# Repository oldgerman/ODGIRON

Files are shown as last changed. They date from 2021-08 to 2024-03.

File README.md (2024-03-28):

# ODGIRON

## 关于

> 这是一个很久以前的项目，也是我刚学习stm32做的第一个项目，仅给老友们发车了10个套件，现将其所有软硬件资料开源
>
> Github仓库链接：https://github.com/oldgerman/ODGIRON

开源USB-C PD T12电烙铁，基于HAL库开发，STM32CubeIDE + STM32CubeMX

固件从 [ironOS](https://github.com/Ralim/IronOS) 修改而来，运行FreeRTOS，更换了主控，重新设计了主界面和多级菜单，更大的oled显示屏，分辨率128x32

双面板设计，电阻电容最小0603封装，焊接难度比0402小

前期准备几乎兼容所有QFN48、RAM ≥ 20KB、FLASH ≥ 128KB 的STM32芯片，但后期发现 F103 固件写不下了遂停止维护，主力适配 F401，当然如果你有能力，可自行移植到其他型号上

## 技术大纲

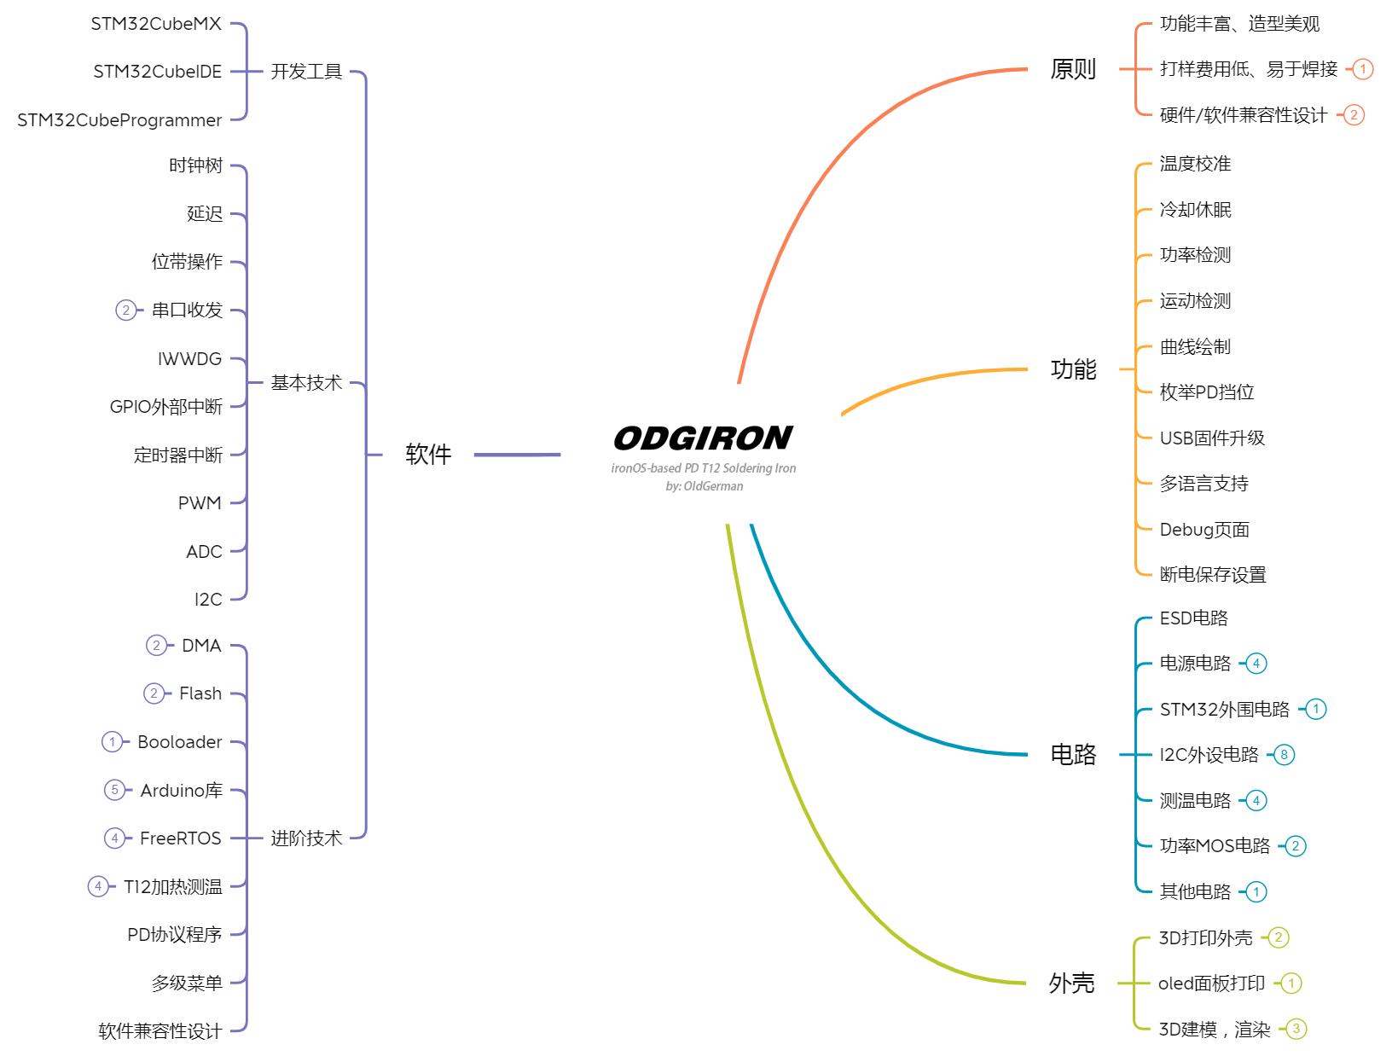
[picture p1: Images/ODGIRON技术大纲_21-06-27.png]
ODGIRON技术大纲_21-06-27


## 成品

ODGIRON（1）

## 硬件

### 配置

- 主控：STM32F103CBU6、STM32F401CCU6
- 屏幕：0.87inch OLED，SSD1316 分辨率128x32
- PD协议芯片：FUSB302B
- 加速度计：LIS3DH
- 功率计：INA226
- 电源管理：MP2456 + LDO 3.3V
- 温度测量：SGM8551 + MCP9700AT
- 功率MOS：AON7403（-30V/-29A）*2
- 外壳：尼龙3D打印

### PCB

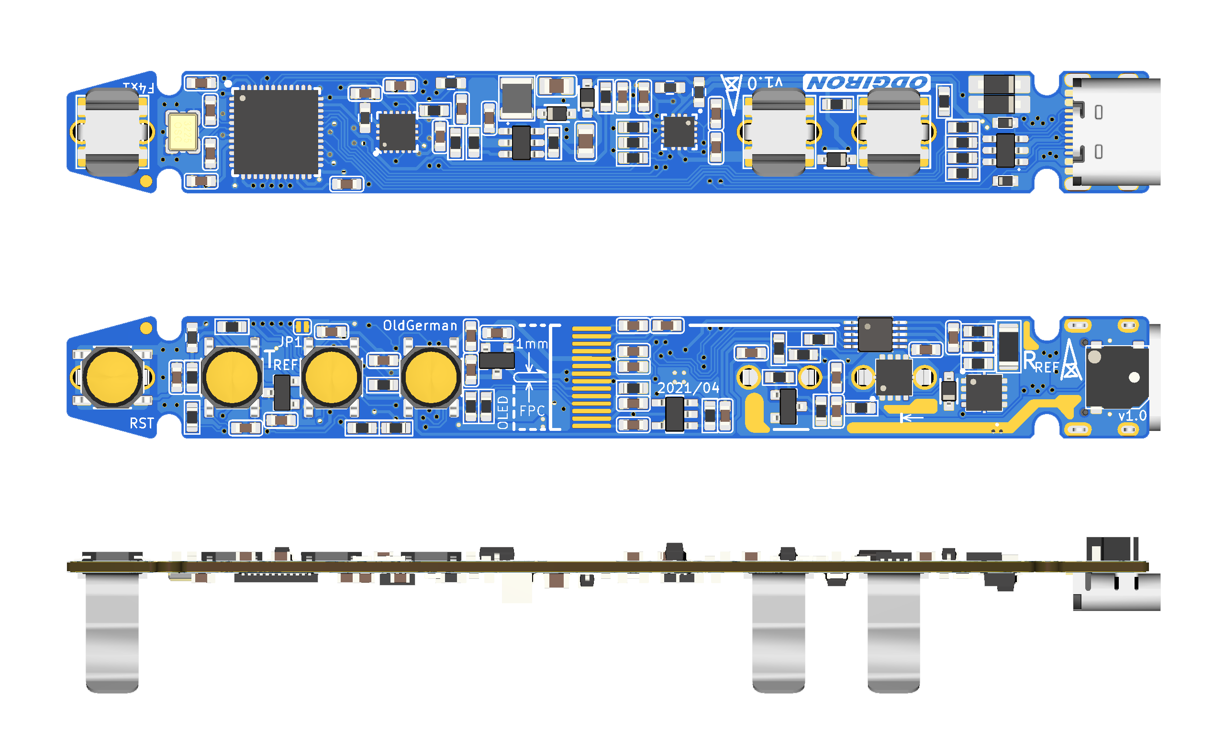
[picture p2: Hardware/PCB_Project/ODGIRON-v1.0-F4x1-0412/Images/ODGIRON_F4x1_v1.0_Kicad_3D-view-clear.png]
ODGIRON_F4x1_v1.0_Kicad_3D-view-clear


### 原理图

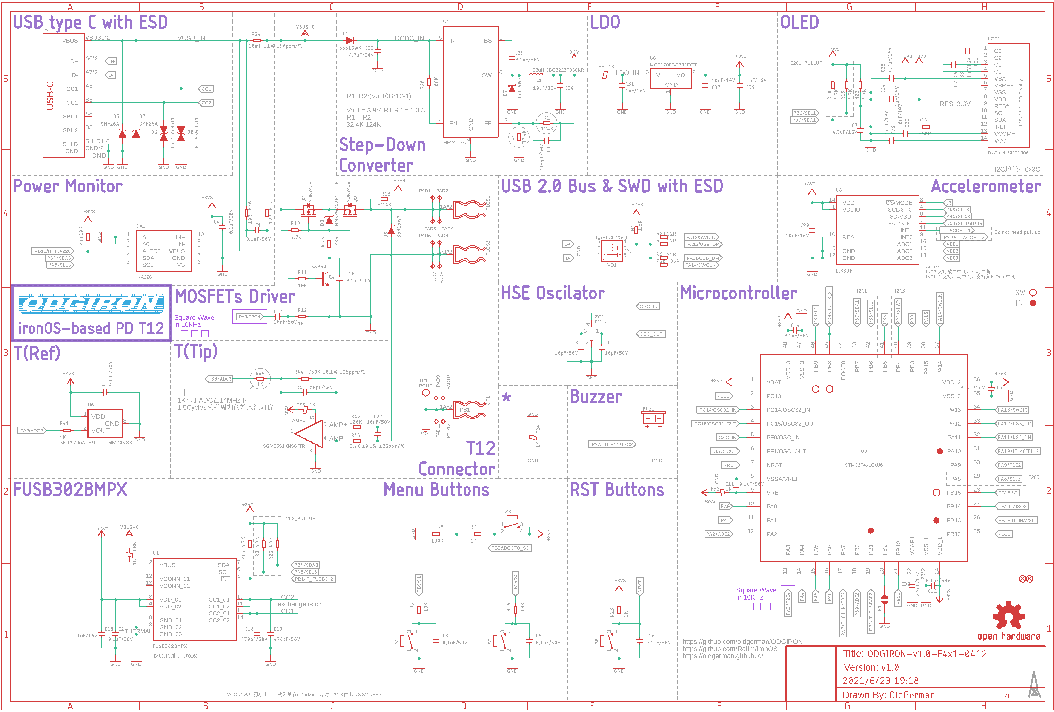
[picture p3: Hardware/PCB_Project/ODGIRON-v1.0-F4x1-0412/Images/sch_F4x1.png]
sch_F4x1


### 外壳

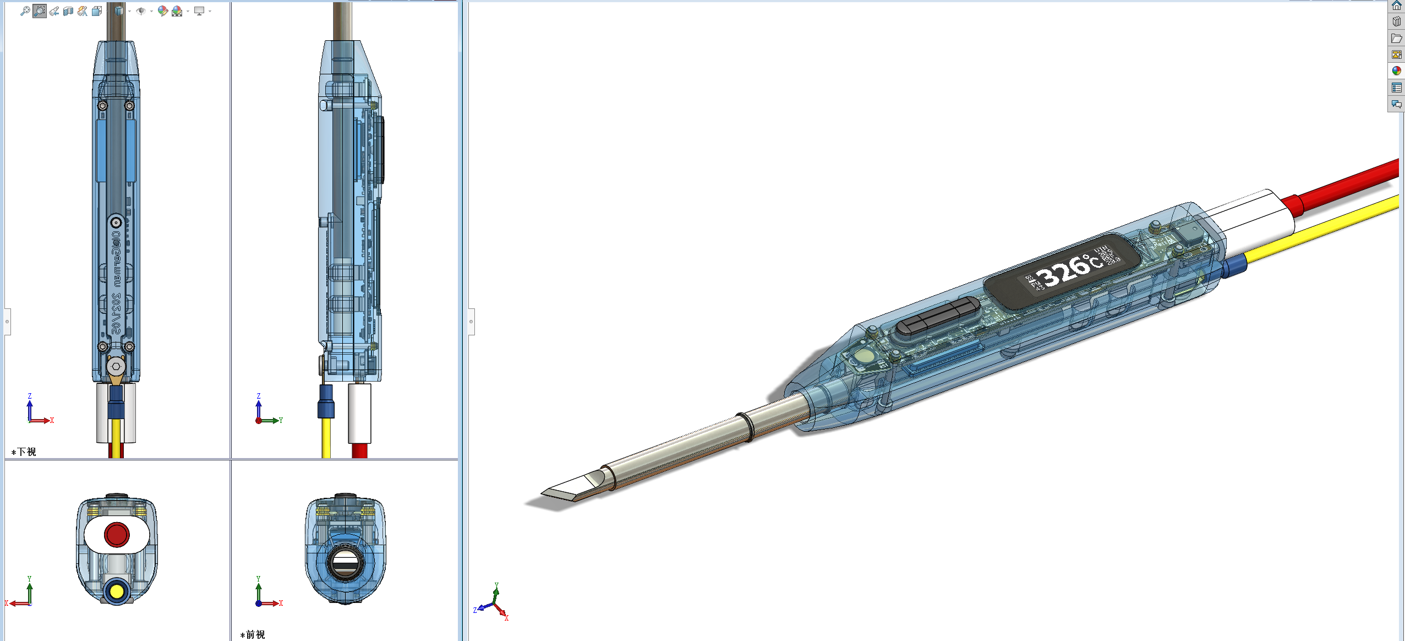
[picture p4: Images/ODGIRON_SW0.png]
ODGIRON_SW0


## 软件

[固件版本更新日志](https://github.com/oldgerman/ODGIRON/blob/master/Notes/firmware_logs.md)

[固件升级方法](https://github.com/oldgerman/ODGIRON/blob/master/Notes/firmware_upgrade.md)

### 功能

- :heavy_check_mark:功率计

- :heavy_check_mark:自动休眠、运动唤醒

- :heavy_check_mark:温度功率曲线绘制

- :heavy_check_mark:USB固件升级

- :heavy_check_mark:多级菜单（可配置的参数太多，只列举几个）

  - 温度校准
  - 冷却休眠
  - 枚举PD挡位
  - ...

- :heavy_check_mark:断电保存设置

- 待开发

  - 多语言支持（目前仅支持中文）

  - ...

### BUG

ADC注入通道测量尖端的温度：STM32F401CCU6偶尔会向上抖动10度，同样的代码在STM32F103CBU6跑却很稳定，可能是ADC时钟频率、采样周期、转换周期不同导致，目前整不好了，但影响不大:)

## 致谢

> 感谢[@Miniware](http://www.miniware.com.cn/)开源的[TS100资料](http://www.minidso.com/forum.php?mod=viewthread&tid=892)
>
> 感谢[@Ralim](https://github.com/Ralim)开发的[ironOS](https://github.com/Ralim/IronOS)
>
> 感谢[@olikraus](https://github.com/olikraus)开发的[u8g2](https://github.com/olikraus/u8g2)
>
> 感谢[@Zanduino](https://github.com/Zanduino)开发的[INA](https://github.com/Zanduino/INA)

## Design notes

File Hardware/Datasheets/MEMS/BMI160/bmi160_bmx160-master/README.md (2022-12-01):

# BMI160 / BMX160

## 简介

本软件包是为 BOSCH BMI160 6轴传感器以及 BMX160 9轴传感器提供的通用传感器驱动包。

本驱动软件包会检测所连接传感器的ID从而自动配置为BMI160或者BMX160的驱动，无须用户手动选择。

本文档介绍该软件包的基本功能和使用方法，本文主要内容如下：

- 传感器介绍
- 支持情况
- 使用说明

## 传感器介绍

BMI160 是 BOSCH（博世）公司专为可穿戴设备和 IOT 市场开发的一款超低功耗6轴传感器，尺寸小巧，内置加速计和陀螺仪。

BMX160 是 BOSCH（博世）公司专为可穿戴设备和 IOT 市场开发的一款超低功耗9轴传感器，内置加速计、陀螺仪和磁力计。

## 支持情况

| 包含设备 | 加速计 | 陀螺仪 | 磁力计 |
| --- | --- | --- | --- |
| **通讯接口** | | | |
| IIC | √ | √ | √ |
| SPI | | | |
| **工作模式** | | | |
| 轮询 | √ | √ | √ |
| 中断 | √ | √ | √ |
| FIFO | √ | √ | √ |
| **电源模式** | | | |
| 掉电 | √ | √ | √ |
| 低功耗 | √ | | √ |
| 普通 | √ | √ | √ |
| 高功耗 | | | |
| **数据输出速率** | √ | √ | √ |
| **测量范围** | √ | √ | |
| **自检** | | | |
| **多实例** | √ | √ | √ |

## 使用说明

### 依赖

- RT-Thread 4.0.0+
- Sensor 组件
- IIC 驱动：BMI160 / BMX160 设备使用 IIC 进行数据通讯，需要系统 IIC 驱动框架支持；

### 获取软件包

使用 BMI160/BMX160 软件包需要在 RT-Thread 的包管理中选中它，具体路径如下：

```
BMI160: BMI160 Digital 6-axis / BMX160 Digital 9-axis sensor
    [*]   Enable BMI160 / BMX160 accelerometer
    [*]   Enable BMI160 / BMX160 gyroscope
    [*]   Enable BMX160 magnetometer
        Version (latest)  --->
```

**Enable BMI160 accelerometer**： 配置开启加速度测量功能

**Enable BMI160 gyroscope**：配置开启陀螺仪功能

**Enable BMI160 magnetometer**：配置开启磁力计功能（只有BMX160支持磁力计）

**Version**：软件包版本选择

### 使用软件包

BMA400 软件包初始化函数如下所示：

```
int rt_hw_bmx160_init(const char *name, struct rt_sensor_config *cfg);
```

`rt_hw_bmx160_init`函数需要由用户调用，函数主要完成的功能有，

- 设备配置和初始化（根据传入的配置信息，配置接口设备和中断引脚）；
- 注册相应的传感器设备，完成 BMI160 / BMX160 设备的注册；

BMI160和BMX160共用一个驱动，当程序检测到传感器芯片ID为BMI160时会注册加速计和陀螺仪的驱动程序，如果ID为BMX160还会加载磁力计的驱动程序。如果你只需要某些特定的传感器，请到`menuconfig`菜单中进行配置。

#### 初始化示例

```
#include "sensor_bosch_bmx160.h"

int bmx160_port(void)
{
    struct rt_sensor_config cfg;
    cfg.intf.dev_name = "i2c1";
    cfg.intf.user_data = (void *)0x69;
    cfg.irq_pin.pin = GET_PIN(B, 0);
    cfg.irq_pin.mode = PIN_MODE_INPUT_PULLDOWN;
    rt_hw_bmx160_init("bmx160", &cfg);
    return 0;
}
INIT_APP_EXPORT(bmx160_port);
```

## 注意事项

暂无

## 联系人信息

维护人:

- [gztss](https://github.com/gztss)

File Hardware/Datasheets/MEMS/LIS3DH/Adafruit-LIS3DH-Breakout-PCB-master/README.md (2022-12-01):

## Adafruit LIS3DH Triple-Axis Accelerometer (+-2g/4g/8g/16g) PCB
<a href="http://www.adafruit.com/products/2809"><br/>
Click here to purchase one from the Adafruit shop</a>

The LIS3DH is a very popular low power triple-axis accelerometer. It's low-cost, but has just about every 'extra' you'd want in an accelerometer:

3.3V regulator + level shifting, so you can safely use with any Arduino or microcontroller without the need for an external level shifter!
We kept seeing this accelerometer in teardowns of commercial products and figured that if it's the most-commonly used accelerometer, its worth having a breakout board!

This sensor communicates over I2C or SPI (our library code supports both) so you can share it with a bunch of other sensors on the same I2C bus. There's an address selection pin so you can have two accelerometers share an I2C bus.

To get you going fast, we spun up a custom made PCB in the STEMMA QT form factor, making them easy to interface with. The STEMMA QT connectors on either side are compatible with the SparkFun Qwiic I2C connectors. This allows you to make solderless connections between your development board and the LIS331s or to chain them with a wide range of other sensors and accessories using a compatible cable. We’ve of course broken out all the pins to standard headers and added a voltage regulator and level shifting so allow you to use it with either 3.3V or 5V systems such as the Raspberry Pi + Feather series or Arduino Uno respectively.

PCB files for the Adafruit LIS3DH Breakout. The format is EagleCAD schematic and board layout
- https://www.adafruit.com/product/2809

### License

Adafruit invests time and resources providing this open source design, please support Adafruit and open-source hardware by purchasing products from [Adafruit](https://www.adafruit.com)!

All text above must be included in any redistribution

Designed by Limor Fried/Ladyada for Adafruit Industries.
Creative Commons Attribution/Share-Alike, all text above must be included in any redistribution. 
See license.txt for additional information.

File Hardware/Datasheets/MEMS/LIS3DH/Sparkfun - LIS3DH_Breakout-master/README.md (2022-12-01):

SparkFun Triple Axis Accelerometer Breakout - LIS3DH
=============================================

SparkFun Triple Axis Accelerometer Breakout - LIS3DH  

[*SparkFun Triple Axis Accelerometer Breakout - LIS3DH(SEN-13963)*](https://www.sparkfun.com/products/13963)

This breakout board makes it easy to use the tiny LIS3DH accelerometer in your project. 
The LIS3DH is a smart low-power, three-axis, capacitive micro-machined accelerometer with 12 bits of resolution.

This product replaced the MMA-8452Q.

Repository Contents
-------------------
* **/Hardware** - All Eagle design files (.brd, .sch)
* **/Libraries** - Libraries for use with the <PRODUCT NAME>
* **/Production** - Production panel files (.brd)

Documentation
--------------
* **[Library](https://github.com/sparkfun/SparkFun_LIS3DH_Arduino_Library)** - Arduino library.
* **[Hookup Guide](https://learn.sparkfun.com/tutorials/lis3dh-hookup-guide)** - Basic hookup guide.
* **[SparkFun Fritzing repo](https://github.com/sparkfun/Fritzing_Parts)** - Fritzing diagrams for SparkFun products.
* **[SparkFun 3D Model repo](https://github.com/sparkfun/3D_Models)** - 3D models of SparkFun products. 
* **[SparkFun Graphical Datasheets](https://github.com/sparkfun/Graphical_Datasheets)** -Graphical Datasheets for various SparkFun products.

Version History
---------------
* [V_0.1](https://github.com/sparkfun/LIS3DH_Breakout/tree/V_0.1) - Prototype
* [V_H1.0_L1.0.0](https://github.com/sparkfun/LIS3DH_Breakout/tree/V_H1.0_L1.0.0) - Hardware version 1.0, library version 1.0.0. 

License Information
-------------------

This product is _**open source**_! 

Please review the LICENSE.md file for license information. 

If you have any questions or concerns on licensing, please contact techsupport@sparkfun.com.

Distributed as-is; no warranty is given.

- Your friends at SparkFun.

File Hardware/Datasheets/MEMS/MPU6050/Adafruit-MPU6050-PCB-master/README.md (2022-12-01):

## Adafruit MPU6050 6-DoF Accelerometer and Gyro PCB

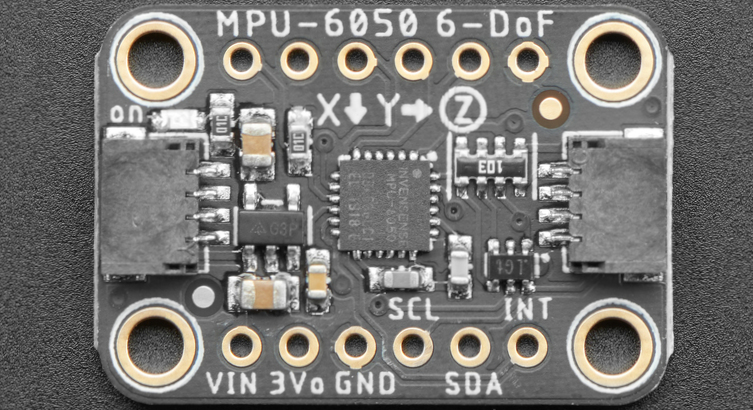
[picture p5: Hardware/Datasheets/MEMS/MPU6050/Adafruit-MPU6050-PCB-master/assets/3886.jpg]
<a href="http://www.adafruit.com/products/3886"><br/>
Click here to purchase one from the Adafruit shop</a>

PCB files for the Adafruit MPU6050 6-DoF Accelerometer and Gyro. 

Format is EagleCAD schematic and board layout
* https://www.adafruit.com/product/3886

### Description

The MPU-6050 is a popular six DoF accelerometer and gyroscope (gyro) that has all the info you need on how things are shakin' and spinnin' . With six axes of sensing and 16-bit measurements, you'll have everything you need to give your robot friend an inner ear.

This combination of gyroscopes and accelerometers is commonly referred to as an **I**nertial **M**easurement **U**nit or IMU. Not so long ago IMUs were the [size of a breadbox](http://mentalfloss.com/article/55835/how-big-breadbox) and cost upwards of **$50,000!** While you're not going to be using it to guide your mars rocket, the MPU-6050 is several orders of magnitude smaller and a bargain at a price three orders of magnitude less!  Now you can add telemetry to your [water rocket](https://en.wikipedia.org/wiki/Water_rocket) (with some waterproofing).

As with all Adafruit breakouts, we've done the work to make this handy temperature helper super easy to use. We've put it on a breakout board with the required support circuitry and connectors to make it easy to work with, and is now a trend we've added [SparkFun Qwiic](https://www.sparkfun.com/qwiic) compatible [STEMMA QT](https://learn.adafruit.com/introducing-adafruit-stemma-qt) JST SH connectors that allow you to get going without needing to solder. Just use a [STEMMA QT adapter cable](https://www.adafruit.com/product/4209), plug it into your favorite micro or Blinka supported SBC and you're ready to rock!

### License

Adafruit invests time and resources providing this open source design, please support Adafruit and open-source hardware by purchasing products from [Adafruit](https://www.adafruit.com)!

Designed by Bryan Siepert for Adafruit Industries.

Creative Commons Attribution/Share-Alike, all text above must be included in any redistribution. 
See license.txt for additional details.

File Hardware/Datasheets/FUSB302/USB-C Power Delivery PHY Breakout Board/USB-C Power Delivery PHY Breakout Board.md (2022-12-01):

# USB-C Power Delivery PHY Breakout Board

[FUSB302BGEVB：C型接口检测解决方案（FUSB302BGEVB）带tssop28 32位 128KB flash 32KB SRAM 50MHz主频位RISC MCU：PIC32MX250F128B-I/SS](https://www.terraelectronica.ru/rd/ONS/FUSB302BGEVB)

QC和PD是主流，特别是PD，后面应该会一统天下，我觉得这种私有协议别浪费时间研究

这个fusb302是不支持pd3.0对吧？手册好像没提

哦，找到了，是只有2.0

对，只支持2.0
你可以看FUSB307，今天问了价格和302基本一样，支持3.0

USB-C Power Delivery PHY Breakout Board 1

是否想使用新的USB Type-C连接器？您需要一个芯片来管理CC引脚。该板可让您使用I2C和中断线来执行所有必要的USB-C功能。该板的核心是Fairchild FUSB302，C型端口控制器和BMC PHY。您可以使用该芯片执行以下所有操作：
*确定插头方向（正常或反向）
*确定或公布C型功率水平（0.5 V，1.5、1.5或3.0 A时为5 V）
*使用BMC通信进行协商USB供电显式签约高达20 V和5 A（100 W功率）
*协商备用模式，以将Type-C连接器中的引脚复用用于其他目的

所有设计文件均可在GitHub上获得，并且是开源的。原理图，布局，gerber和示例代码在MIT风格的许可下可用。

你可以考虑FUSB307，支持PD3.0，问过价格比FUSB302贵1块钱，当然FUSB302对你来说也够用，PD3.0向下兼容

FUSB302 的目标用户为希望以较少的编程量实施 DRP/SRC/SNK USB Type-C 接头的系统设计人员。FUSB302 实现了 USB Type-C 检测，包括连接和定向。FUSB302 集成了 USB BMC 功率输送协议的物理层，可实现高达 100 W 的电源和角色互换。BMC PD 装置实现了对于符合 C 型规范的其他接口的完全支持。参考法规可用于 FUSB302 在若干嵌入控制器平台之间轻松实施 C 型 和 USB BMC 功率输送协议。单击下面的“软件”链接。

| 特性 | |
| :--- | ---- |
| | |
| 通过自主 DRP 切换实现双角色功能 | |
| 能够根据具体的连接，连接主机或设备。 | |
| 软件可配置为专用主机、专用设备或双角色 | |
| 专用设备可采用具有固定 CC 和 VCONN 通道的 Type-C 插座或 Type-C 插头运行。 | |
| 完全支持 Type-C 1.1。集成 CC 引脚的以下功能 | |
| 作为主机进行连接/断连检测 | |
| 作为主机进行电流性能指示 | |
| 作为设备进行电流性能检测 | |
| 音频适配器附件模式 | |
| 调试附件模式 | |
| 有源电缆检测 | |
| 将 CCx 集成到 VCONN 开关中，具有过流限制，支持 USB3.1 全功能数据线。 | |
| USB 电力传输 (PD) 2.0、版本 1.1 支持 | |
| 自动 GoodCRC 报文响应 | |
| 如果需要，自动软复位重新发送的报文 | |
| 如果未收到 GoodCRC，自动尝试重发报文 | |
| 电池电量耗尽支持（没有加电时的 SNK 模式支持） | |
| 自动硬复位发送的顺序集 | |
| 采用 9 焊球 WLCSP (1.215 mm x 1.260 mm) 和 14 引脚 MLP（2.5 mm x 2.5 mm，0.5 mm 节距）封装 | |
| 低功率运行：ICC = 25 μA（典型值） | |

| 应用                                                         |
| :----------------------------------------------------------- |
| This product is general usage and suitable for many different applications. |

### USB Type-C PD开发板

8个月前

- [电源模块](https://oshwhub.com/explore?filter=2613794836ff4fa2954e4cca5749584a)
- [方案验证板](https://oshwhub.com/explore?filter=90637fd096424071a21927e5cdc436de)
- [消费电子](https://oshwhub.com/explore?filter=e5831c441f25423d88a7311a9b276871)

简介：FUSB302B（C132291）控制器+INA226（C49851）电流检测，实现USB-PD协议，可以DIY线材检测器，充电器输出能力检测器等等。且集成了QC3.0手动诱骗电路，测试QC3.0功能

开源协议: GPL 3.0

https://oshwhub.com/wuziyue/USB-Type-C-PDkai-fa-ban

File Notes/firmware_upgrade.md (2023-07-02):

## 固件升级方法

### 【booloader】烧写

如果是全片擦除的芯片，那么请先用ST-LINK烧写“ODGIRON_bootloader_XXX.bin” ，这是booloader文件，只有烧进去了，才能用烙铁自带的USB Type-C口通过DFU升级APP文件，具体操作见下一步【APP】烧写

### 【APP】烧写

1. 安装Dfuse软件，ST的DFU驱动也要安装，win10系统请安装 “Dfuse文件安装路径/bin/Driver/Win7/X86”下的dpinst_x86.exe,[Dfuse下载链接](https://www.st.com/en/development-tools/stsw-stm32080.html)
2. 用USB将至少烧写了booloader程序的烙铁连接电脑，在启动的logo页面时，长按中键，可进入USB DFU升级模式的页面
3. 打开DfuseDemo软件，若检测到处于dfu模式的烙铁芯片，那么就查看“Product ID”栏内的数字，记下来
4. 用Dfuse软件安装时自带的小工具“Dfu file mananger”将“ODGIRON_APP_XXX.hex” 转成“*.dfu”文件升级，
   转之前先填刚才记下的“Product ID”，然后直接刷固件，升级之后请在菜单里 恢复出厂设置

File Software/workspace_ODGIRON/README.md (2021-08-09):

## 开发环境

本文件夹是使用STM32CubeIDE_1.7创建的workspace

使用Darkest Dark主题，未安装的STM32CubeIDE直接打开CDT编辑器的颜色会很奇怪，[推荐食用方式](https://blog.csdn.net/qq_42038029/article/details/99735688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)

## Link 文件夹路径丢失修复

由于本项目多个PROJECT_STM32XXX工程共用上级目录的源代码文件，而STM32CubeIDE似乎只能通过Link文件夹的方式让多个工程共享同一源代码文件，大家将本项目存放在自己电脑的位置又不一样，因此会存在Link 文件夹路径丢失无法正常编译的问题，解决方法如下：

打开代码PROJECT_STM32XXX工程文件夹下的.project文件，将字段`<location>`内的路径根据你实际存放的路径修改：

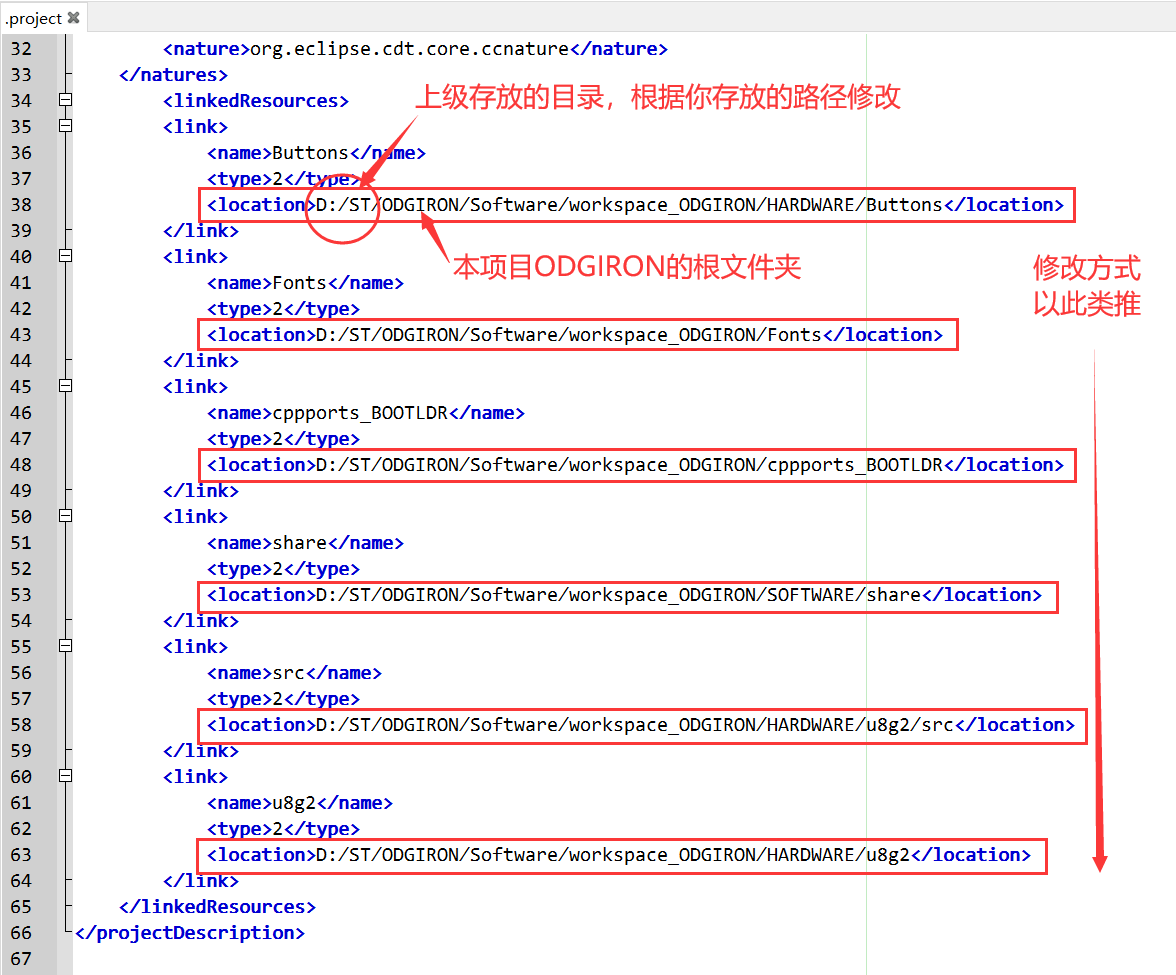
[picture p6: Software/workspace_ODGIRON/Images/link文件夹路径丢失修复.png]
link文件夹路径丢失修复


重新编译就OK了

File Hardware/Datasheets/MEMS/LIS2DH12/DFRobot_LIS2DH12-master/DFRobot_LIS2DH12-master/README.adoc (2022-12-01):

= DFRobot_LIS2DH12 Library for Arduino =

The library is used to read LIS2DH12 data via serial

/*!
 * @file testLIS2DH12.ino
 * @brief DFRobot's Read LIS2DH12 data
 * @n This example achieve receiving LIS2DH12  data via serial
 *
 * @copyright	[DFRobot](http://www.dfrobot.com), 2016
 * @copyright	GNU Lesser General Public License
 *
 * @author [Wuxiao](xiao.wu@dfrobot.com)
 * @version  V1.0
 * @date  2016-10-13
 * @https://github.com/DFRobot/DFRobot_LIS2DH12
 */

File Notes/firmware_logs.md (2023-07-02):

## 固件版本更新日志

> 由 过气德国佬 于 2022/04/27 18:01 最后一次编辑

### 日期：2022/04/27

#### APP部分固件更新

版本：ODGIRON_APP_2022-0427-1736.hex

新功能：

- 【温度控制】-->【温度失控保护】
  
  > 不论在<主页>、<曲线图页>、或是<菜单的校准页>涉及到加热时，当检测到烙铁温度长时间<低于>目标温度，会彻底关闭加热，这之后，只有在主页会显示“温度失控保护, 长按左右退出”的字样，可以长按左右键退出这个警告页面，继续正常加热。【温度失控保护】下有三个值可配置，分别是：启用失控保护（默认关闭）、温度失控阈值（默认10度）、触发保护时间（默认20秒）（之前的固件也有此功能但不可配置，只能重新上电才正常，而被怀疑是BUG）
  
- 【显示设置】-->【主页加热单位】

  > 对应主屏幕左下角的数字，之前是显示功率（单位是W但不打印），可以更改为 "瓦特"（W）或 "百分"（%），默认是瓦特。百分的范围是0~99%

### 日期：2022/04/24

#### APP部分固件更新
版本：ODGIRON_APP_2022-0424-1612.hex

新功能：

- 【温度校准】-->【设置目标温度】可开启或关闭，校准的目标温度支持调整

变化部分：

- 若【温度校准】-->【设置目标温度】关闭，则每个温度校准档位的目标温度是固定的默认值
- 若【温度校准】-->【设置目标温度】打开，则每个温度校准档位的目标温度是可调的，每次进入对应的温度校准档位都会显示目标温度调节页面（最低温度没有，因为是不加热的情况）。添加这个的原因的默认校准的最高目标温度是400度左右，对于一些娇贵的烙铁，这个温度容易挂掉，因此有必要将这个温度支持调低，然后其他档位也一并添加了目标温度可调的功能

### 日期：2022/04/04

> 此版本之后，APP固件更新不用捆绑升级DFU固件，解决DFU和APP的耦合

#### Bootloader部分固件更新
版本：ODGIRON_Booloader_2022-0404-1502.bin

变化部分：

- 插电之前，一直按住中键，再插电，才会进入DFU页面

#### APP部分固件更新

版本：ODGIRON_APP_2022-0404-1643.hex

修复的BUG：

- 【开机焊接】开启后，不起作用

- 菜单栏右侧的值不居中

新功能：

- 【显示设置】-->【开机显示图标】可开启或关闭

变化部分：

- 取消【辅助功能】-->【重启进入DFU】，但【重启】功能里选择OK后，依旧可以马上按中键进入DFU页面

### 日期：2022/04/03

#### Bootloader部分固件更新

版本：ODGIRON_Booloader_2022-0403-2222.bin

#### APP部分固件更新

版本：ODGIRON_APP_2022-0403-2222.hex

修复的BUG：

- 刷屏错位、乱码
- 温度稳定时突然升高
- 旧固件升级后，主界面温度一直为0，并持续最大功率加热

新功能：

- 【温控设置】

  > 其下级菜单有【比例系数】、【卡尔曼滤波器】、【目标温度正偏移】，这些值可以用默认值，也可自己调整

- 【温度校准】

  > 不受校准顺序影响，但最好从低温向高温校准，在每个温度档位的校准页面，可以用左右键调整校准的目标温度，按中键可退出温度档位校准，每个温度校准后，需要【保存校准数据】以计算校准的曲线，相关计算结果可在【查看校准数据】里查看，校准默认不开启，需要【启用校准数据】才会开启

变化部分：

- 菜单的按键操作发生了变化，长按左键返回上级菜单--变为--长按中键，
- 菜单新特性：支持菜单栏首尾循环，支持长按左键或右键快速递进

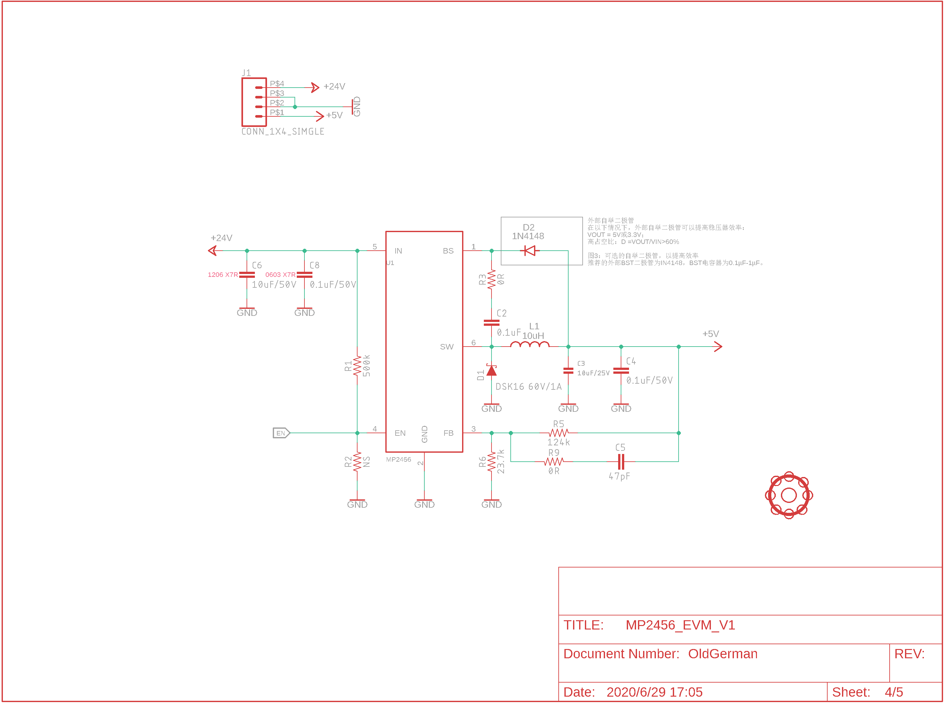
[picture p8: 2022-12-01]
Hardware/Datasheets/DCDC/image/Eagle_Sch.png

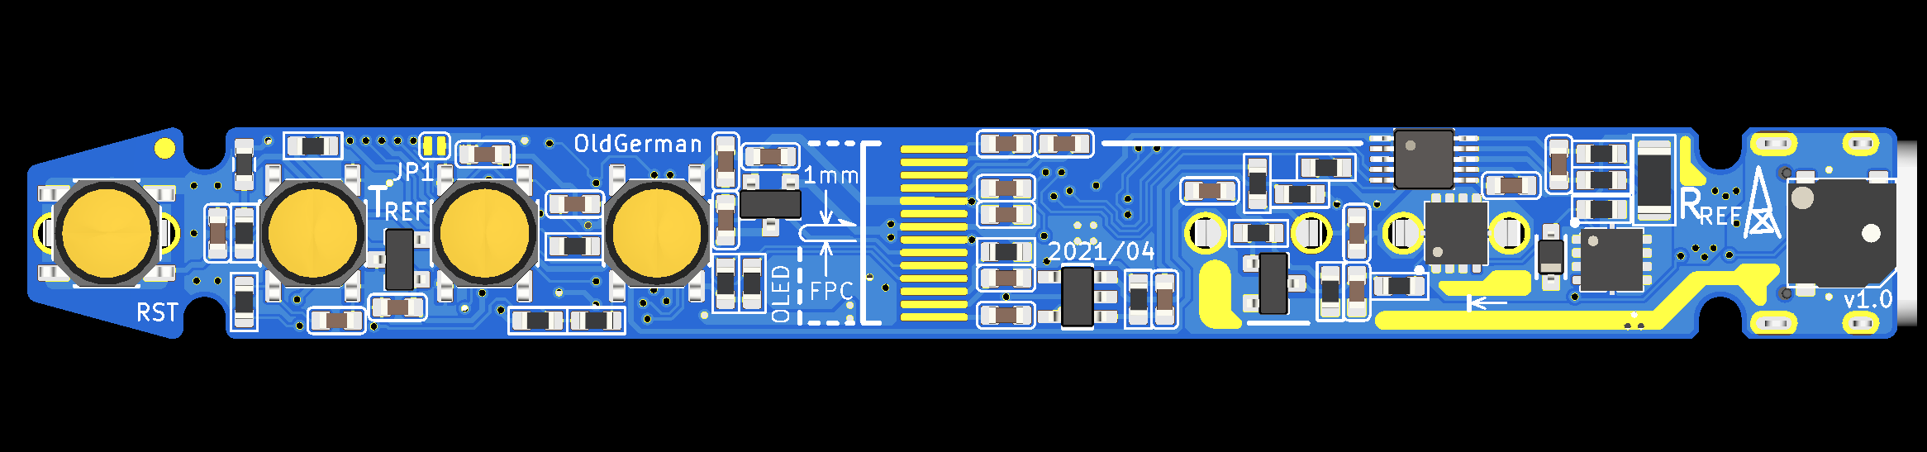
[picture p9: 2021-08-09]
Hardware/PCB_Project/ODGIRON-v1.0-F4x1-0412/Images/ODGIRON_F4x1_v1.0_Kicad_3D-view (5).png

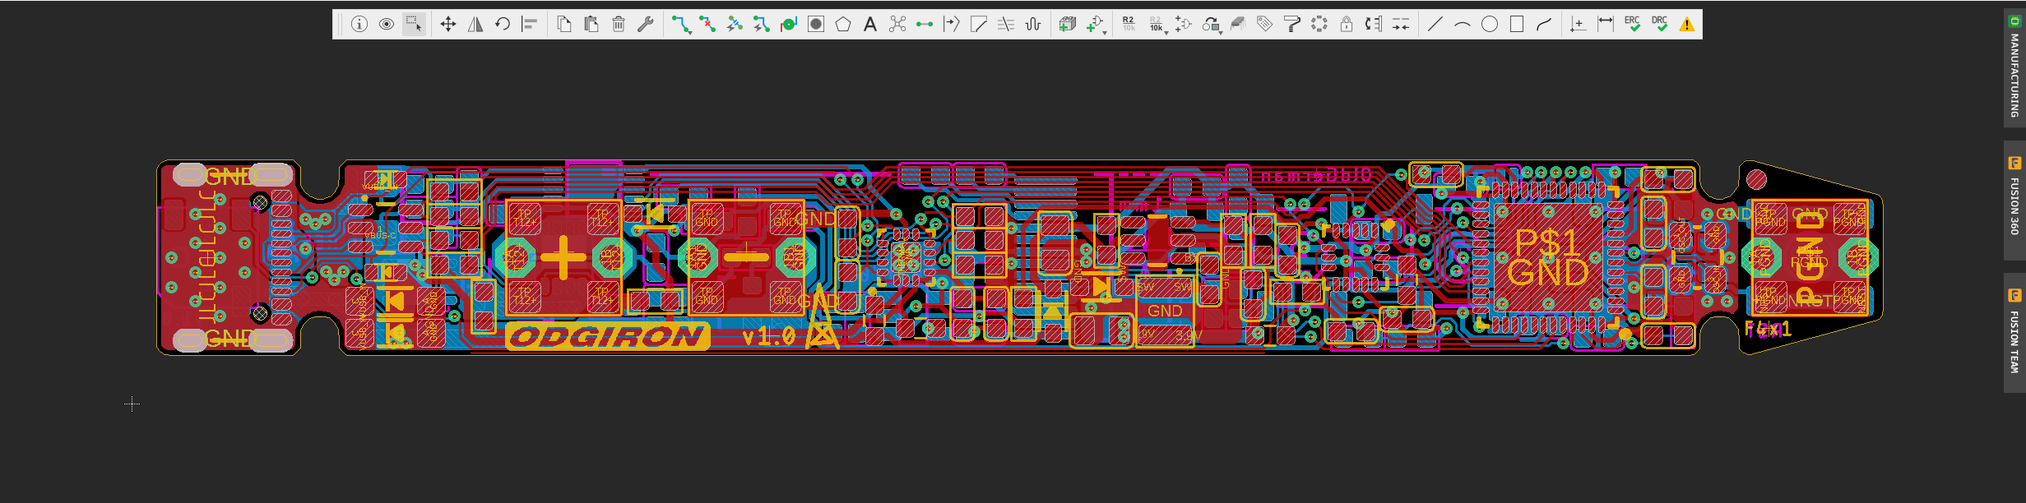
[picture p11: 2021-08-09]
Hardware/PCB_Project/ODGIRON-v1.0-F4x1-0412/Images/brd_F4x1.png

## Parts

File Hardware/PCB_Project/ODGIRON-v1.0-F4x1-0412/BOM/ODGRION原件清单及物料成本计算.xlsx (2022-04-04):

Type | Numbers | Detail | Package | Name | 最小起订量 | 起订量总价 | 单价 | 实际成本
精密低温漂电阻 | 1 | 10mR 1% 50ppm STE0805MW75R010F | R1206 | R24 | 10 | 3.27 | 0.327 | 0.327
 | 1 | 2.4K 0.1% 25ppm | R0603 | R43 | 20 | 2.6 | 0.13 | 0.13
 | 1 | 750K 0.1% 25ppm | R0603 | R44 | 20 | 2.6 | 0.13 | 0.13
1%电阻 | 2 | 10R | R0603 | R36, R37 | 100 | 1 | 0.01 | 0.02
 | 4 | 22R | R0603 | R5, R6, R27, R28 | 100 | 1 | 0.01 | 0.04
 | 5 | 1K | R0603 | R7, R12, R23, R41, R45 | 100 | 1 | 0.01 | 0.05
 | 1 | 1.5K | R0603 | R4 | 100 | 1 | 0.01 | 0.01
 | 8 | 4.7K | R0603 | R3, R10, R16, R18, R19, R22, R25, R35 | 100 | 1 | 0.01 | 0.08
 | 4 | 10K | R0603 | R9, R11, R14, R38 | 100 | 1 | 0.01 | 0.04
 | 1 | 26.1K | R0603 | R1 | 100 | 1 | 0.01 | 0.01
 | 4 | 100K | R0603 | R2, R8, R20, R42 | 100 | 1 | 0.01 | 0.04
 | 1 | 560K | R0603 | R17 | 100 | 1 | 0.01 | 0.01
磁珠/电感 | 5 | 1K | F0603 | FB1, FB2, FB3, FB4, FB5 | 50 | 1.5 | 0.03 | 0.15
 | 1 | 33uH CBC3225T330KR | SMD,3.2X2.5X2.5MM | L1 | 5 | 2.3 | 0.46 | 0.46
电容 | 2 | 10pF/50V | C0603 | C8, C9 | 50 | 1.7 | 0.034 | 0.068
 | 1 | 100pF/50V | C0603 | C34 | 50 | 1.7 | 0.034 | 0.034
 | 2 | 470pF/50V | C0603 | C18, C19 | 50 | 1.7 | 0.034 | 0.068
 | 2 | 10nF/50V | C0603 | C17, C27 | 50 | 1 | 0.02 | 0.04
 | 14 | 0.1uF/50V | C0603 | C1, C2, C3, C4, C5, C6, C10, C11, C12, C13, C14, C16, C28, C29 | 50 | 1.3 | 0.026 | 0.364
 | 6 | 1uF/16V | C0603 | C15, C21, C22, C24, C31, C39 | 50 | 1.7 | 0.034 | 0.204
 | 1 | 2.2uF/16V | C0603 | C32 | 50 | 3.1 | 0.062 | 0.062
 | 2 | 4.7uF/10V | C0603 | C7, C23 | 50 | 2 | 0.04 | 0.08
 | 4 | 10uF/10V | C0603 | C20, C25, C26, C37 | 50 | 3.8 | 0.076 | 0.304
 | 1 | 4.7uF/50V | C0805 | C33 | 10 | 2.7 | 0.27 | 0.27
 | 1 | 10uF/25V | C0805 | C30 | 20 | 2.5 | 0.125 | 0.125
分立半导体 | 2 | ESD5B5.0ST1，ON(安森美) | SOD-523 | D6, D8 | 20 | 3.2 | 0.16 | 0.32
 | 2 | SMF24A，MDD(江苏辰达行电子) | SOD-123 | D2, D5 | 20 | 4.3 | 0.215 | 0.43
 | 1 | USBLC6-2SC6，ST(意法半导体) | SOT23-6 | VD1 | 5 | 2.6 | 0.52 | 0.52
 | 4 | B5819WS，MDD(江苏辰达行电子) | SOD-323 | D1, D4, D7, D9 | 20 | 2.4 | 0.12 | 0.48
 | 1 | MMSZ5242BS-7-F，DIODES(美台) | SOD-323 | D3 | 20 | 3 | 0.15 | 0.15
 | 1 | S8050， CJ(江苏长电) | SOT23-3 | Q4 | 20 | 2.5 | 0.125 | 0.125
 | 2 | AON7403 | DFN8P-0.65-3X3X0.8MM | Q2, Q3 | 1 | 1.2 | 1.2 | 2.4
集成半导体 | 1 | MCP1700T-3302E/TT（ME6206A33XG） | SOT23-3 | U6 | 10 | 2.58 | 0.258 | 0.258
 | 1 | MCP9700AT-E/TT | SOT23-3@1 | U5 | 1 | 1.35 | 1.35 | 1.35
 | 1 | MP2456GJ | SOT23-6 | U4 | 1 | 4.2 | 4.2 | 4.2
 | 1 | SGM8551XN5G/TR | SOT23-5 | AMP1 | 1 | 2.95 | 2.95 | 2.95
 | 1 | FUSB302BMPX | QFN14-2.5X2.5MM | U1 | 1 | 3 | 3 | 3
 | 1 | INA226 | MSOP10 | DA1 | 1 | 4 | 4 | 4
 | 1 | LIS3DH | LGA-16-3X3 | U8 | 1 | 2.6 | 2.6 | 2.6
 | 1 | STM32F4x1CxU6 拆机真香 | QFN48_7X7MM_0.5MM | U3 | 1 | 5 | 5 | 5
杂项 | 1 | 0.87inch SSD1306 | 0.87INCH_128X32_OLED_SSD1306 | LCD1 | 1 | 5.1 | 5.1 | 5.1
 | 1 | 8MHz | 3.2X2.5_KX-7 | ZO1 | 1 | 0.9 | 0.9 | 0.9
 | 1 |  | USB-C-16P | J3 | 1 | 0.5 | 0.5 | 0.5
 | 4 | 4*4*0.8mm薄膜开关 | TACTILE_SWITCH_SMD | S1, S2, S3, S5 | 10 | 0.8 | 0.08 | 0.32
 | 1 | 5020 蜂鸣器 | BUZZER_5020 | BUZ1 | 1 | 1.5 | 1.5 | 1.5
 | 3 | 5x20mm FUSE_CLIPS 保险丝座 |  |  | 50 | 2.5 | 0.05 | 0.15
合计：电子元件 | 107 |  |  |  |  | 100.65 |  | 39.369
 | 元件数量 |  |  |  |  | 只做一件 |  | 批量平均 | (不含邮费)
PCB | 1 | JLC |  |  | 5 | 5 | 1 | 1
激光钢网 | 1 | 10x10cm 小钢片 宝钢电子 |  |  | 1 | 25 | 25 | N/A
外壳 | 1 | 三维猴 惠普PA12尼龙3D打印 |  |  | 1 | 40 | 40 | 40
oled亚克力面板 | 1 | 立创商城0.8mm亚克力面板打印 |  |  | 10 | 35 | 3.5 | 3.5
接地黄铜片 | 1 | 接地PCB件（与PCB拼版了） |  |  | 5 | 0 | 0 | 0
五金 | 1 | m3不锈钢光身弹簧波珠 |  |  | 1 | 1.14 | 1.14 | 1.14
 | 4 | m1.6x1.5x2.5土字滚花注塑螺母 |  |  | 50 | 3.15 | 0.063 | 0.252
 | 4 | m1.6x14 304不锈钢杯头螺栓 |  |  | 20 | 2.94 | 0.147 | 0.588
 | 1 | m1.6x3 304不锈钢十字圆头螺丝 |  |  | 50 | 1.76 | 0.0352 | 0.0352
 | 1 | m3x1.7x5.3 304不锈钢薄型四方螺母 |  |  | 20 | 1.96 | 0.098 | 0.098
 | 1 | m3x6 304圆头内六角螺丝 |  |  | 100 | 2.75 | 0.0275 | 0.0275
合计：PCB及外壳 |  |  |  |  |  | 118.7 |  | 46.6407 | (锡膏自备)
 |  |  |  |  |  | 只做一件 |  | 批量平均 | (不含邮费)

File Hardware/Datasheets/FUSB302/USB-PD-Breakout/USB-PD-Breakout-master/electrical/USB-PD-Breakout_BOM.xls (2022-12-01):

Item # | Quantity | Reference | Type | Footprint | Manufacturer | Manufacturer Part Number | Supplier 1 | Supplier 1 Part Number
5 | 1 | C1 | SMD | Capacitors_SMD:C_1206 | Samsung Electro-Mechanics | CL31A106KAHNNNE | Digikey | 1276-1075-1-ND
6 | 2 | C2, C4 | SMD | Capacitors_SMD:C_0603 | Samsung Electro-Mechanics | CL10B104KB8NNNC | Digikey | 1276-1000-1-ND
7 | 1 | C3 | SMD | Capacitors_SMD:C_0805 | Samsung Electro-Mechanics | CL21B105KOFNNNG | Digikey | 1276-6471-1-ND
1 | 2 | C5, C6 | SMD | Capacitors_SMD:C_0603 | Yageo | CC0603KRX7R9BB471 | Digikey | 311-1078-1-ND
2 | 1 | J1 | SMD | Reclaimer_Labs:USB-C_Female_105450-0101 | Molex | 1054500101 | Digikey | WM12856CT-ND
8 | 1 | J2 | SMD | Reclaimer_Labs:USB_Micro-B_10118193 | Amphenol ICC (FCI) | 10118193-0001LF | Digikey | 609-4616-1-ND
9 | 1 | J3 | Thru-hole | Socket_Strips:Socket_Strip_Straight_2x03 | Amphenol ICC (FCI) | 67997-206HLF | Digikey | 609-3234-ND
10 | 1 | J4 | Thru-hole | Socket_Strips:Socket_Strip_Straight_1x08 | Amphenol ICC (FCI) | 77311-818-08LF | Digikey | 609-5130-ND
4 | 3 | R1, R2, R3 | SMD | Capacitors_SMD:C_0603 | Yageo | RC0603FR-074K7L | Digikey | 311-4.70KHRCT-ND
3 | 1 | U1 | SMD | Reclaimer_Labs:MLP_14 | ON Semiconductor | FUSB302BMPX | Digikey | FUSB302BMPXCT-ND

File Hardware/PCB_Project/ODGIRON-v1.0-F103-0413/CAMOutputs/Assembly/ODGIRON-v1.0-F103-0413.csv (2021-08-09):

Qty | Value | Device | Package | Parts | Description | MF | MPN | OC_FARNELL | OC_NEWARK | POPULARITY | PROD_ID | SF_ID | TP_SIGNAL_NAME | VALUE
1 |  | BUZZERBUZZER_5020 | BUZZER_5020 | BUZ1
1 |  | FUSE_CLIPS_01 | FUSE_CLIPS_01 | CP1 | FUSE |  |  |  |  | 1
1 |  | HAKKO_T12_K-TYPE_WITH_FUSE_CLIPS_X2 | HAKKO_T12_K-TYPE_WITH_FUSE_CLIPS_X2 | T1
4 |  | TAC_SWITCHSMD | TACTILE_SWITCH_SMD | S1, S2, S3, S5 | Momentary Switch
1 |  | USB_C_LONG-SYMBOL2-LAYER | USB-C-16P | J3 | USB Type C 16Pin Connector |  |  |  |  |  | CONN-14122
13 | 0.1uF/50V | SEEED_CAP-0603 | C0603 | C1, C2, C3, C4, C5, C6, C10, C11, C12, C13, C14, C16, C29 | Ceramic Capacitors
1 | 0.87inch SSD1316 | 0.87INCH_OLED_128X32_SSD1306 | 0.87INCH_128X32_OLED_SSD1306 | LCD1 | 128x32 I2C 0.91 Monochrome OLED Display"
1 | 1.5K | SEEED_RES-0603 | R0603 | R4
3 | 100K | SEEED_RES-0603 | R0603 | R8, R20, R42
1 | 100pF | SEEED_CAP-0603 | C0603 | C32 | Ceramic Capacitors
1 | 100pF/50V | SEEED_CAP-0603 | C0603 | C34 | Ceramic Capacitors
4 | 10K | SEEED_RES-0603 | R0603 | R9, R11, R14, R38
2 | 10R | SEEED_RES-0603 | R0603 | R36, R37
1 | 10mR ±1% ±50ppm/°C | SEEED_RES-1206 | R1206 | R24
2 | 10nF/50V | SEEED_CAP-0603 | C0603 | C17, C27 | Ceramic Capacitors
2 | 10pF/50V | SEEED_CAP-0603 | C0603 | C8, C9 | Ceramic Capacitors
4 | 10uF/10V | SEEED_CAP-0603 | C0603 | C20, C25, C26, C37 | Ceramic Capacitors
1 | 10uF/25V | SEEED_CAP-0805 | C0805 | C30 | Ceramic Capacitors
1 | 124K | SEEED_RES-0603 | R0603 | R2
5 | 1K | FERRITE-BEAD-0603 | F0603 | FB1, FB2, FB3, FB4, FB5
5 | 1K | SEEED_RES-0603 | R0603 | R7, R12, R23, R41, R45
6 | 1uF/16V | SEEED_CAP-0603 | C0603 | C15, C21, C22, C24, C31, C39 | Ceramic Capacitors
1 | 2.37K ±0.1% ±25ppm/℃ | SEEED_RES-0603 | R0603 | R43
4 | 22R | SEEED_RES-0603 | R0603 | R5, R6, R27, R28
2 | 32.4K | SEEED_RES-0603 | R0603 | R1, R13
1 | 33uH CBC3225T330KR | INDUCTOR3225 | SMD,3.2X2.5X2.5MM | L1
8 | 4.7K | SEEED_RES-0603 | R0603 | R3, R10, R16, R18, R19, R22, R25, R35
2 | 4.7uF/10V | SEEED_CAP-0603 | C0603 | C7, C23 | Ceramic Capacitors
1 | 4.7uF/50V | SEEED_CAP-0805 | C0805 | C33 | Ceramic Capacitors
2 | 470pF/50V | SEEED_CAP-0603 | C0603 | C18, C19 | Ceramic Capacitors
1 | 560K | SEEED_RES-0603 | R0603 | R17
1 | 600mA/40V | TRANS_NPN-MMBT2222AL | SOT23-3 | Q4 | NPN transistor |  |  |  |  |  | TRANS-08049 |  |  | 600mA/40V
1 | 750K ±0.1% ±25ppm/℃ | SEEED_RES-0603 | R0603 | R44
1 | 8MHz | 3225_CRYSTALL | 3.2X2.5_KX-7 | ZO1
2 | AON7403 | MOSFET-P-AON7403 | DFN8P-0.65-3X3X0.8MM | Q2, Q3
3 | B5819WS | DIODE_SCHOTTKYSOD323 | SOD-323 | D1, D7, D9
2 | ESD5B5.0ST1 | DIODE-TVS_BI−DIRECTIONALSOD-523 | SOD-523 | D6, D8
2 | FIDUCIAL | FIDUCIAL | FIDUCIAL_1MM | FID1, FID2 | Fiducial Alignment Points
1 | FUSB302BMPX | FUSB302 | QFN14-2.5X2.5MM | U1 | Espressif ESP8266 WiFi/Microcontroller SoC |  |  |  |  |  | IC-12452
1 | INA226 | INA226 | MSOP10 | DA1 | Lithium-Polymer/Lithium-Ion Battery Charger [Part No.]
1 | LIS3DH | LIS3DH | LGA-16-3X3 | U8 | ST Microelectronics LIS3DH 3-Axis +/-2/4/8/16g SPI/I2C Accelerometer |  |  |  |  |  | IC-13419 | N/A
1 | MCP1700T-3302E/TT | MCP1700 | SOT23-3 | U6
1 | MCP9700AT-E/TT | MCP9700 | SOT23-3@1 | U5
1 | MMSZ5242BS-7-F | DIODE_ZENERSOD-323 | SOD-323 | D3
1 | MP2456GJ | MP2456 | SOT23-6 | U4
1 | OSHW-LOGONO_SILK | OSHW-LOGONO_SILK | DUMMY | LOGO1 | Open-Source Hardware (OSHW) Logo
12 | PADTP16SQ | PADTP16SQ | TP16SQ | PAD1, PAD2, PAD3, PAD4, PAD5, PAD6, PAD7, PAD8, PAD9, PAD10, PAD11, PAD12 | Test pad |  |  |  |  | 0
1 | PGND | TESTPOINTROUND2MM | TESTPOINT_ROUND_2MM | TP1 | Test Point
1 | SGM8551XN5G/TR | AMP_SIMGLEN | SOT23-5 | AMP1 | Rail-to-Rail Operational Amplifiers |  | OPA340NA/3KG4 | 1234805 | 13M5177 | 0
2 | SMF24A | DIODE-TVS_UNIDIRECTIONALSOD-123 | SOD-123 | D2, D5
1 | STM32F103CBU6 | STM32F1_QFN48 | QFN48_7X7MM_0.5MM | U3
1 | SWO | TEST-POINT3 | PAD.03X.03 | TP5 | SparkFun Test Points
1 | USBLC6-2SC6 | USBLC6-2SOT23-6 | SOT23-6 | VD1

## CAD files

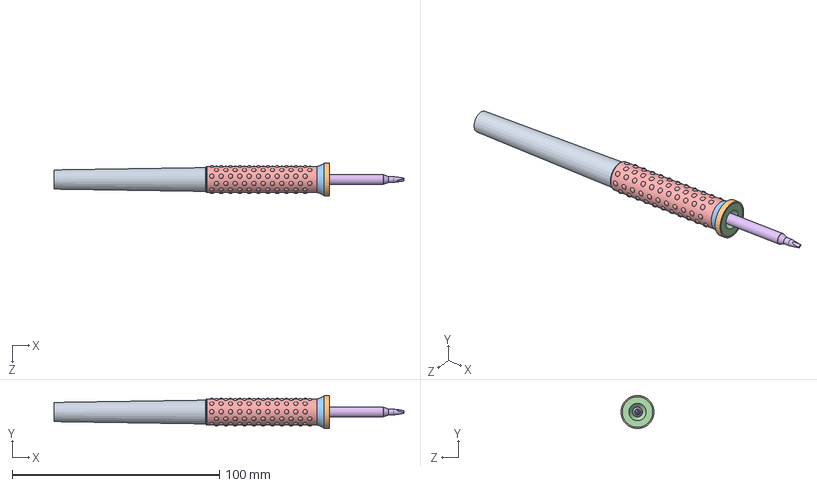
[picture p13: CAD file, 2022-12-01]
Hardware/SW_Project/20210510_SW/T12手柄/metcal_handle.SLDASM
168.8 x 16.0 x 16.0 mm
handle_bottom
handle_top
rubber_grip
plastic_insert
rubber_grip_bumps
sttc_037_tip

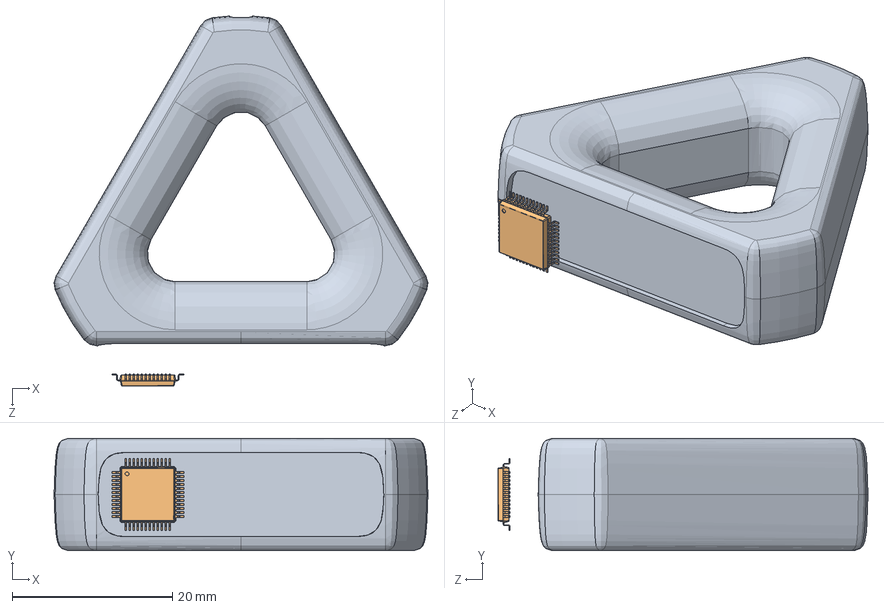
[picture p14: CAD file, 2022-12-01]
Hardware/PCB_Project/HAKKO_191-212/装配体1.SLDASM
46.7 x 14.0 x 46.2 mm
造型1
LQFP-48_7x7mm_P0.5mm

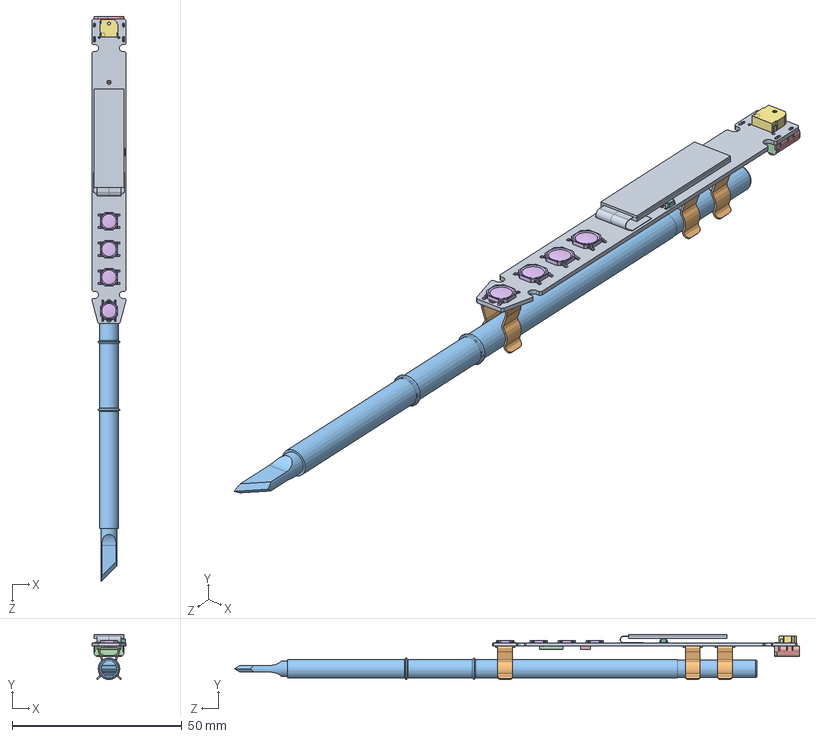
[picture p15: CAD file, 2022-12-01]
Hardware/SW_Project/20210208_SW/PCB装配体.SLDASM
10.2 x 13.3 x 166.6 mm
0322-PCB基板
ConPins
PcbPins
Mold
Frame
TactileButton(5mm)_SMD x 4
BUZZER_offset_5.2X5.2X2.0MM
SOT23-5
保险丝座 x 3
T12-K Hakko
TB67S289FTG P-VQFN48-0707-0.50-004
LGA-16_3x3mm_P0.5mm

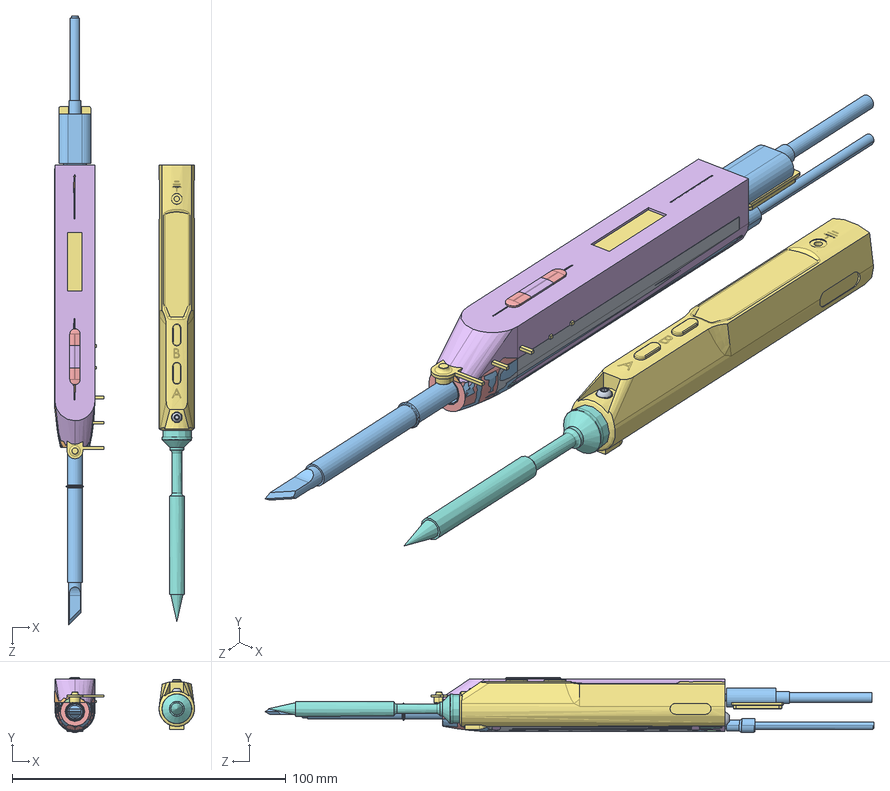
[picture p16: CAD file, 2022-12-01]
Hardware/SW_Project/20210510_SW/1223-all-装配体.SLDASM
51.2 x 20.2 x 222.5 mm
0322-PCB基板
ConPins
PcbPins
Mold
Frame
TactileButton(5mm)_SMD x 4
BUZZER_offset_5.2X5.2X2.0MM
SOT23-5
0.91_oled
保险丝座 x 3
T12-K Hakko
TB67S289FTG P-VQFN48-0707-0.50-004
LGA-16_3x3mm_P0.5mm
平台阶定位珠-行程0.55mm
m1.6x2.5x1.5热熔土字螺母 x 4
m1.6x14_杯头螺丝 x 4
1223-上壳-钢化膜
One Plus Type C
0326-下壳合并件
0326-下壳-扣除 -0403
M3x5.3x1.7薄四角螺母
接地PCB件_0407
m3x8不锈钢平头内六角螺丝
0510-上壳-开关-两边按钮 x 2
0510-上壳-开关-中间按钮
3.2mm开口冷压端子
1223-固定片_stm32f103厚封装

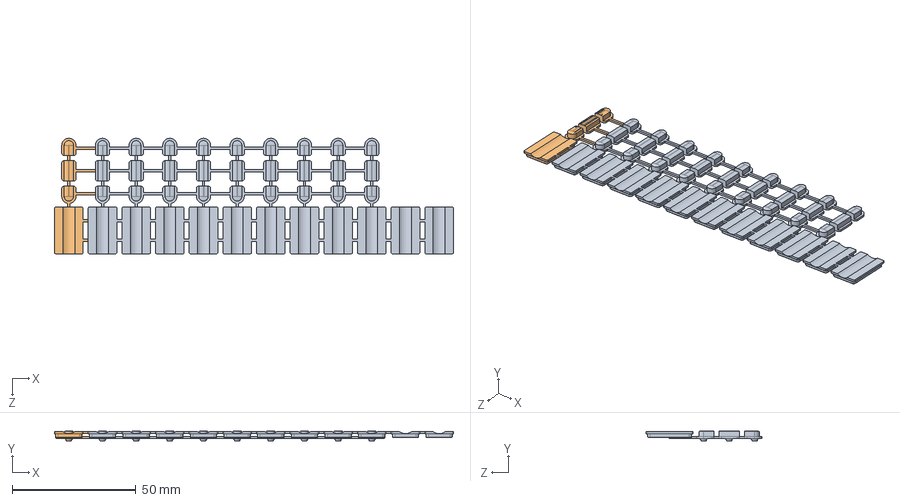
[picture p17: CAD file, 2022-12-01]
Hardware/SW_Project/20210510_SW/UFQFN48-拼接.SLDASM
161.2 x 4.15 x 46.7 mm

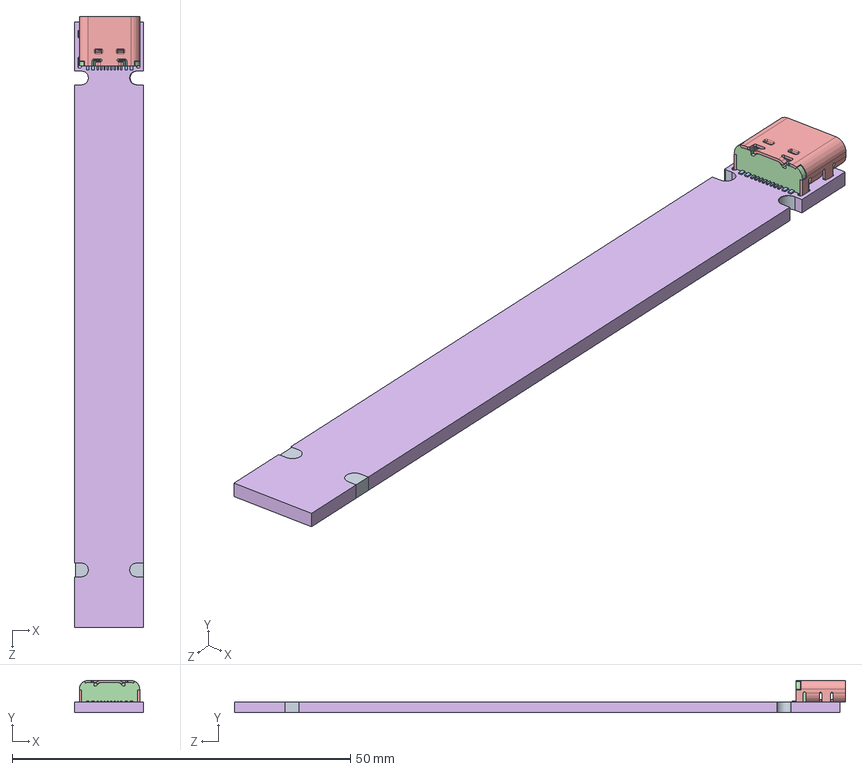
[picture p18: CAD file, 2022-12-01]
Hardware/SW_Project/20210510_SW/ODG_T12_PCB推敲.SLDASM
10.2 x 4.76 x 90.4 mm
ConPins
PcbPins
Mold
Frame
PCB_1206

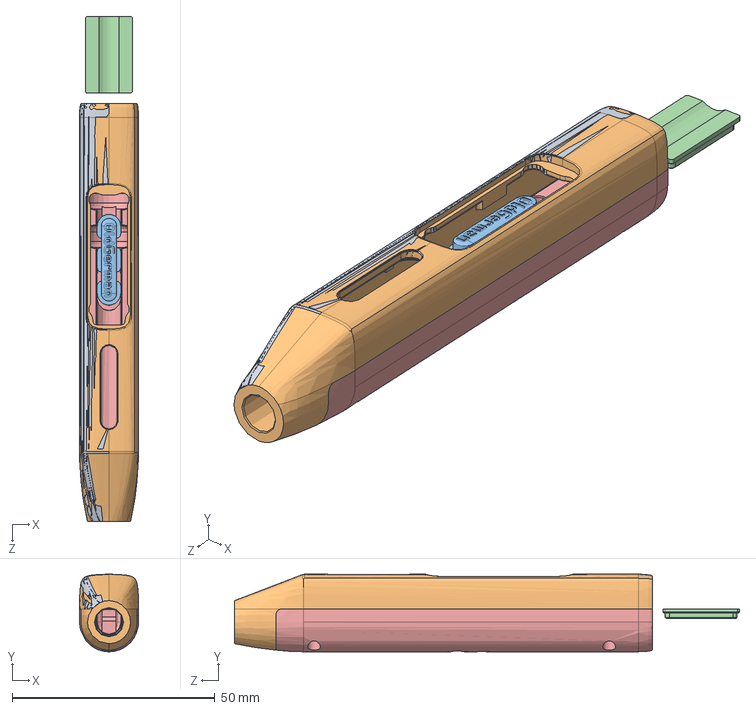
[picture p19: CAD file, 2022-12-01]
Hardware/SW_Project/20210510_SW/0326-合并.SLDASM
14.6 x 19.1 x 124.5 mm

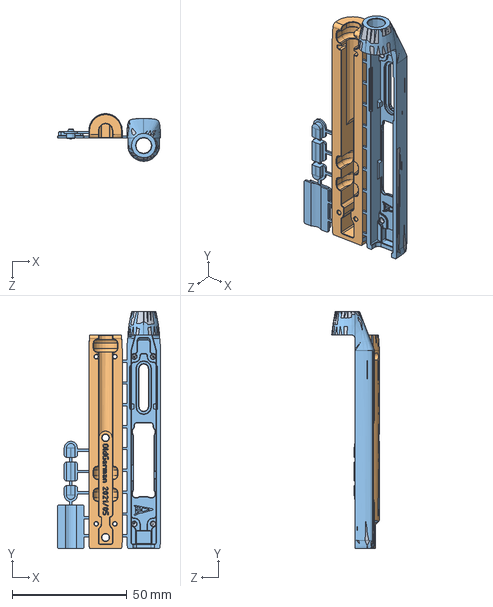
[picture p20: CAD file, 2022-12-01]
Hardware/SW_Project/20210510_SW/套件.SLDASM
44.8 x 103.1 x 20.8 mm

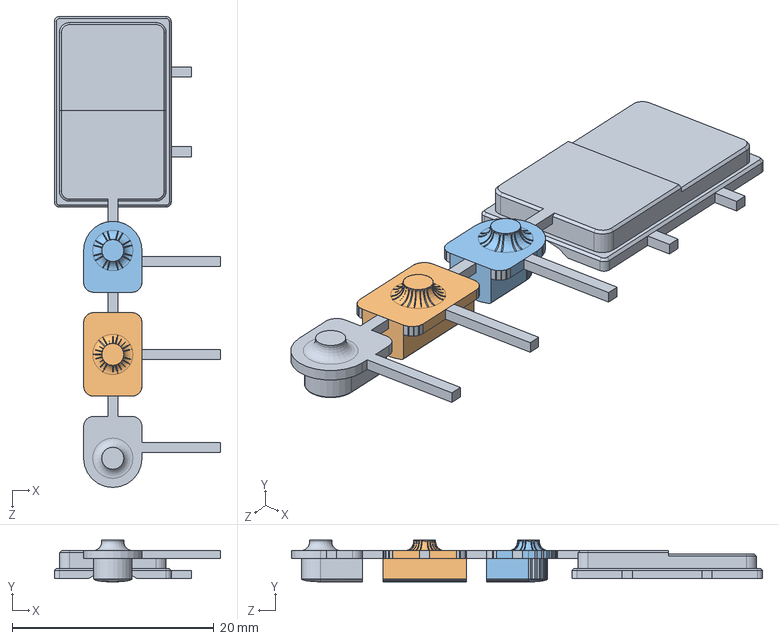
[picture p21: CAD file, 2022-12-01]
Hardware/SW_Project/20210510_SW/挡板+按钮.SLDASM
16.5 x 4.15 x 46.7 mm

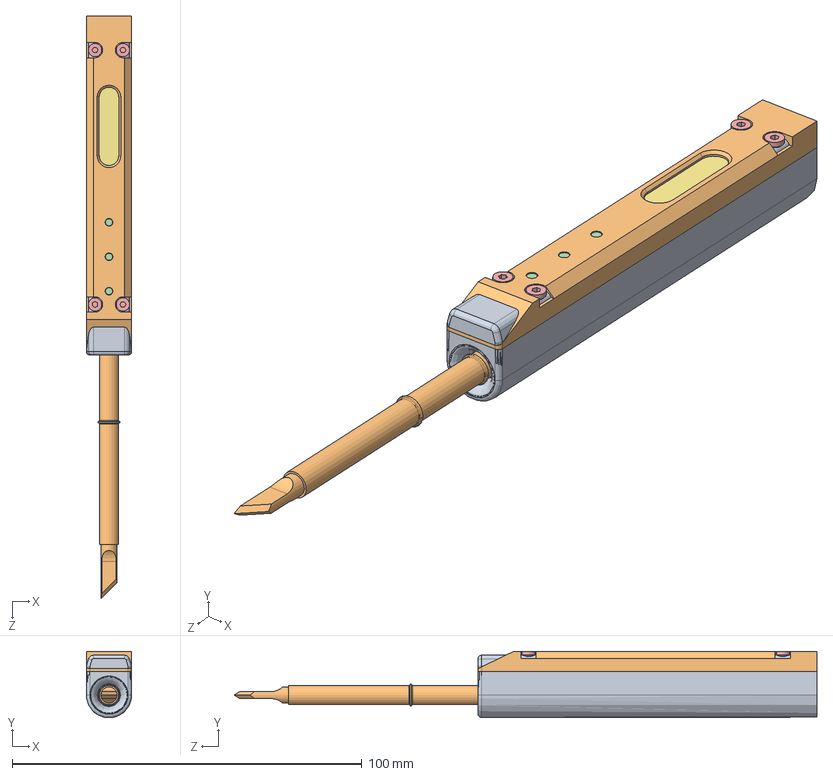
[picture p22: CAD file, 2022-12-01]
Hardware/SW_Project/20210510_SW/ODG_T12_外壳推敲.SLDASM
13.0 x 18.9 x 166.8 mm
T12-K Hakko
ConPins
PcbPins
Mold
Frame
PCB_1206
ODG_TS100外壳-下壳推敲
ODG_TS100外壳-上壳推敲
m2x3x2.5热熔土字螺母 x 2
TactileButton(5mm)_SMD x 3
m2x8沉头内六角 x 4
0.91_oled

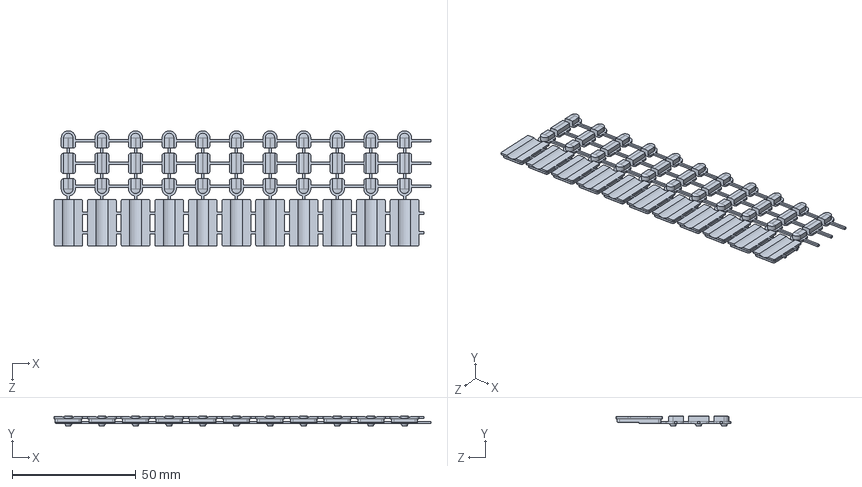
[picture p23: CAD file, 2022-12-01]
Hardware/SW_Project/20210510_SW/UFQFN48-被拼接s.SLDASM
152.5 x 4.15 x 46.7 mm
1223-固定片_UFQFPN48-被拼接 x 11

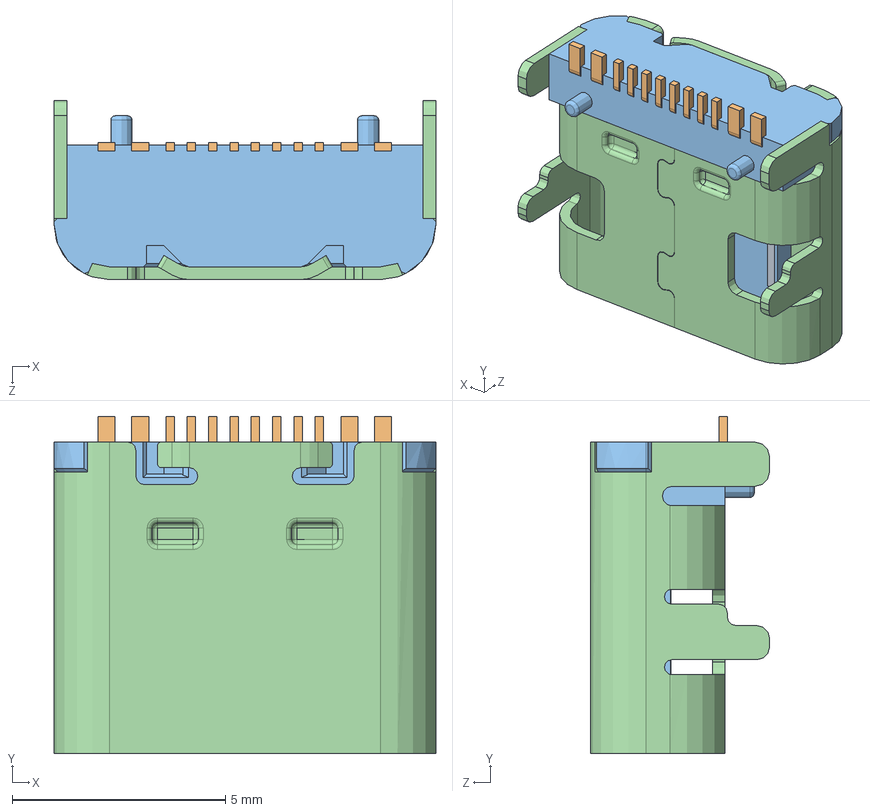
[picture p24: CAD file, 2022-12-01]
Hardware/SW_Project/20210510_SW/HRO_TYPE-C-31-M-12.SLDASM
8.95 x 7.90 x 4.20 mm
ConPins
PcbPins
Mold
Frame

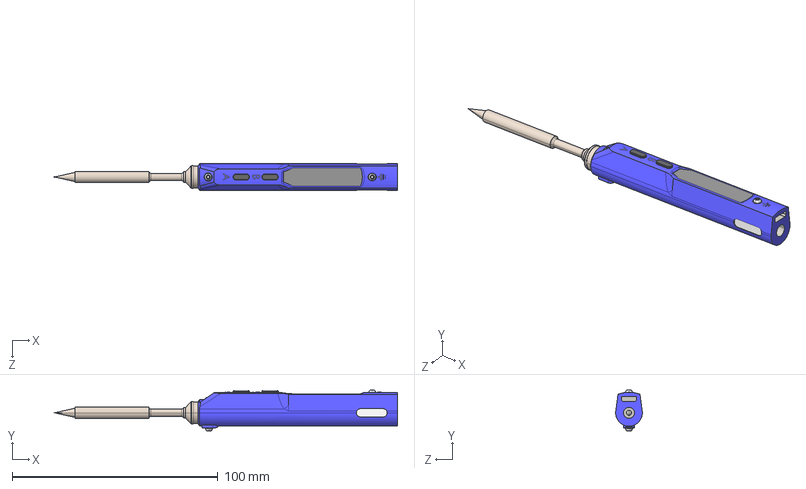
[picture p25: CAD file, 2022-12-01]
Hardware/SW_Project/20210510_SW/TS100 Soldering Iron ASSY.STEP
166.8 x 19.8 x 13.0 mm
TS100 Body
TS100 Tips_TS-B2
18-8 SS BH SH Cap Screw M2x4mm - 92095A451_92095A451 x 3

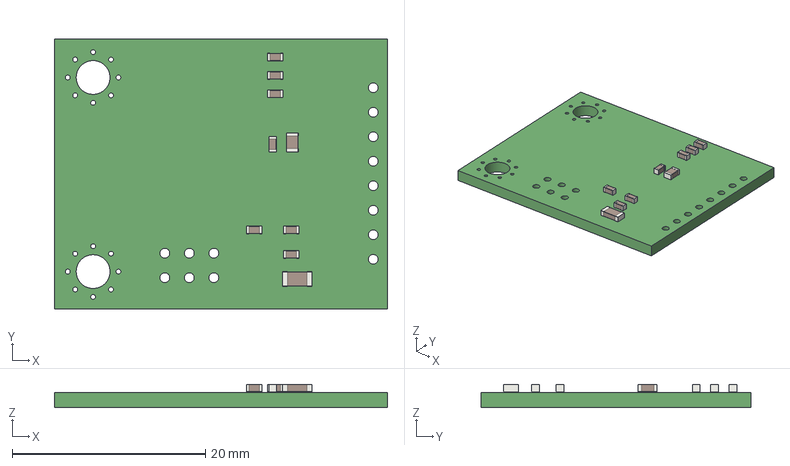
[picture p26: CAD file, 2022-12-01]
Hardware/Datasheets/FUSB302/USB-PD-Breakout/USB-PD-Breakout-master/electrical/USB-PD-Breakout.step
34.5 x 28.0 x 2.43 mm
Socket_Strip_Straight_2x03
Socket_Strip_Straight_1x08_Pitch2.54mm

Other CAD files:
Hardware/PCB_Project/HAKKO_191-212/孔位估算.SLDPRT
Hardware/SW_Project/20210208_SW/保险丝座孔位.SLDPRT
Hardware/SW_Project/20210510_3D打印件/0510-下壳_1446.STL
Hardware/SW_Project/20210510_SW/sot23-package-1.snapshot.6/SOT23-6.stp
Hardware/PCB_Project/HAKKO_191-212/LQFP-48_7x7mm_P0.5mm.SLDPRT
Hardware/PCB_Project/HAKKO_191-212/造型1.SLDPRT
Hardware/SW_Project/20210208_SW/0322-PCB基板.SLDPRT
Hardware/SW_Project/20210208_SW/1223-PCB基板.SLDPRT
Hardware/SW_Project/20210208_SW/1223-上壳-分模+0.6.STL
Hardware/SW_Project/20210208_SW/1223-上壳-分模.STL
Hardware/SW_Project/20210208_SW/1223-下壳-分模+0.3.STL
Hardware/SW_Project/20210208_SW/1223-固定片.STL
Hardware/SW_Project/20210208_SW/DRL.dwg
Hardware/SW_Project/20210208_SW/GBS.dxf
Hardware/SW_Project/20210208_SW/GKO.dxf
Hardware/SW_Project/20210510_3D打印件/0510-上壳_1353.STL
Hardware/SW_Project/20210510_SW/0.86o_led_96x32.SLDPRT
Hardware/SW_Project/20210510_SW/0.87_oled.SLDPRT
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

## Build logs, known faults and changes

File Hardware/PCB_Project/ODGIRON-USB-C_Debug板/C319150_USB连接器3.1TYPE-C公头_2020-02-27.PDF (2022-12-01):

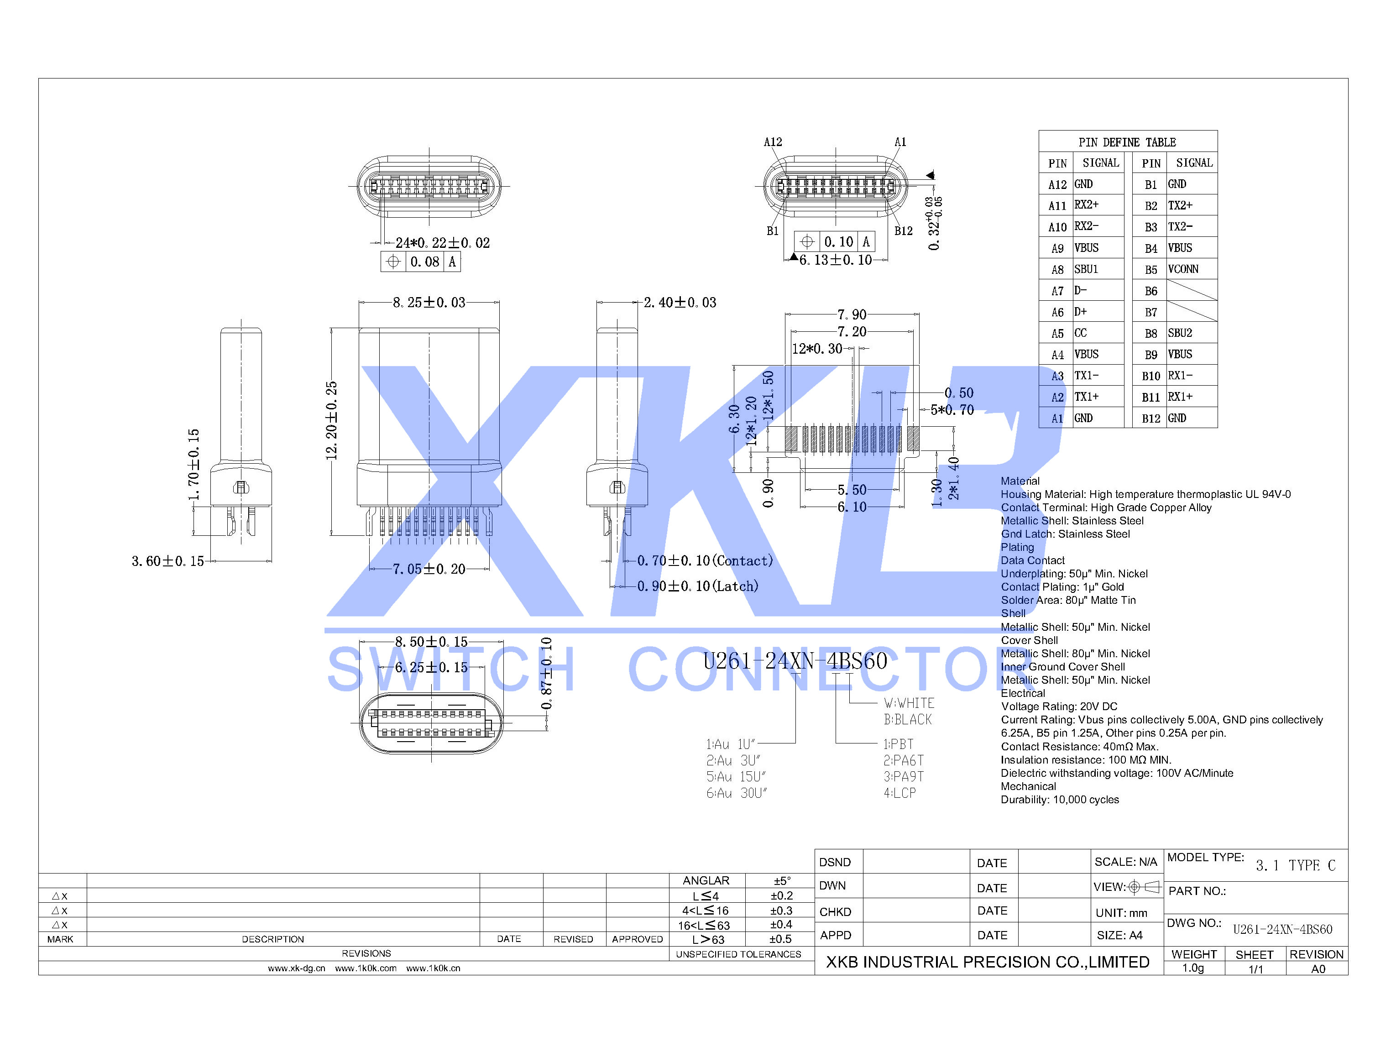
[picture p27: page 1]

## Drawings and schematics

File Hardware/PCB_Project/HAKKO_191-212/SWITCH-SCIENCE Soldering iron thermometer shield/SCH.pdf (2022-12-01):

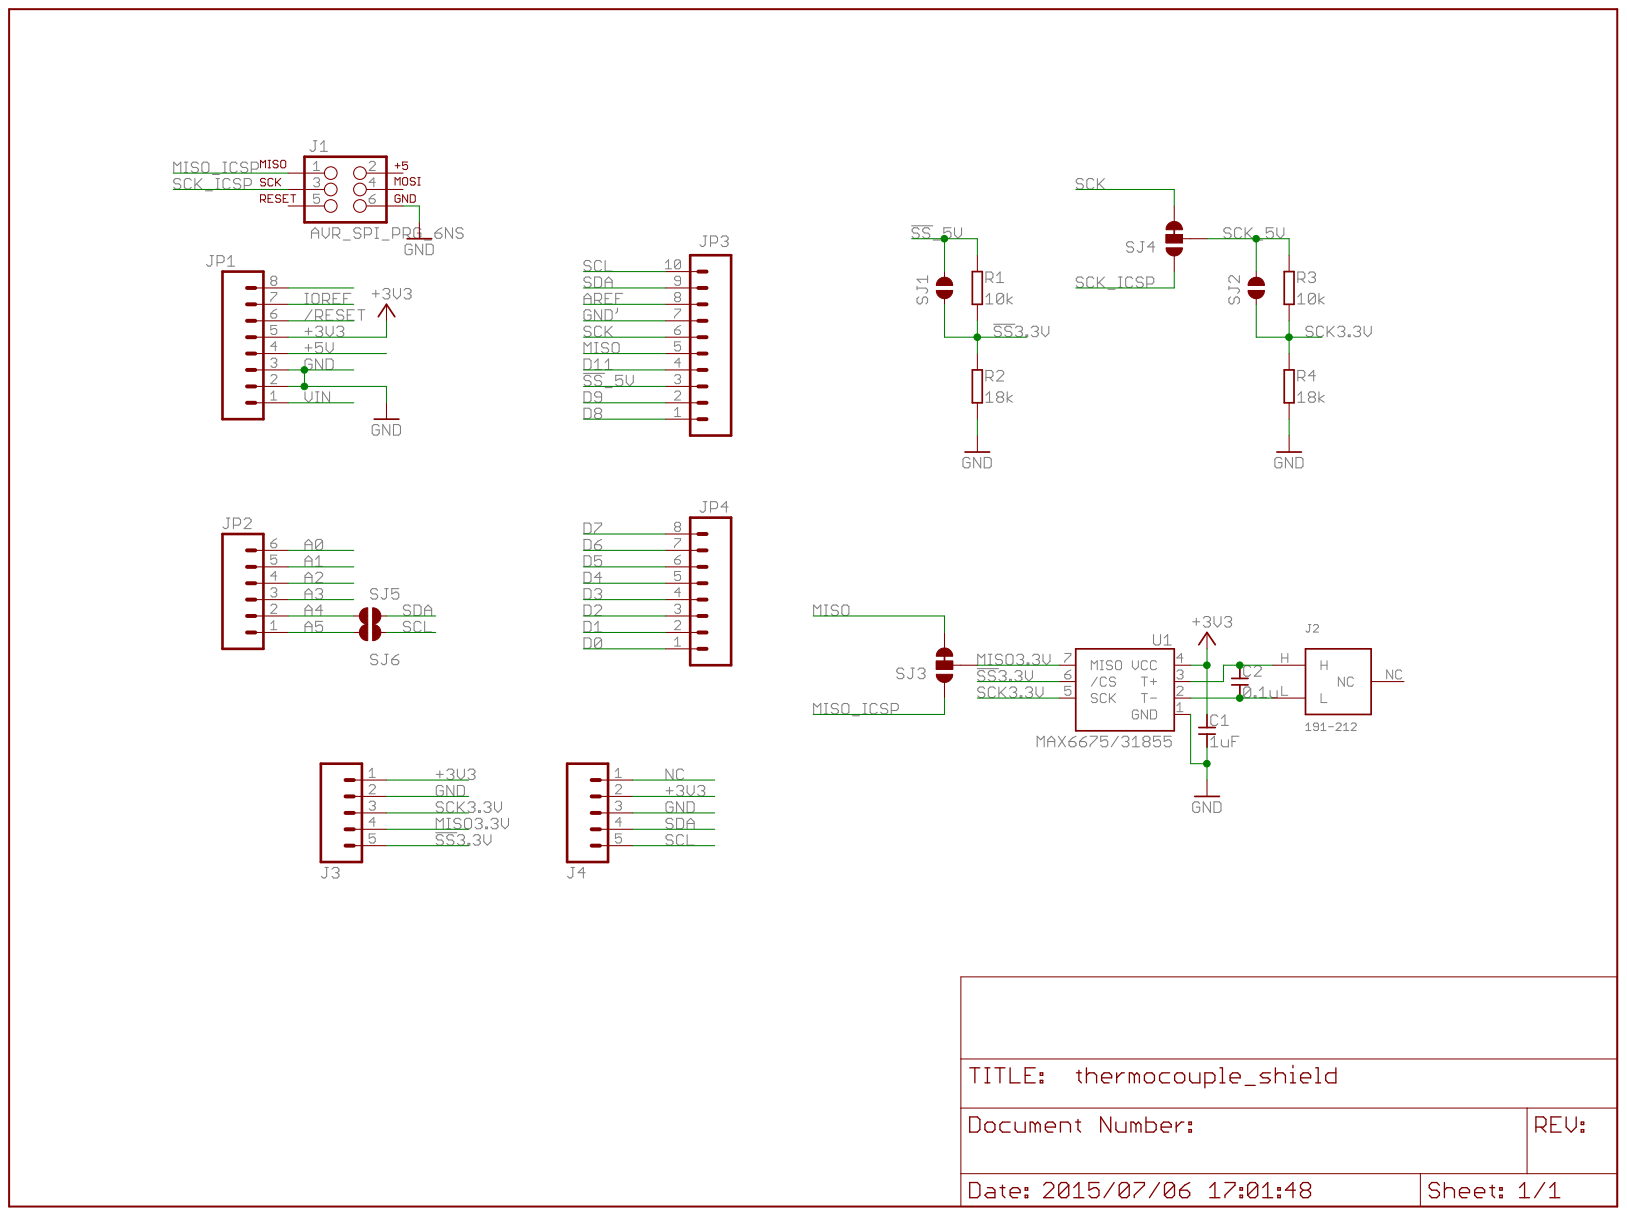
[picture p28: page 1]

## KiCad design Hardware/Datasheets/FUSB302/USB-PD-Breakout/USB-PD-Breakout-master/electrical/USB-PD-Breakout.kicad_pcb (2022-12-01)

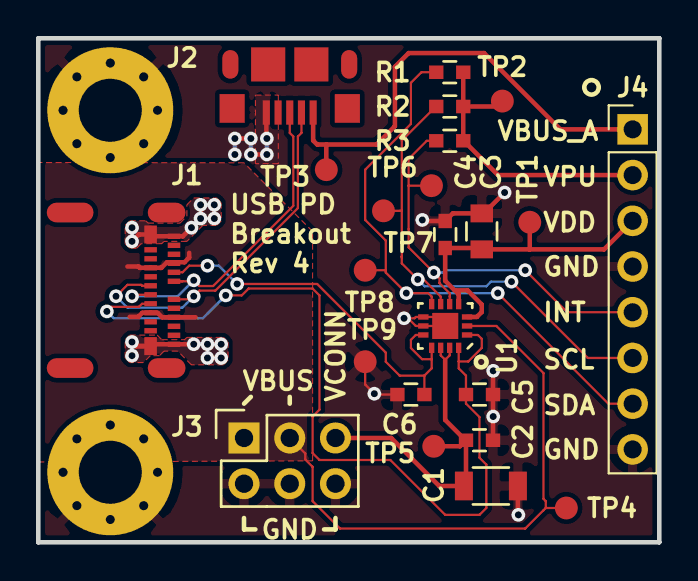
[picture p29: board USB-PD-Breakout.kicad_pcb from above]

Board: 2 copper layers, 34.5 x 28.0 mm, 25 parts (0 on the bottom side), 13 nets.

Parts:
C1: 10uF; C_1206
C2, C4: 0.1uF; C_0603
C3: 1uF; C_0805
C5, C6: 470pF; C_0603
J1: USB-C_Female; USB-C_Female_105450-0101
J2: USB_OTG; USB_Micro-B_10118193
J3: CONN_02X03; Socket_Strip_Straight_2x03
J4: Conn_01x08_Male; Socket_Strip_Straight_1x08_Pitch2.54mm
R1, R2, R3: 4.7k; C_0603
TP1, TP2, TP3, TP4, TP5, TP6, TP7, TP8, TP9: TEST_1P; TP
U1: FUSB302BMPX; MLP_14
X1, X2: MTHOLE; MountingHole_3.5mm_Pad_Via

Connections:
/SCL: J4.6, R2.2, TP7.1, U1.6
/SDA: J4.7, R1.2, TP8.1, U1.7
/USB20_D+: J1.A6, J1.B6, J2.3
/USB20_D-: J1.A7, J1.B7, J2.2
/USBC_CC1: C6.1, J1.A5, U1.10, U1.11
/USBC_CC2: C5.1, J1.B5, U1.1, U1.14
/~INT: J4.5, R3.2, TP6.1, U1.5
GND: C1.2, C2.2, C3.2, C4.2, C5.2, C6.2, J1.A1, J1.A12, J1.B1, J1.B12, J2.5, J3.2, J3.4, J3.6, J4.4, J4.8, TP9.1, U1.8, U1.9, U1.15, X1.1, X2.1
VBUS_A: J2.1, J4.1, TP3.1
VBUS_C: J1.A4, J1.A9, J1.B4, J1.B9, J3.1, J3.3, TP4.1, U1.2
VCONN: C1.1, C2.1, J3.5, TP5.1, U1.12, U1.13
VDD: C3.1, C4.1, J4.3, TP1.1, U1.3, U1.4
V_PULLUP: J4.2, R1.1, R2.1, R3.1, TP2.1

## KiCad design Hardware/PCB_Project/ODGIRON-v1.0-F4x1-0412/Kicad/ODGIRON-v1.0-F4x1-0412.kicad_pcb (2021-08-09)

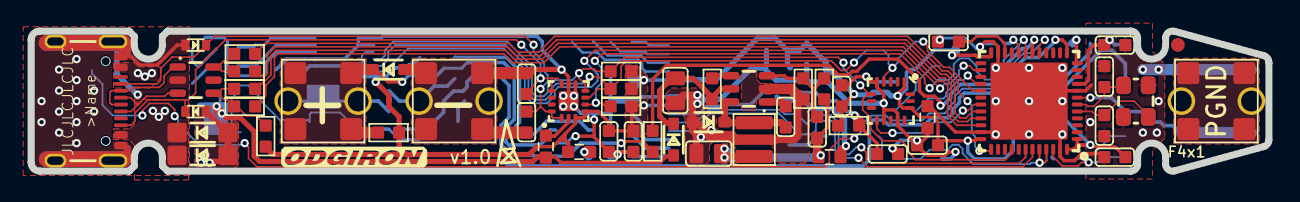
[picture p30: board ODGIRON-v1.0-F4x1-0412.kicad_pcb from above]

Board: 2 copper layers, 89.8 x 10.2 mm, 124 parts (0 on the bottom side), 67 nets.

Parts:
AMP1: SGM8551XN5G/TR; SOT23-5
BUZ1: BUZZER_5020
C1, C2, C3, C4, C5, C6, C10, C11, C12, C13, C14, C16, C29: 0.1uF/50V; C0603
C7, C23: 4.7uF/16V; C0603
C8, C9: 10pF/50V; C0603
C15, C21, C22, C24, C31, C39: 1uF/16V; C0603
C17, C27: 10nF/50V; C0603
C18, C19: 470pF/50V; C0603
C20, C25, C26, C37: 10uF/10V; C0603
C30: 10uF/25V; C0805
C32: 2.2uF/16V; C0603
C33: 4.7uF/50V; C0805
C34, C35: 100pF/50V; C0603
CP1: FUSE_CLIPS_01
D1, D7, D9: B5819WS; SOD-323
D2, D5: SMF24A; SOD-123
D3: MMSZ5242BS-7-F; SOD-323
D6, D8: ESD5B5.0ST1; SOD-523
DA1: INA226; MSOP10
FB1, FB2, FB3, FB4, FB5: 1K; F0603
FID1, FID1#2: FIDUCIAL; FIDUCIAL_1MM
J3: USB-C-16P
JP1: SMT-JUMPER_2_NO_SILK
L1: 33uH CBC3225T330KR; SMD,3.2X2.5X2.5MM
LCD1: 0.87inch SSD1306; 0.87INCH_128X32_OLED_SSD1306
LOGO1: OSHW-LOGONO_SILK; DUMMY
PAD1, PAD2, PAD3, PAD4, PAD5, PAD6, PAD7, PAD8, PAD9, PAD10, PAD11, PAD12: PADTP16SQ; TP16SQ
Q2, Q3: AON7403; DFN8P-0.65-3X3X0.8MM
Q4: S8050; SOT23-3
R1, R13: 32.4K; R0603
R2: 124K; R0603
R3, R10, R16, R18, R19, R22, R25, R35: 4.7K; R0603
R4: 1.5K; R0603
R5, R6, R27, R28: 22R; R0603
R7, R12, R23, R41, R45: 1K; R0603
R8, R20, R42: 100K; R0603
R9, R11, R14, R38: 10K; R0603
R17: 560K; R0603
R24: 10mR ±1% ±50ppm/℃; R1206
R36, R37: 10R; R0603
R43: 2.37K ±0.1% ±25ppm/℃; R0603
R44: 750K ±0.1% ±25ppm/℃; R0603
S1, S2, S3, S5: TACTILE_SWITCH_SMD
T1: HAKKO_T12_K-TYPE_WITH_FUSE_CLIPS_X2
TP1: PGND; TESTPOINT_ROUND_2MM
U1: FUSB302BMPX; QFN14-2.5X2.5MM
U3: STM32F4x1CxU6; QFN48_7X7MM_0.5MM
U4: MP2456GJ; SOT23-6
U5: MCP9700AT-E/TT,or LM50CIM3X; SOT23-3@1
U6: MCP1700T-3302E/TT; SOT23-3
U8: LIS3DH; LGA-16-3X3
U$3: CREATIVE_COMMONS
VD1: USBLC6-2SC6; SOT23-6
ZO1: 8MHz; 3.2X2.5_KX-7

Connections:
3.9V: C30.1, C35.1, FB1.1, L1.2, R2.1
+3V3: C2.1, C4.1, C5.1, C12.2, C13.2, C14.2, C15.1, C20.2, C23.2, C24.2, C37.2, C39.2, DA1.6, FB2.2, FB3.2, LCD1.5, LCD1.8, R3.1, R4.2, R13.2, R16.1, R18.2, R19.2, R22.2, R23.2, R25.1, R38.1, S3.3, S3.4, U1.3, U1.4, U3.1, U3.24, U3.36, U3.48, U5.1, U6.2, U8.1, U8.14
AMP+: AMP1.3, R42.1
AMP-: AMP1.4, C34.2, R43.1, R44.2
BS: C29.1, U4.1
CC1: C18.1, D8.K, J3.A5, U1.1, U1.14
CC2: C19.1, D6.K, J3.B5, U1.10, U1.11
D+: J3.A6, J3.B6, VD1.3
D-: J3.A7, J3.B7, VD1.1
DCDC_IN: C33.1, D1.C, R20.2, U4.5
EN: R20.1, U4.4
GND: AMP1.2, BUZ1.-, C2.2, C3.2, C4.2, C5.2, C6.2, C7.2, C8.1, C9.1, C10.2, C11.1, C12.1, C13.1, C14.1, C15.2, C16.1, C18.2, C19.2, C20.1, C23.1, C24.1, C25.2, C26.2, C27.2, C30.2, C31.1, C32.2, C33.2, C37.1, C39.1, D2.A, D5.A, D6.A, D7.A, D8.A, D9.A, DA1.1, DA1.2, DA1.7, FB4.1, FB4.2, J3.GND, J3.GND2, J3.SHLD1, J3.SHLD2, J3.SHLD5, J3.SHLD8, JP1.1, LCD1.7, PAD5.TP, PAD6.TP, PAD7.TP, PAD8.TP, Q4.2, R1.1, R8.2, R12.1, R17.1, R43.2, S1.1, S1.2, S2.1, S2.2, S5.1, S5.2, T1.1A1, T1.1B1, U1.8, U1.9, U1.THERMAL, U3.8, U3.23, U3.35, U3.47, U3.P$1, U4.2, U5.3, U6.1, U8.5, U8.10, U8.12, VD1.2, ZO1.2, ZO1.4
LDO_IN: C31.2, FB1.2, U6.3
unnamed: R4.1, R5.1, R27.1, VD1.4
unnamed: R7.2, S3.1, S3.2
unnamed: D3.C, Q2.1, Q2.2, Q2.3, Q3.1, Q3.2, Q3.3
unnamed: C21.1, LCD1.1
unnamed: D3.A, Q2.4, Q3.4, R10.2, R35.1
unnamed: C22.1, LCD1.3
unnamed: C11.2, FB2.1, U3.9
unnamed: C3.1, R9.2, S1.3, S1.4
unnamed: C21.2, LCD1.2
unnamed: C6.1, R14.2, S2.3, S2.4
unnamed: C22.2, LCD1.4
unnamed: C25.1, LCD1.13
unnamed: LCD1.12, R17.2
unnamed: C26.1, LCD1.14
unnamed: Q4.1, R11.1
unnamed: C35.2, R1.2, R2.2, U4.3
unnamed: C16.2, Q4.3, R35.2
unnamed: C17.1, R11.2, R12.2
unnamed: AMP1.5, FB3.1
unnamed: R6.1, R28.1, VD1.6
unnamed: FB5.1, U1.2
unnamed: JP1.2, U3.20
unnamed: C1.1, DA1.10, R36.1
unnamed: C1.2, DA1.9, R37.1
unnamed: R41.2, U5.2
NRST: C10.1, R23.1, S5.3, S5.4, U3.7
OSC_IN: C8.2, U3.5, ZO1.3
OSC_OUT: C9.2, U3.6, ZO1.1
OUT: AMP1.1, C34.1, R44.1, R45.2
PA2/ADC2: R41.1, U3.12
PA3/T2C4: C17.2, U3.13
PA7/T1CH1N/T3C2: BUZ1.+, U3.17
PA8/SCL3: DA1.5, R3.2, U1.6, U3.29, U8.4
PA10/IT_ACCEL_2: U3.31, U8.9
PA11/USB_DM: R6.2, U3.32
PA12/USB_DP: R5.2, U3.33
PA13/SWDIO: R27.2, U3.34
PA14/SWCLK: R28.2, U3.37
PB0/ADC8: R45.1, U3.18
PB1/IT_FUSB302: R16.2, U1.5, U3.19
PB4/SDA3: DA1.4, R25.2, U1.7, U3.40, U8.6
PB6/SCL1: LCD1.10, R19.1, U3.42
PB7/SDA1: LCD1.11, R18.1, U3.43
PB8&BOOT0_S3: R7.1, R8.1, U3.44, U3.45
PB9/S1: R9.1, U3.46
PB13/IT_INA226: DA1.3, R38.2, U3.26
PB15/S2: R14.1, U3.28
PGND: CP1.1A, CP1.1B, PAD9.TP, PAD10.TP, PAD11.TP, PAD12.TP, TP1.P$1
RES_3.3V: C7.1, LCD1.9, R22.1
SW: C29.2, D7.C, L1.1, U4.6
T12+: C27.1, D9.C, PAD1.TP, PAD2.TP, PAD3.TP, PAD4.TP, Q3.5, Q3.6, Q3.7, Q3.8, Q3.9, R13.1, R42.2, T1.1A, T1.1B
VBUS-C: D1.A, FB5.2, Q2.5, Q2.6, Q2.7, Q2.8, Q2.9, R10.1, R24.1, R37.2
VCAP1: C32.1, U3.22
VUSB_IN: D2.C, D5.C, DA1.8, J3.VBUS1, J3.VBUS2, R24.2, R36.2

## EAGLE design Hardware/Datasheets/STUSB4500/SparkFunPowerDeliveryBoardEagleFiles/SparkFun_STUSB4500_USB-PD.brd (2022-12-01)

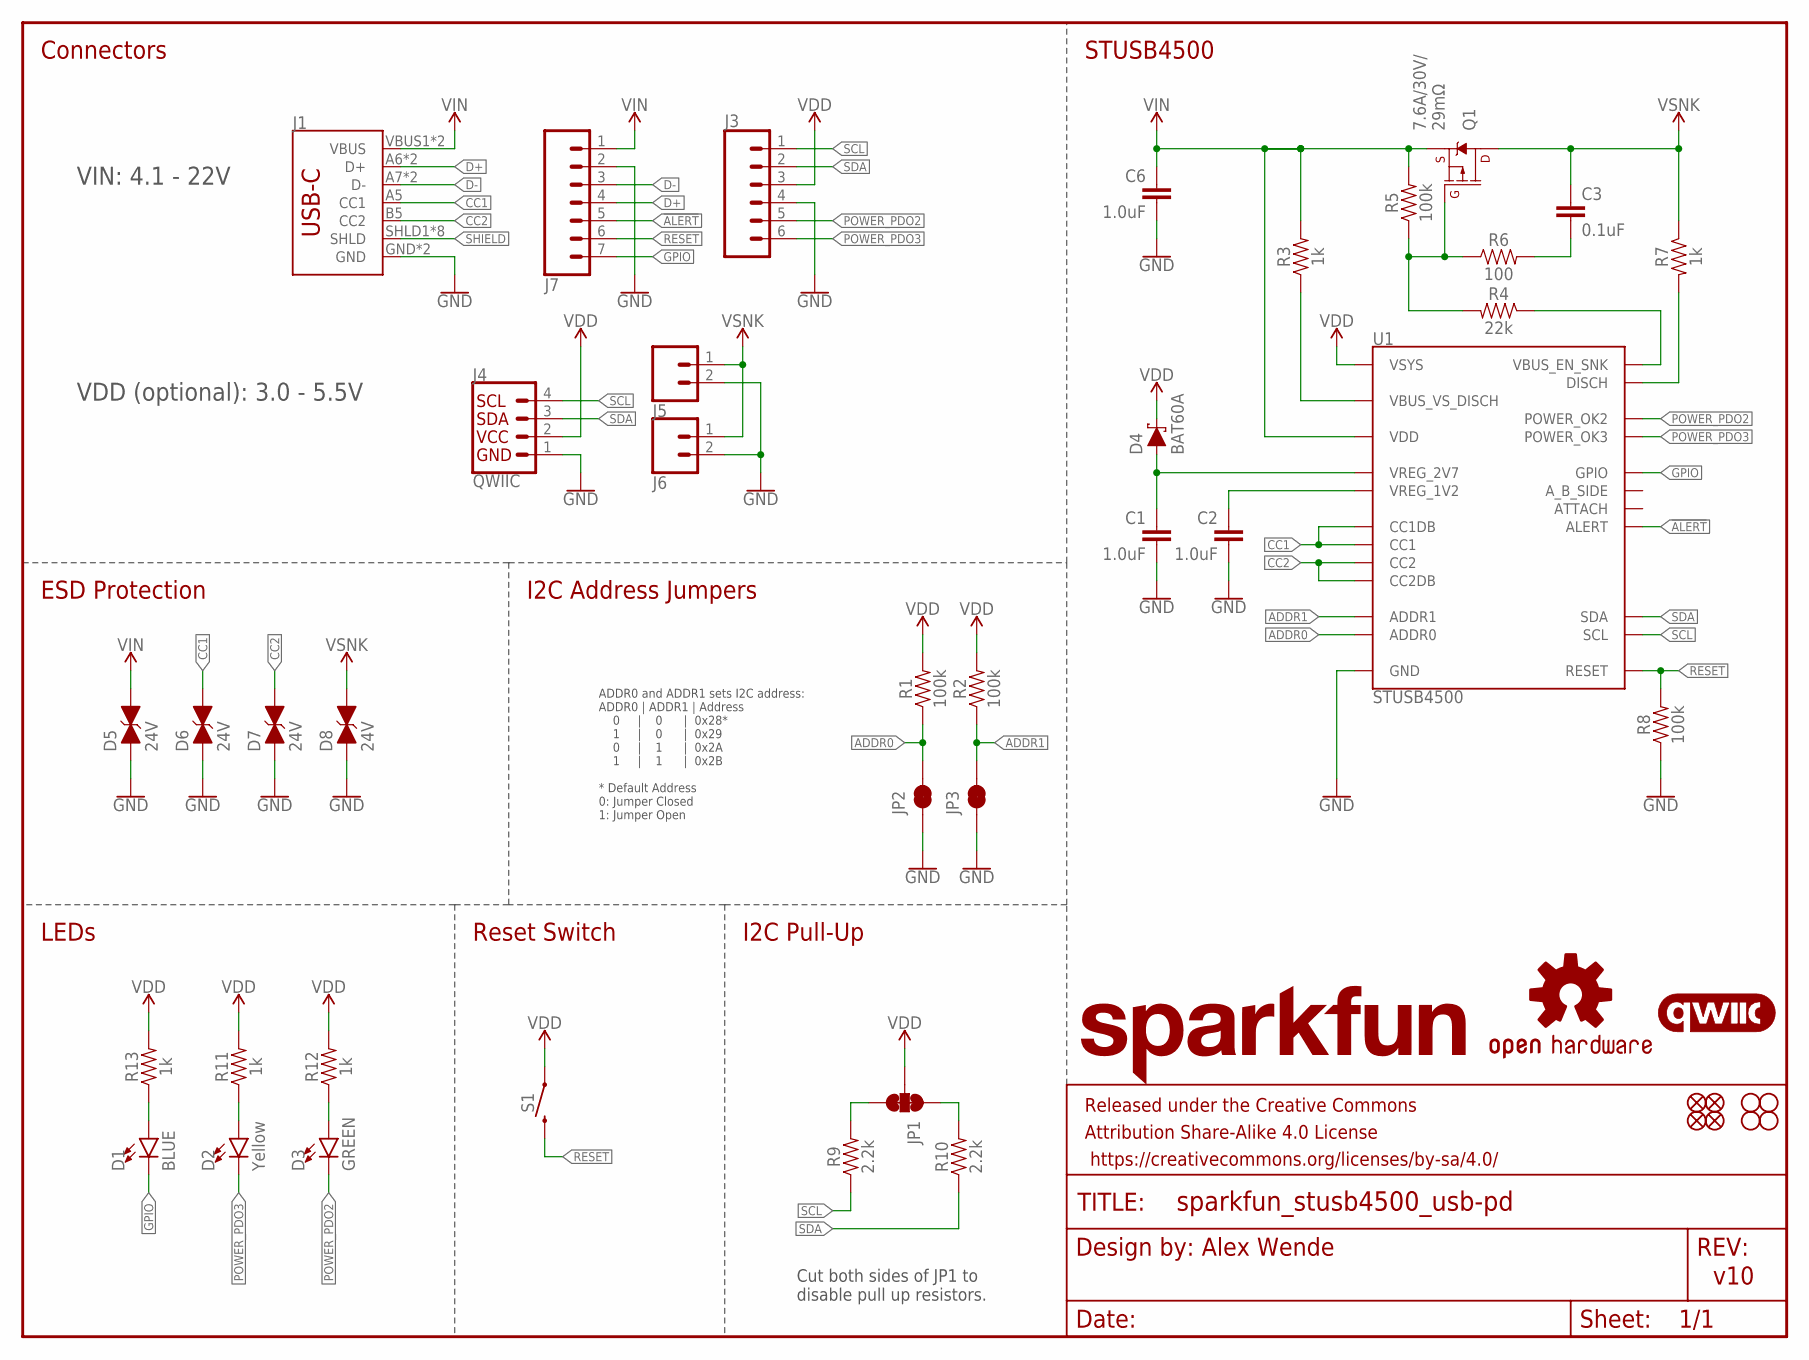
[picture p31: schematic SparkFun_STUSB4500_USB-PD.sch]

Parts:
C1, C2, C6: 1.0uF; 0603
C3: 0.1uF; 0603
D1: BLUE; LED-0603
D2: Yellow; LED-0603
D3: GREEN; LED-0603
D4: BAT60A; SOD-323
D5, D6, D7, D8: 24V; 0603
FD1, FD2, FD3, FD4: FIDUCIALUFIDUCIAL; FIDUCIAL-MICRO
FRAME1: FRAME-LETTER; CREATIVE_COMMONS
H1, H2, H3, H4: STAND-OFF
J1: USB_C2-LAYER; USB-C-16P
J3: CONN_06NO_SILK_NO_POP; 1X06_NO_SILK
J4: QWIIC; JST04_1MM_RA
J5: CONN_023.5MM; SCREWTERMINAL-3.5MM-2
J6: CONN_021X02_NO_SILK; 1X02_NO_SILK
J7: CONN_07NO_SILK; 1X07_NO_SILK
JP1: JUMPER-SMT_3_2-NC_TRACE_NO-SILK; SMT-JUMPER_3_2-NC_TRACE_NO-SILK
JP2, JP3: JUMPER-SMT_2_NC_TRACE_NO-SILK; SMT-JUMPER_2_NC_TRACE_NO-SILK
LOGO1: OSHW-LOGOS; OSHW-LOGO-S
LOGO2: SFE_LOGO_NAME.1_INCH; SFE_LOGO_NAME_.1
LOGO3: QWIIC_LOGO_5MM; QWIIC_5MM
Q1: 9A/30V/15mΩ; 8-POWERVDFN-3X3
R1, R2, R5, R8: 100k; 0603
R3, R7, R11, R12, R13: 1k; 0603
R4: 22k; 0603
R6: 100; 0603
R9, R10: 2.2k; 0603
S1: MOMENTARY-SWITCH-SPST-SMD-4.6X2.8MM; TACTILE_SWITCH_SMD_4.6X2.8MM
U1: STUSB4500; QFN-24

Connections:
1.2V: C2.1, U1.P$21 (VREG_1V2)
2.7V: C1.1, D4.A, U1.P$23 (VREG_2V7)
!ALERT: J7.5, U1.P$19 (ALERT)
ADDR0: JP2.2, R1.1, U1.P$12 (ADDR0)
ADDR1: JP3.2, R2.1, U1.P$13 (ADDR1)
CC1: D6.2 (C), J1.A5 (CC1), U1.P$1 (CC1DB), U1.P$2 (CC1)
CC2: D7.2 (C), J1.B5 (CC2), U1.P$4 (CC2), U1.P$5 (CC2DB)
D+: J1.A6 (D+), J1.B6 (D+), J7.4
D-: J1.A7 (D-), J1.B7 (D-), J7.3
DISCH: R7.2, U1.P$9 (DISCH)
EN_SNK: R4.1, U1.P$16 (VBUS_EN_SNK)
GND: C1.2, C2.2, C6.2, D5.1 (A), D6.1 (A), D7.1 (A), D8.1 (A), J1.GND, J1.GND2 (GND), J3.4, J4.1, J5.2, J6.2, J7.2, JP2.1, JP3.1, R8.1, U1.P$10 (GND), U1.P$25 (GND)
GPIO: D1.C, J7.7, U1.P$15 (GPIO)
unnamed: D2.A, R11.1
unnamed: D3.A, R12.1
unnamed: JP1.3, R9.2
unnamed: JP1.1, R10.2
unnamed: Q1.4 (G), R4.2, R5.1, R6.1
unnamed: C3.2, R6.2
unnamed: D1.A, R13.1
POWER_PDO2: D3.C, J3.5, U1.P$20 (POWER_OK2)
POWER_PDO3: D2.C, J3.6, U1.P$14 (POWER_OK3)
RESET: J7.6, R8.2, S1.3 (2), S1.4 (2), U1.P$6 (RESET)
SCL: J3.1, J4.4, R9.1, U1.P$7 (SCL)
SDA: J3.2, J4.3, R10.1, U1.P$8 (SDA)
SHIELD: J1.SHLD1 (SHLD), J1.SHLD2 (SHLD), J1.SHLD3 (SHLD), J1.SHLD4 (SHLD), J1.SHLD5 (SHLD), J1.SHLD6 (SHLD), J1.SHLD7 (SHLD), J1.SHLD8 (SHLD)
VBUS_VS_DISCH: R3.1, U1.P$18 (VBUS_VS_DISCH)
VDD: D4.C, J3.3, J4.2, JP1.2, R1.2, R2.2, R11.2, R12.2, R13.2, S1.1, S1.2 (1), U1.P$22 (VSYS)
VIN: C6.1, D5.2 (C), J1.VBUS1 (VBUS), J1.VBUS2 (VBUS), J7.1, Q1.1 (S), Q1.2 (S), Q1.3 (S), R3.2, R5.2, U1.P$24 (VDD)
VSNK: C3.1, D8.2 (C), J5.1, J6.1, Q1.5@1 (D), Q1.5@2 (D), Q1.5@3 (D), R7.1

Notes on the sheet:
ADDR0 and ADDR1 sets I2C address: ADDR0 | ADDR1 | Address 0 | 0 | 0x28* 1 | 0 | 0x29 0 | 1 | 0x2A 1 | 1 | 0x2B * Default Address 0: Jumper Closed 1: Jumper Open
Alex Wende
v10
STUSB4500
Connectors
I2C Pull-Up
LEDs
Reset Switch
I2C Address Jumpers
VIN: 4.1 - 22V
7.6A/30V/ 29mΩ
ESD Protection
VDD (optional): 3.0 - 5.5V
Cut both sides of JP1 to disable pull up resistors.

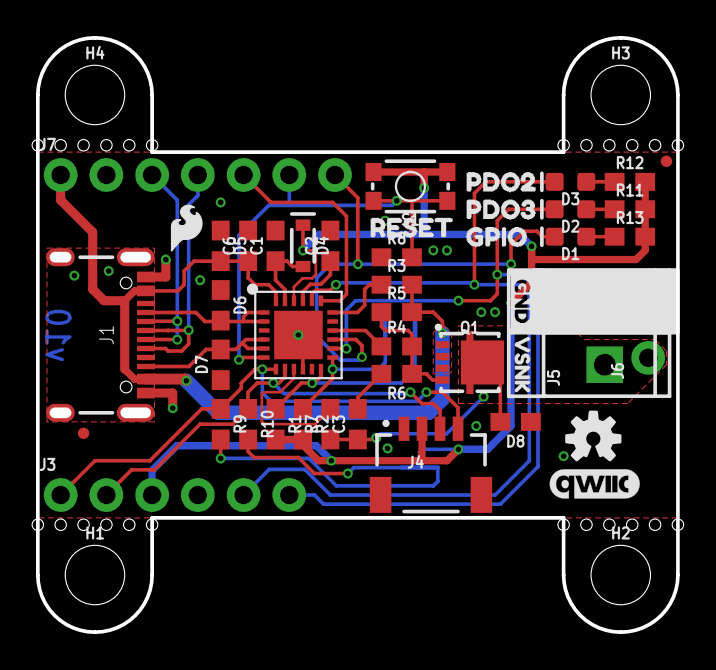
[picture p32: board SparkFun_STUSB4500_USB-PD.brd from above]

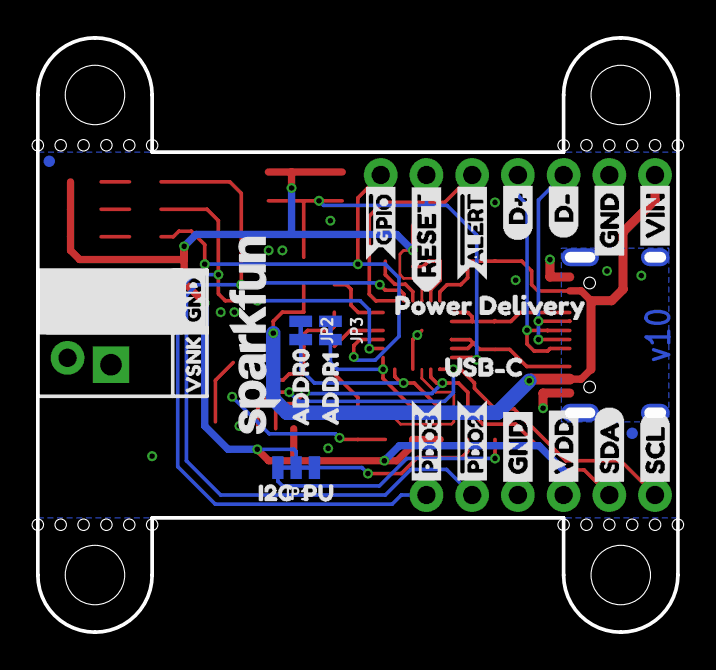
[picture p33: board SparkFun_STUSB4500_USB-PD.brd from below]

Board: 2 copper layers, 35.6 x 33.0 mm, 77 parts (27 on the bottom side), 30 nets.

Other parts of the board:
U$1: VDD2
U$2, U$11: GND6
U$3: SDA11
U$4: SCL12
U$5: #GPIO0
U$7: D#8
U$8: D#7
U$9: USB#C1
U$10: RESET10
U$12: VIN6
U$13: I2C2
U$14: PU3
U$15: ADDR00
U$16: ADDR11
U$17: RESET7
U$18: GPIO1
U$19: PDO24
U$20: PDO35
U$21, U$24: VSNK1
U$22, U$23: GND0
U$25: SFE_LOGO_FLAME_.1
U$26: #ALERT0
U$27: _POWER_DELIVERY2
U$29: #PDO20
U$30: #PDO31

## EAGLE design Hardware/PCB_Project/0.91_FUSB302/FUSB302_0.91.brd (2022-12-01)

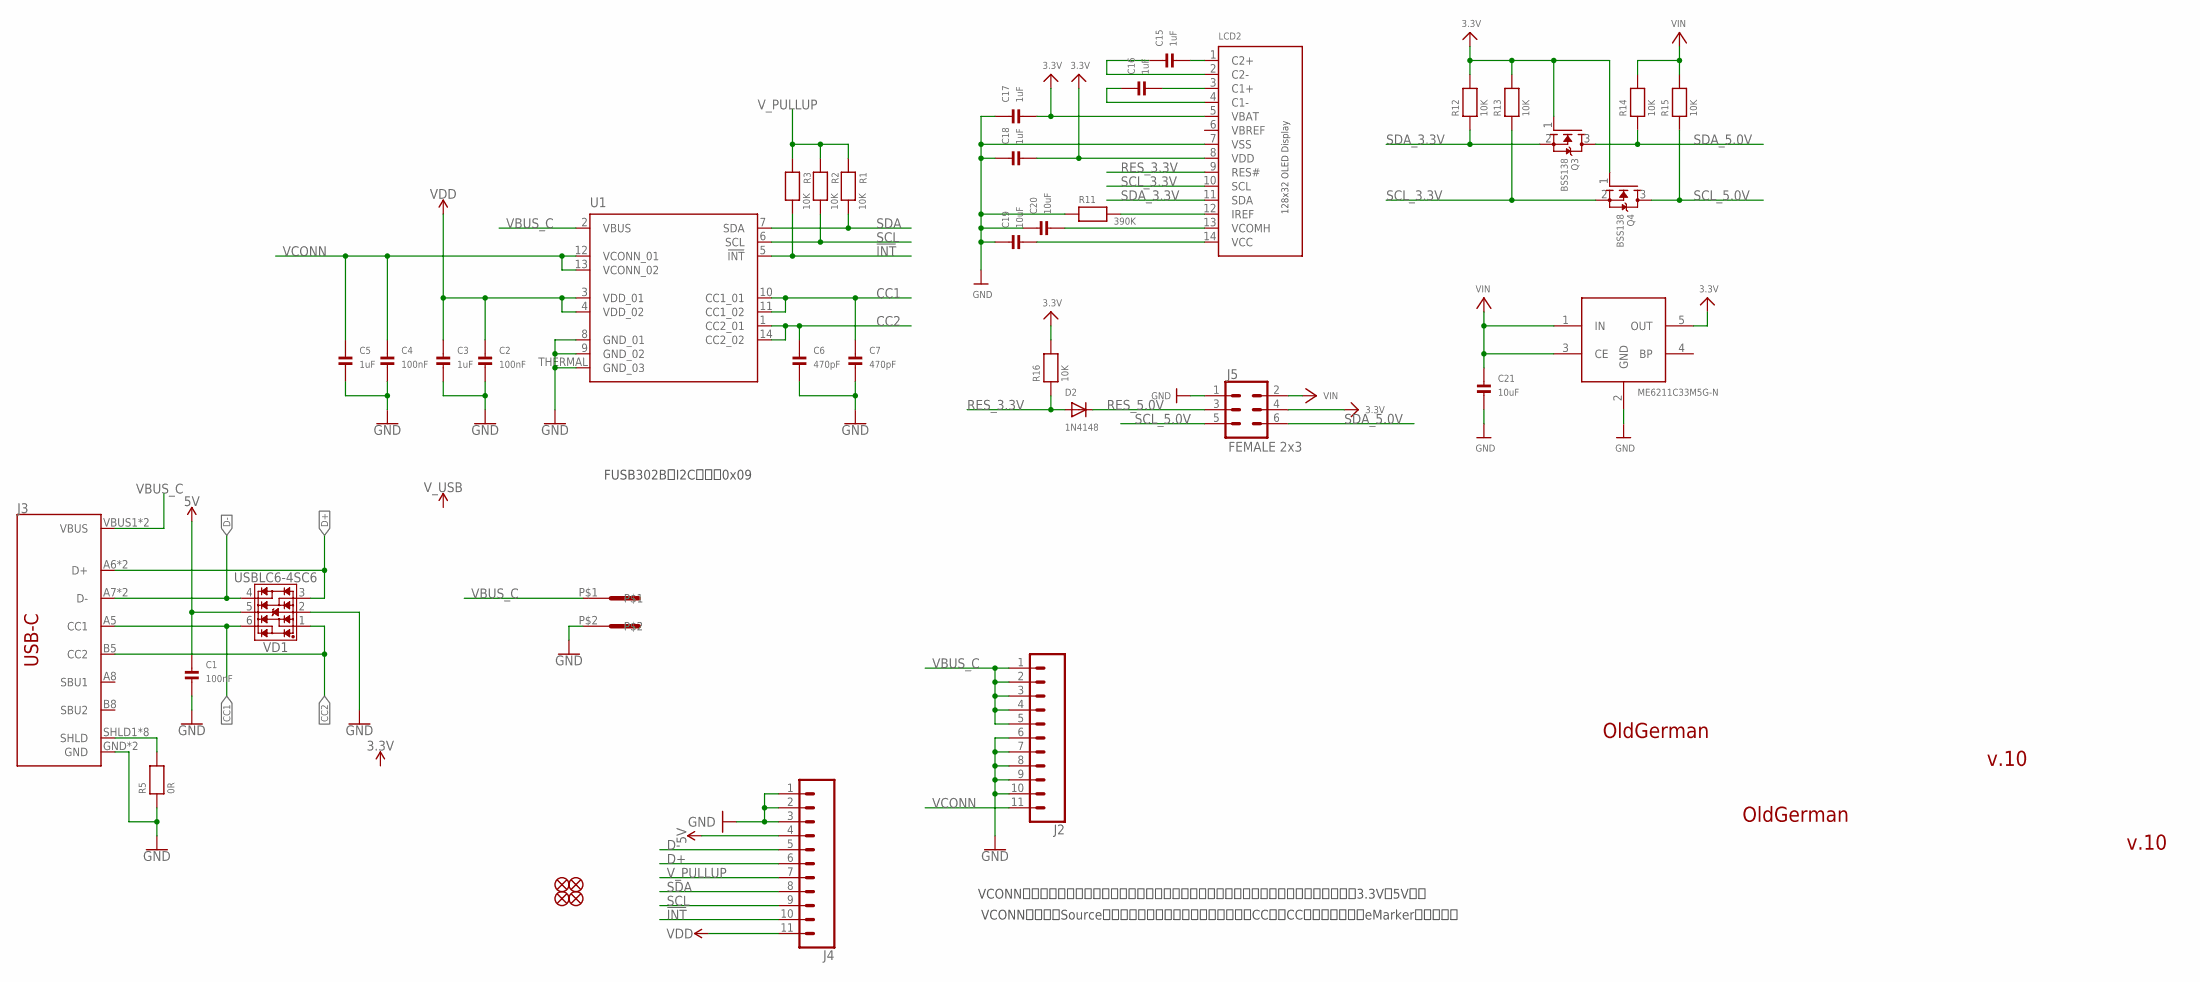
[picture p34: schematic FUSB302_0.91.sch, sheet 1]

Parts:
C1, C2, C4: 100nF; 0603
C3, C5, C15, C16, C17, C18: 1uF; 0603
C6, C7: 470pF; 0603
C19, C20, C21: 10uF; 0603
D2: 1N4148; SOD-323F
FD5, FD6, FD7, FD8: FIDUCIAL_MINI1X2; FIDUCIAL-1X2
J2, J4: CONN_11; 1X11
J3: USB_C_LONG-SYMBOL2-LAYER; USB-C-16P
J5: FEMALE 2x3; 2X3
LCD2: 0.91INCH_OLED_128X32_CH1115; 0.91INCH_128X32_OLED_CH1115
Q3, Q4: BSS138; SOT23-WIDE
R1, R2, R3, R12, R13, R14, R15, R16: 10K; 0603
R5: 0R; 0603
R11: 390K; 0603
U1: FUSB302; QFN14-2.5X2.5MM
U$5: 5.08MM_CONN; 1715250000
U$24: ME6211C33M5G-N; SOT23-5
VD1: USBLC6-4SC6; SOT23-6

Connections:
3.3V: C17.2, J5.4, LCD2.5 (VBAT), Q3.1 (G), Q4.1 (G), R12.2, R13.2, R16.2, U$24.5 (OUT)
5V: C1.1, J4.4, VD1.5
!INT: J4.10, R3.2, U1.5 (!INT)
CC1: C7.1, J3.A5 (CC1), U1.10 (CC1_01), U1.11 (CC1_02), VD1.6
CC2: C6.1, J3.B5 (CC2), U1.1 (CC2_01), U1.14 (CC2_02), VD1.1
D+: J3.A6 (D+), J3.B6 (D+), J4.6, VD1.3
D-: J3.A7 (D-), J3.B7 (D-), J4.5, VD1.4
GND: C1.2, C2.2, C3.2, C4.2, C5.2, C6.2, C7.2, C17.1, C18.1, C19.1, C20.1, C21.2, J2.6, J2.7, J2.8, J2.9, J2.10, J3.GND, J3.GND2 (GND), J4.1, J4.2, J4.3, J5.1, LCD2.7 (VSS), R5.1, R11.1, U1.8 (GND_01), U1.9 (GND_02), U1.THERMAL (GND_03), U$5.P$2, U$24.2 (GND), VD1.2
unnamed: J3.SHLD1 (SHLD), J3.SHLD2 (SHLD), J3.SHLD3 (SHLD), J3.SHLD4 (SHLD), J3.SHLD5 (SHLD), J3.SHLD6 (SHLD), J3.SHLD7 (SHLD), J3.SHLD8 (SHLD), R5.2
unnamed: C18.2, LCD2.8 (VDD)
unnamed: C15.2, LCD2.1 (C2+)
unnamed: C15.1, LCD2.2 (C2-)
unnamed: C16.2, LCD2.3 (C1+)
unnamed: C16.1, LCD2.4 (C1-)
unnamed: C20.2, LCD2.13 (VCOMH)
unnamed: LCD2.12 (IREF), R11.2
unnamed: C19.2, LCD2.14 (VCC)
RES_3.3V: D2.A, LCD2.9 (RES#), R16.1
RES_5.0V: D2.C, J5.3
SCL: J4.9, R2.2, U1.6 (SCL)
SCL_3.3V: LCD2.10 (SCL), Q4.2 (S), R13.1
SCL_5.0V: J5.5, Q4.3 (D), R15.1
SDA: J4.8, R1.2, U1.7 (SDA)
SDA_3.3V: LCD2.11 (SDA), Q3.2 (S), R12.1
SDA_5.0V: J5.6, Q3.3 (D), R14.1
VBREF: LCD2.6 (VBREF)
VBUS_C: J2.1, J2.2, J2.3, J2.4, J2.5, J3.VBUS1 (VBUS), J3.VBUS2 (VBUS), U1.2 (VBUS), U$5.P$1
VCONN: C4.1, C5.1, J2.11, U1.12 (VCONN_01), U1.13 (VCONN_02)
VDD: C2.1, C3.1, J4.11, U1.3 (VDD_01), U1.4 (VDD_02)
VIN: C21.1, J5.2, R14.2, R15.2, U$24.1 (IN), U$24.3 (CE)
V_PULLUP: J4.7, R1.1, R2.1, R3.1

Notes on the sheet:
FUSB302B的I2C地址：0x09
VCONN（只有在插头上才会有该信号），当线缆里有芯片的时候，用来给线缆里的芯片供电（3.3V或5V）。
VCONN是插头里Source到电源线的电子提供，并经过不连接到CC线的CC引脚，初衷是给eMarker芯片供电。
OldGerman
v.10

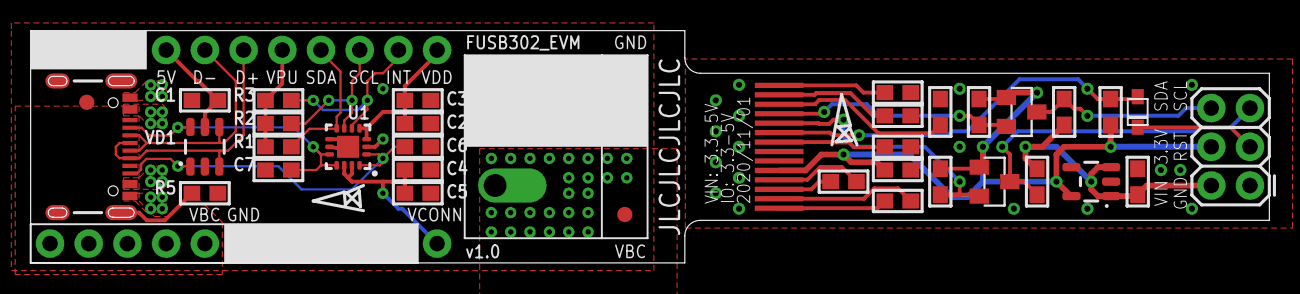
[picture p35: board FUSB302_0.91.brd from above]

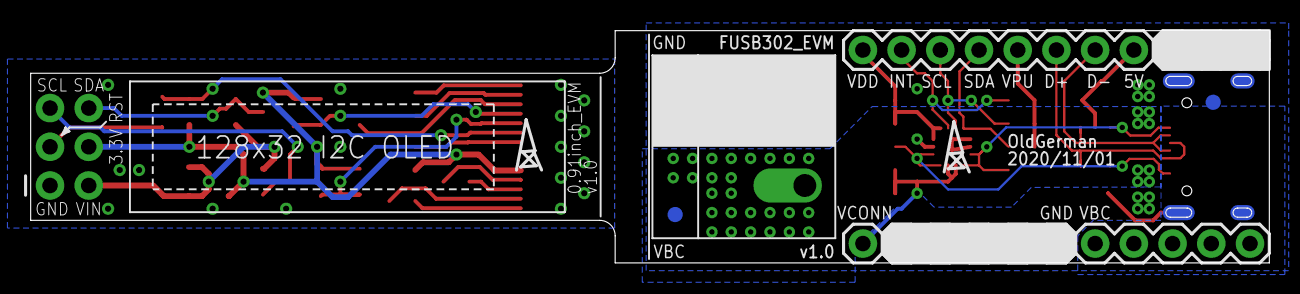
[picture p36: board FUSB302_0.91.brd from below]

Board: 2 copper layers, 81.3 x 15.2 mm, 40 parts (5 on the bottom side), 30 nets.

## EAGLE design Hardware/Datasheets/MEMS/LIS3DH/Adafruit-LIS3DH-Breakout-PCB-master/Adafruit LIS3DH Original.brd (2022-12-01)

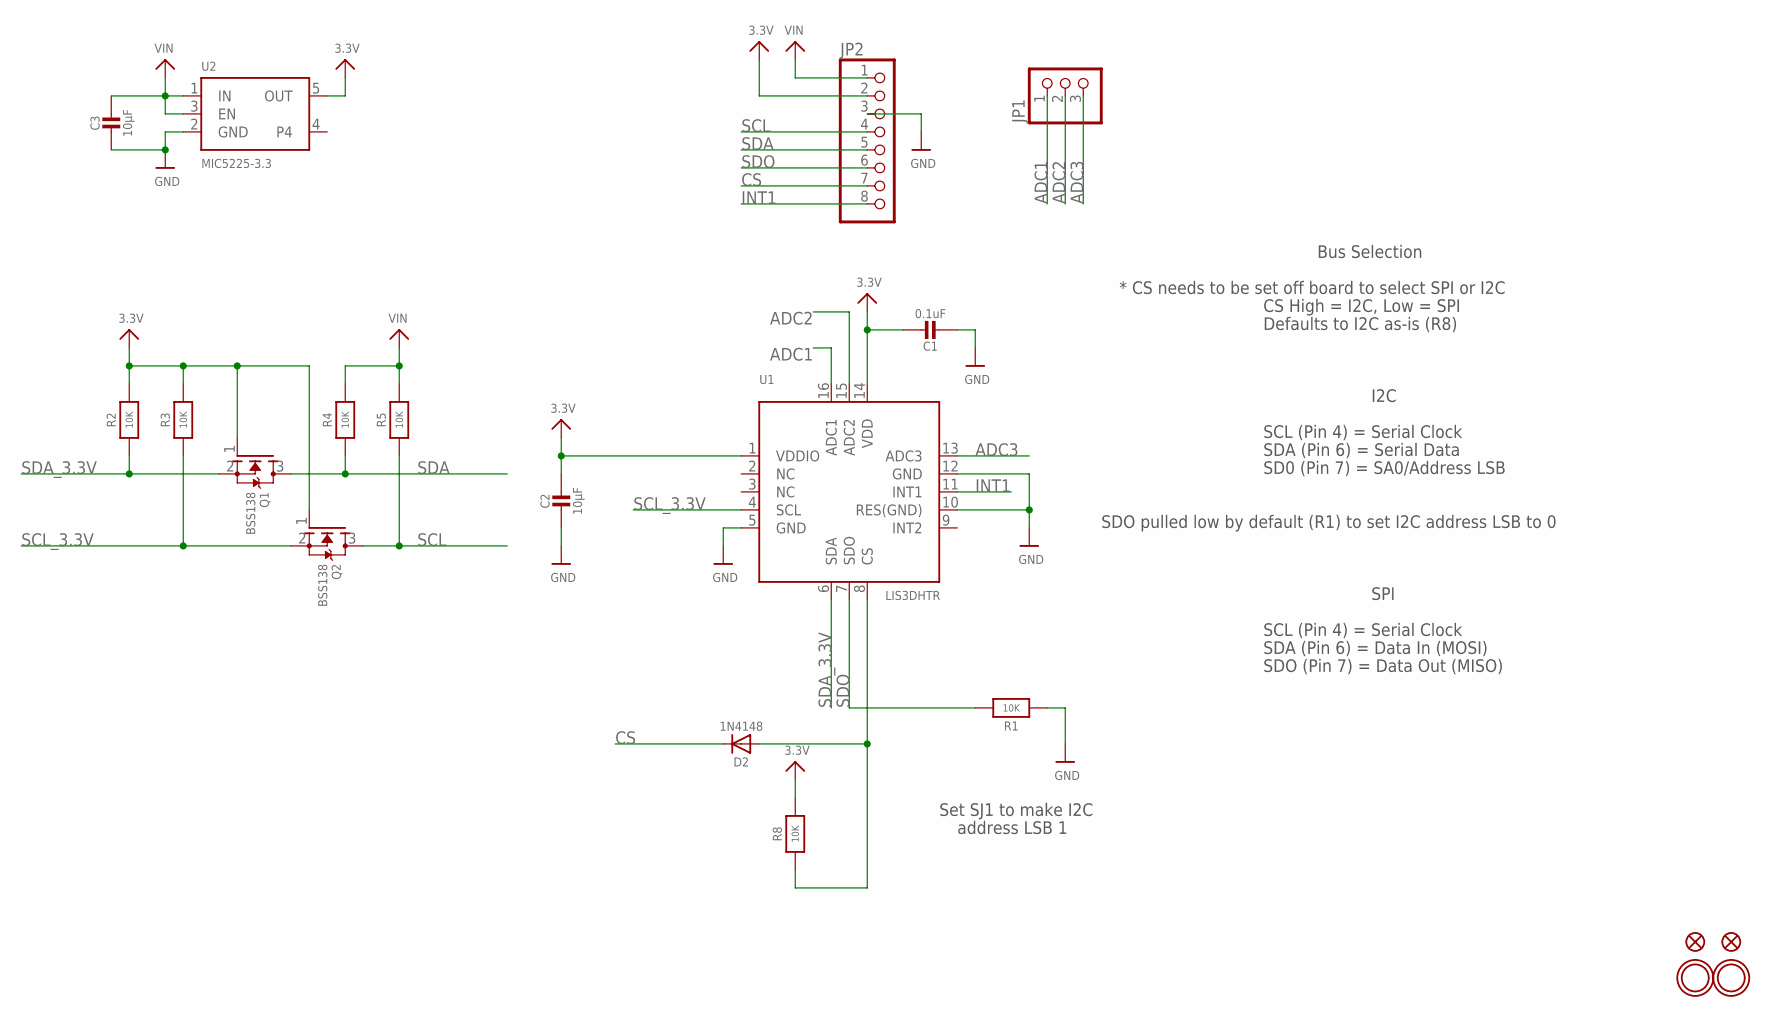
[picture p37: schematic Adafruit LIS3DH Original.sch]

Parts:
C1: 0.1uF; 0805_10MGAP
C2, C3: 10µF; 0805-NO
D2: 1N4148; SOD-323
FID1, FID2: FIDUCIAL""; FIDUCIAL_1MM
JP1: HEADER-1X3ROUND; 1X03_ROUND
JP2: HEADER-1X870MIL; 1X08_ROUND_70
Q1, Q2: BSS138; SOT23-WIDE
R1, R2, R3, R4, R5, R8: 10K; 0805-NO
U1: LIS3DHTR; LGA16_3X3MM
U2: MIC5225-3.3; SOT23-5
U$10, U$13: MOUNTINGHOLE2.5; MOUNTINGHOLE_2.5_PLATED

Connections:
3.3V: C1.1, C2.1, JP2.2, Q1.1 (G), Q2.1 (G), R2.2, R3.2, R8.2, U1.1 (VDDIO), U1.14 (VDD), U2.5 (OUT)
ADC1: JP1.1, U1.16 (ADC1)
ADC2: JP1.2, U1.15 (ADC2)
ADC3: JP1.3, U1.13 (ADC3)
CS: D2.C, JP2.7
GND: C1.2, C2.2, C3.2, JP2.3, R1.1, U1.5 (GND), U1.10 (RES(GND)), U1.12 (GND), U2.2 (GND)
INT1: JP2.8, U1.11 (INT1)
unnamed: D2.A, R8.1, U1.8 (CS)
SCL: JP2.4, Q2.3 (D), R5.1
SCL_3.3V: Q2.2 (S), R3.1, U1.4 (SCL)
SDA: JP2.5, Q1.3 (D), R4.1
SDA_3.3V: Q1.2 (S), R2.1, U1.6 (SDA)
SDO: JP2.6, R1.2, U1.7 (SDO)
VIN: C3.1, JP2.1, R4.2, R5.2, U2.1 (IN), U2.3 (EN)

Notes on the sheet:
I2C
SCL (Pin 4) = Serial Clock
SDA (Pin 6) = Serial Data
SD0 (Pin 7) = SA0/Address LSB
* CS needs to be set off board to select SPI or I2C
CS High = I2C, Low = SPI
Defaults to I2C as-is (R8)
SDO pulled low by default (R1) to set I2C address LSB to 0
Bus Selection
SPI
SDA (Pin 6) = Data In (MOSI)
SDO (Pin 7) = Data Out (MISO)
Set SJ1 to make I2C
address LSB 1

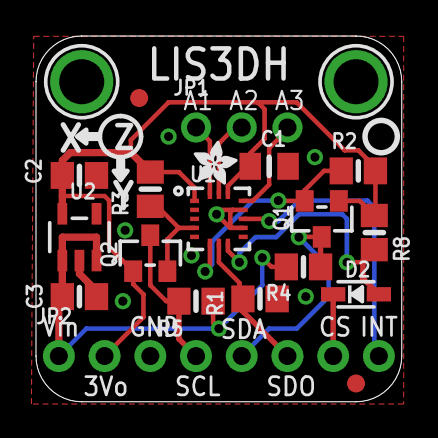
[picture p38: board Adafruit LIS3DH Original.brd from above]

Board: 2 copper layers, 20.3 x 20.3 mm, 23 parts (1 on the bottom side), 14 nets.

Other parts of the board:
U$9: PCBFEAT-REV-040
U$21: ADAFRUIT_2.5MM
U$22: ADAFRUIT_5MM

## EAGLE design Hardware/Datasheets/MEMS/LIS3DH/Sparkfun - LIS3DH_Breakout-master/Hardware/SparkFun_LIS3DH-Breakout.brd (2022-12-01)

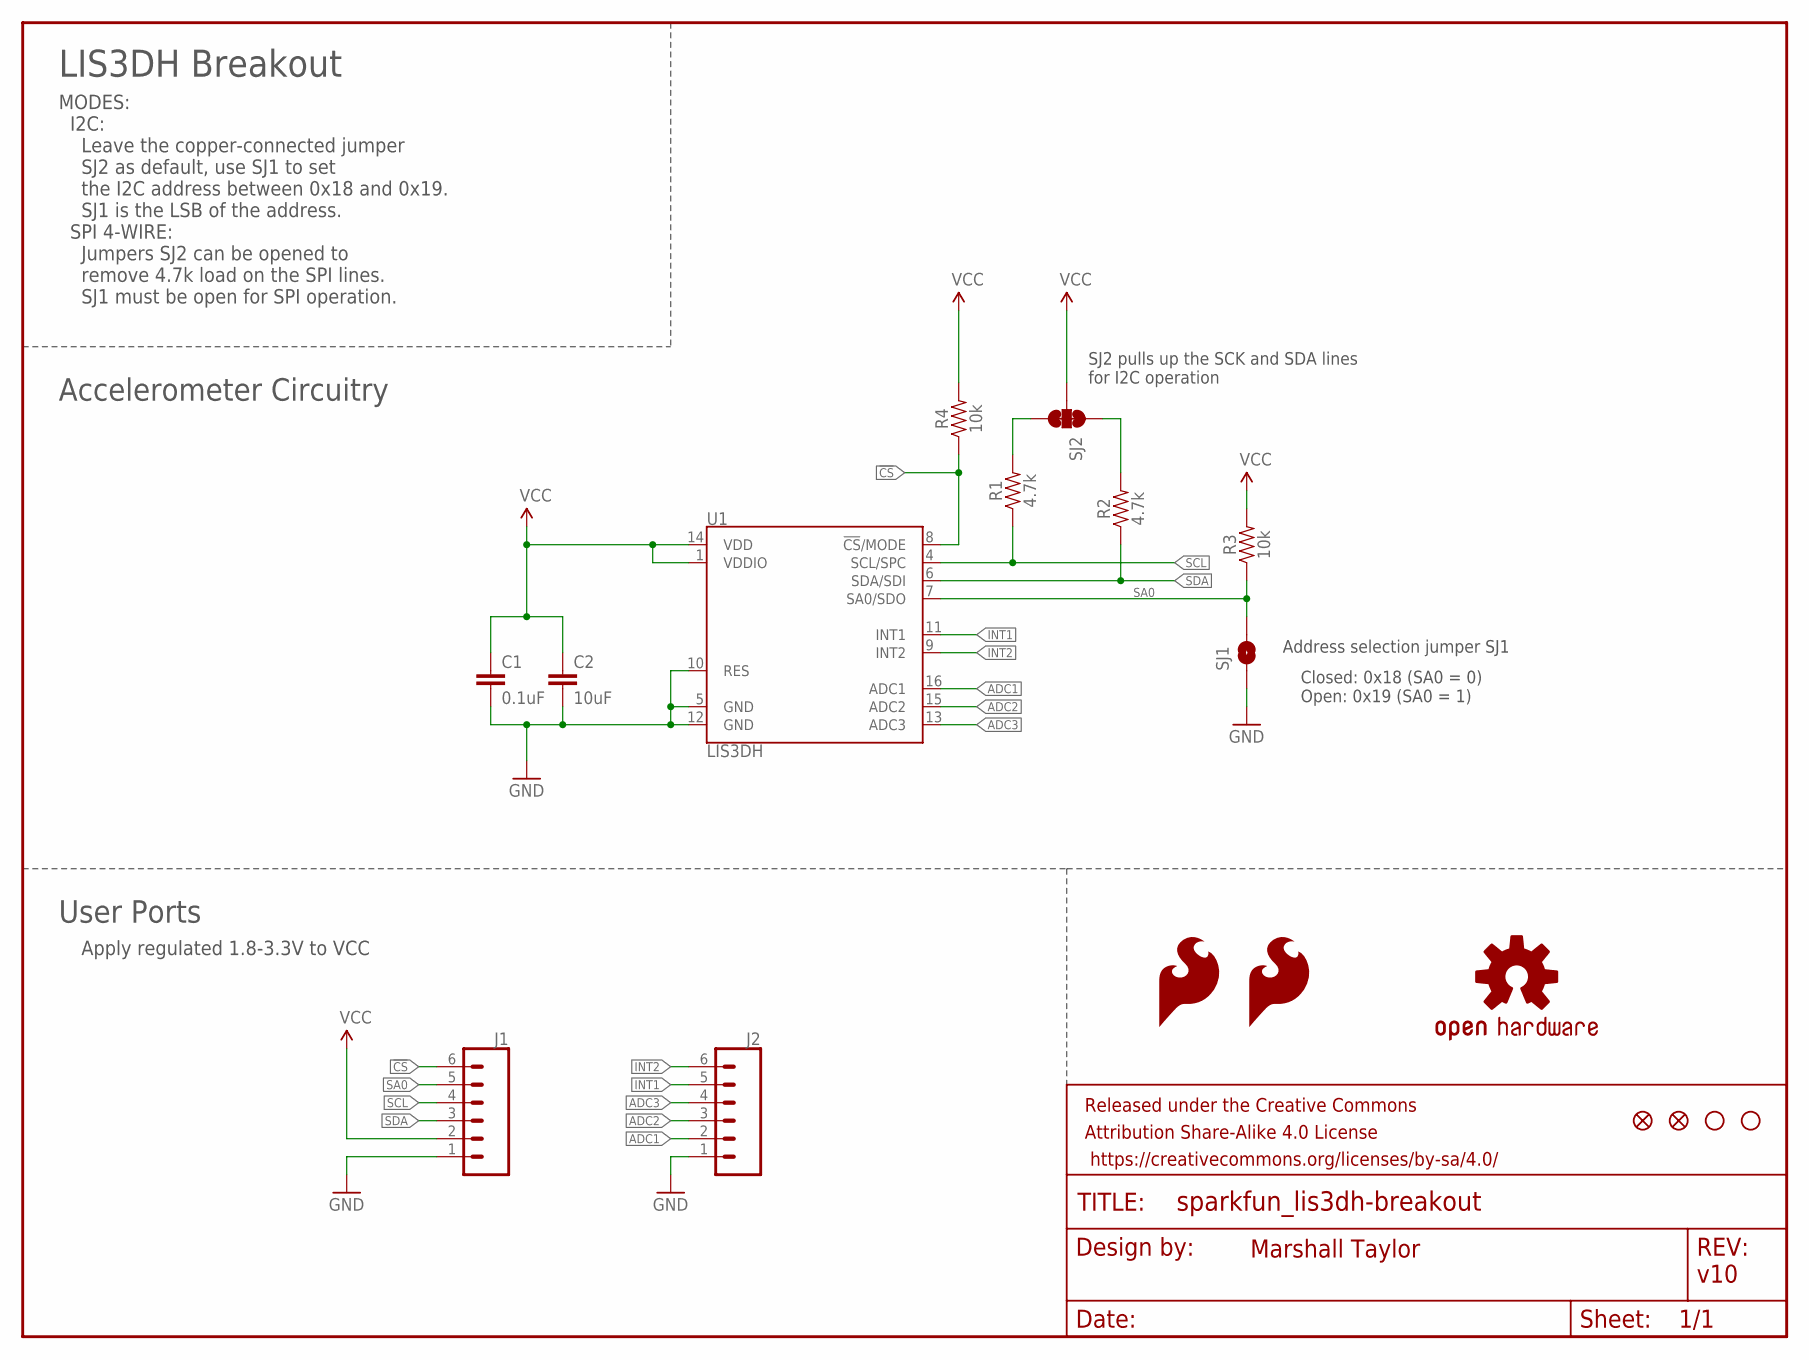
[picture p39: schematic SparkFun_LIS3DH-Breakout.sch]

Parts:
C1: 0.1uF; 0402
C2: 10uF; 0603
FRAME2: FRAME-LETTER; CREATIVE_COMMONS
J1, J2: CONN_06NO_SILK_FEMALE_PTH; 1X06_NO_SILK
JP2, JP6: FIDUCIALUFIDUCIAL; MICRO-FIDUCIAL
JP3, JP4: STAND-OFF
LOGO1, LOGO2: SFE_LOGO_FLAME.1_INCH; SFE_LOGO_FLAME_.1
R1, R2: 4.7k; 0603
R3, R4: 10k; 0603
SJ1: SOLDERJUMPERNO; SJ_2S-NO
SJ2: JUMPER-PAD-3-NC_BY_TRACE; PAD-JUMPER-3-3OF3_NC_BY_TRACE_YES_SILK_FULL_BOX
U1: LIS3DH; LGA-16-3X3
U$1: OSHW-LOGOS; OSHW-LOGO-S

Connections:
!CS: J1.6, R4.1, U1.8 (!CS!/MODE)
ADC1: J2.2, U1.16 (ADC1)
ADC2: J2.3, U1.15 (ADC2)
ADC3: J2.4, U1.13 (ADC3)
GND: C1.2, C2.2, J1.1, J2.1, SJ1.1, U1.5 (GND), U1.10 (RES), U1.12 (GND)
INT1: J2.5, U1.11 (INT1)
INT2: J2.6, U1.9 (INT2)
unnamed: R2.2, SJ2.1
unnamed: R1.2, SJ2.3
SA0: J1.5, R3.1, SJ1.2, U1.7 (SA0/SDO)
SCL: J1.4, R1.1, U1.4 (SCL/SPC)
SDA: J1.3, R2.1, U1.6 (SDA/SDI)
VCC: C1.1, C2.1, J1.2, R3.2, R4.2, SJ2.2, U1.1 (VDDIO), U1.14 (VDD)

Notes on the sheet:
Closed: 0x18 (SA0 = 0) Open: 0x19 (SA0 = 1)
Address selection jumper SJ1
v10
Marshall Taylor
LIS3DH Breakout
SJ2 pulls up the SCK and SDA lines for I2C operation
MODES: I2C: Leave the copper-connected jumper SJ2 as default, use SJ1 to set the I2C address between 0x18 and 0x19. SJ1 is the LSB of the address. SPI 4-WIRE: Jumpers SJ2 can be opened to remove 4.7k load on the SPI lines. SJ1 must be open for SPI operation.
Accelerometer Circuitry
User Ports
Apply regulated 1.8-3.3V to VCC

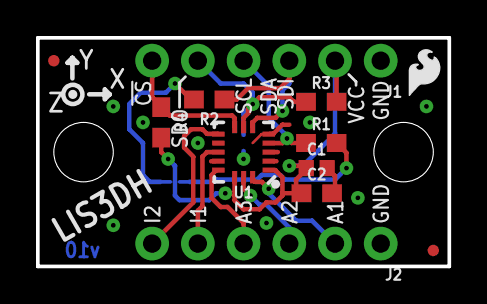
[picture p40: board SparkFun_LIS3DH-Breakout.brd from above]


Board: 2 copper layers, 22.9 x 12.7 mm, 19 parts (4 on the bottom side), 13 nets.

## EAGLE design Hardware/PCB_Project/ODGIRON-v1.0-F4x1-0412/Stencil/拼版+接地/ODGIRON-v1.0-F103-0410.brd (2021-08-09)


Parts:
AMP1: SGM8551XN5G/TR; SOT23-5
BUZ1: BUZZERBUZZER_5020; BUZZER_5020
C1, C2, C3, C4, C5, C6, C10, C11, C12, C13, C14, C16, C29: 0.1uF/50V; C0603
C7, C23: 4.7uF/10V; C0603
C8, C9: 10pF/50V; C0603
C15, C21, C22, C24, C31, C39: 1uF/16V; C0603
C17, C27: 10nF/50V; C0603
C18, C19: 470pF/50V; C0603
C20, C25, C26, C37: 10uF/10V; C0603
C30: 10uF/25V; C0805
C32: 100pF; C0603
C33: 4.7uF/50V; C0805
C34: 100pF/50V; C0603
CP1: FUSE_CLIPS_01
D1, D7, D9: B5819WS; SOD-323
D2, D5: SMF24A; SOD-123
D3: MMSZ5242BS-7-F; SOD-323
D6, D8: ESD5B5.0ST1; SOD-523
DA1: INA226; MSOP10
FB1, FB2, FB3, FB4, FB5: 1K; F0603
J3: USB_C_LONG-SYMBOL2-LAYER; USB-C-16P
L1: 33uH CBC3225T330KR; SMD,3.2X2.5X2.5MM
LCD1: 0.87inch SSD1316; 0.87INCH_128X32_OLED_SSD1306
LOGO1: OSHW-LOGONO_SILK; DUMMY
PAD1, PAD2, PAD3, PAD4, PAD5, PAD6, PAD7, PAD8, PAD9, PAD10, PAD11, PAD12: PADTP16SQ; TP16SQ
Q2, Q3: AON7403; DFN8P-0.65-3X3X0.8MM
Q4: 600mA/40V; SOT23-3
R1, R13: 32.4K; R0603
R2: 124K; R0603
R3, R10, R16, R18, R19, R22, R25, R35: 4.7K; R0603
R4: 1.5K; R0603
R5, R6, R27, R28: 22R; R0603
R7, R12, R23, R41, R45: 1K; R0603
R8, R20, R42: 100K; R0603
R9, R11, R14, R38: 10K; R0603
R17: 560K; R0603
R24: 10mR ±1% ±50ppm/°C; R1206
R36, R37: 10R; R0603
R43: 2.37K ±0.1% ±25ppm/℃; R0603
R44: 750K ±0.1% ±25ppm/℃; R0603
S1, S2, S3, S5: TAC_SWITCHSMD; TACTILE_SWITCH_SMD
T1: HAKKO_T12_K-TYPE_WITH_FUSE_CLIPS_X2
TP1: PGND; TESTPOINT_ROUND_2MM
TP5: SWO; PAD.03X.03
U1: FUSB302BMPX; QFN14-2.5X2.5MM
U3: STM32F103CBU6; QFN48_7X7MM_0.5MM
U4: MP2456GJ; SOT23-6
U5: MCP9700AT-E/TT; SOT23-3@1
U6: MCP1700T-3302E/TT; SOT23-3
U8: LIS3DH; LGA-16-3X3
VD1: USBLC6-2SC6; SOT23-6
ZO1: 8MHz; 3.2X2.5_KX-7

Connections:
3.9V: C30.1, C32.1, FB1.1, L1.2, R2.1
+3V3: C2.1, C4.1, C5.1, C12.2, C13.2, C14.2, C15.1, C20.2, C23.2, C24.2, C37.2, C39.2, DA1.6 (VS), FB2.2, FB3.2, LCD1.5 (VBAT), LCD1.8 (VDD), R3.1, R4.2, R13.2, R16.1, R18.2, R19.2, R22.2, R23.2, R25.1, R38.1, S3.3, S3.4, U1.3 (VDD_01), U1.4 (VDD_02), U3.1 (VBAT), U3.24 (VDD_1), U3.36 (VDD_2), U3.48 (VDD_3), U5.1 (VDD), U6.2 (VO), U8.1 (VDDIO), U8.14 (VDD)
ADC1: U8.16 (ADC1)
ADC2: U8.15 (ADC2)
ADC3: U8.13 (ADC3)
AMP+: AMP1.3 (+IN), R42.1
AMP-: AMP1.4 (-IN), C34.2, R43.1, R44.2
BS: C29.1, U4.1 (BS)
CC1: C18.1, D8.K (C), J3.A5 (CC1), U1.1 (CC2_01), U1.14 (CC2_02)
CC2: C19.1, D6.K (C), J3.B5 (CC2), U1.10 (CC1_01), U1.11 (CC1_02)
CS: U8.8 (!CS!/MODE)
D+: J3.A6 (D+), J3.B6 (D+), VD1.3
D-: J3.A7 (D-), J3.B7 (D-), VD1.1
DCDC_IN: C33.1, D1.C, R20.2, U4.5 (IN)
EN: R20.1, U4.4 (EN)
GND: AMP1.2 (V-), BUZ1.- (LEAD-), C2.2, C3.2, C4.2, C5.2, C6.2, C7.2, C8.1, C9.1, C10.2, C11.1, C12.1, C13.1, C14.1, C15.2, C16.1, C18.2, C19.2, C20.1, C23.1, C24.1, C25.2, C26.2, C27.2, C30.2, C31.1, C33.2, C37.1, C39.1, D2.A, D5.A, D6.A, D7.A, D8.A, D9.A, DA1.1 (A1), DA1.2 (A0), DA1.7 (GND), FB4.1, FB4.2, J3.GND, J3.GND2 (GND), J3.SHLD1 (SHLD), J3.SHLD2 (SHLD), J3.SHLD3 (SHLD), J3.SHLD4 (SHLD), J3.SHLD5 (SHLD), J3.SHLD6 (SHLD), J3.SHLD7 (SHLD), J3.SHLD8 (SHLD), LCD1.7 (VSS), PAD5.TP, PAD6.TP, PAD7.TP, PAD8.TP, Q4.2 (E), R1.1, R8.2, R12.1, R17.1, R43.2, S1.1, S1.2, S2.1, S2.2, S5.1, S5.2, T1.1A1, T1.1B1, U1.8 (GND_01), U1.9 (GND_02), U1.THERMAL (GND_03), U3.8 (VSSA/VREF-), U3.20 (PB2/BOOT1), U3.23 (VSS_1), U3.35 (VSS_2), U3.47 (VSS_3), U3.P$1 (VSS_1), U4.2 (GND), U5.3 (GND), U6.1 (GND), U8.5 (GND), U8.10 (RES), U8.12 (GND), VD1.2, ZO1.2, ZO1.4
LDO_IN: C31.2, FB1.2, U6.3 (VI)
unnamed: R4.1, R5.1, R27.1, VD1.4
unnamed: R7.2, S3.1, S3.2
unnamed: D3.C, Q2.1 (S), Q2.2 (S), Q2.3 (S), Q3.1 (S), Q3.2 (S), Q3.3 (S)
unnamed: C21.1, LCD1.1 (C2+)
unnamed: D3.A, Q2.4 (G), Q3.4 (G), R10.2, R35.1
unnamed: C22.1, LCD1.3 (C1+)
unnamed: C11.2, FB2.1, U3.9 (VDDA)
unnamed: C3.1, R9.2, S1.3, S1.4
unnamed: C21.2, LCD1.2 (C2-)
unnamed: C6.1, R14.2, S2.3, S2.4
unnamed: C22.2, LCD1.4 (C1-)
unnamed: C25.1, LCD1.13 (VCOMH)
unnamed: LCD1.12 (IREF), R17.2
unnamed: C26.1, LCD1.14 (VCC)
unnamed: Q4.1 (B), R11.1
unnamed: C32.2, R1.2, R2.2, U4.3 (FB)
unnamed: C16.2, Q4.3 (C), R35.2
unnamed: C17.1, R11.2, R12.2
unnamed: AMP1.5 (V+), FB3.1
unnamed: R6.1, R28.1, VD1.6
unnamed: FB5.1, U1.2 (VBUS)
unnamed: C1.1, DA1.10 (IN+), R36.1
unnamed: C1.2, DA1.9 (IN-), R37.1
unnamed: R41.2, U5.2 (VOUT)
NRST: C10.1, R23.1, S5.3, S5.4, U3.7 (NRST)
OSC_IN: C8.2, U3.5 (PF0/OSC_IN), ZO1.3
OSC_OUT: C9.2, U3.6 (PF1/OSC_OUT\), ZO1.1
OUT: AMP1.1 (OUT), C34.1, R44.1, R45.2
PA0: U3.10 (PA0)
PA1: U3.11 (PA1)
PA2/ADC2: R41.1, U3.12 (PA2)
PA3/T2C4: C17.2, U3.13 (PA3)
PA4: U3.14 (PA4)
PA5: U3.15 (PA5)
PA6: U3.16 (PA6)
PA7/T1CH1N/T3C2: BUZ1.+ (LEAD+), U3.17 (PA7)
PA8/T1C1: U3.29 (PA8)
PA9/T1C2: U3.30 (PA9)
PA10/IT_ACCEL_1: U3.31 (PA10), U8.11 (INT1)
PA11/USB_DM: R6.2, U3.32 (PA11)
PA12/USB_DP: R5.2, U3.33 (PA12)
PA13/SWDIO: R27.2, U3.34 (PA13)
PA14/SWCLK: R28.2, U3.37 (PA14)
PA15: U3.38 (PA15)
PB0/ADC8: R45.1, U3.18 (PB0)
PB1/IT_FUSB302: R16.2, U1.5 (!INT), U3.19 (PB1)
PB3/IT_ACCEL_2: TP5.P$1, U3.39 (PB3), U8.9 (INT2)
PB4: U3.40 (PB4)
PB5: U3.41 (PB5)
PB6/SCL1: LCD1.10 (SCL), R19.1, U3.42 (PB6)
PB7/SDA1: LCD1.11 (SDA), R18.1, U3.43 (PB7)
PB8&BOOT0_S3: R7.1, R8.1, U3.44 (BOOT0), U3.45 (PB8)
PB9/S1: R9.1, U3.46 (PB9)
PB10/SCL2: DA1.5 (SCL), R3.2, U1.6 (SCL), U3.21 (PB10), U8.4 (SCL/SPC)
PB11/SDA2: DA1.4 (SDA), R25.2, U1.7 (SDA), U3.22 (PB11), U8.6 (SDA/SDI)
PB12: U3.25 (PB12)
PB13/IT_INA226: DA1.3 (ALERT), R38.2, U3.26 (PB13)
PB14/MISO2: U3.27 (PB14)
PB15/S2: R14.1, U3.28 (PB15)
PC13: U3.2 (PC13)
PC14/OSC32_IN: U3.3 (PC14/OSC32_IN)
PC15/OSC32_OUT: U3.4 (PC15/OSC32_OUT)
PGND: CP1.1A, CP1.1B, PAD9.TP, PAD10.TP, PAD11.TP, PAD12.TP, TP1.P$1
RES_3.3V: C7.1, LCD1.9 (RES#), R22.1
SAO/SDO/ADDR: U8.7 (SA0/SDO)
SW: C29.2, D7.C, L1.1, U4.6 (SW)
T12+: C27.1, D9.C, PAD1.TP, PAD2.TP, PAD3.TP, PAD4.TP, Q3.5 (D), Q3.6 (D), Q3.7 (D), Q3.8 (D), Q3.9 (D), R13.1, R42.2, T1.1A, T1.1B
VBREF: LCD1.6 (VBREF)
VBUS-C: D1.A, FB5.2, Q2.5 (D), Q2.6 (D), Q2.7 (D), Q2.8 (D), Q2.9 (D), R10.1, R24.1, R37.2
VUSB_IN: D2.C (K), D5.C (K), DA1.8 (VBUS), J3.VBUS1 (VBUS), J3.VBUS2 (VBUS), R24.2, R36.2

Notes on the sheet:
I2C地址：0x09
VCONN从电源取电，当线缆里有eMarker芯片时，给它供电（3.3V或5V）
R1=R2/(Vout/0.812-1) Vout = 3.9V, R1:R2 = 1:3.8 R1 R2 32.4K 124K
exchange is ok
I2C2_PULLUP
I2C1_PULLUP
Do not need pull up
OldGerman
v1.0
I2C1
I2C2
Accel： INT2:支持敲击中断，活动中断 INT1:不支持活动中断，支持某轴Data中断
1K小于ADC在14MHz下 1.5Cycles采样周期的输入源阻抗
INT
https://github.com/oldgerman/ODGIRON-PD-T12 https://github.com/Ralim/IronOS https://oldgerman.github.io/
I2C地址：0x3C



Board: 2 copper layers, 89.8 x 17.6 mm, 121 parts (56 on the bottom side), 66 nets.

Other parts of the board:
U$3: CREATIVE_COMMONS

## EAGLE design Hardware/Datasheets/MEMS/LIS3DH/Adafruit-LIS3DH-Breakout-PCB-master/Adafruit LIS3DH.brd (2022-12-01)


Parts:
C1: 0.1uF; 0603-NO
C2, C3: 10uF; 0805-NO
CONN3, CONN4: STEMMA_I2C_QT; JST_SH4
D1: GREEN; CHIPLED_0603_NOOUTLINE
D2: 1N4148; SOD-323
FID3, FID4: FIDUCIAL_1MM
JP2, JP3: HEADER-1X670MIL; 1X06_ROUND_70
Q2: BSS138; SOT363
R1, R3: 10K; RESPACK_4X0603
SJ1: SOLDERJUMPER; SOLDERJUMPER_ARROW_NOPASTE
U1: LIS3DHTR; LGA16_3X3MM
U2: AP2112K-3.3; SOT23-5
U$1, U$17, U$19, U$21: MOUNTINGHOLE2.5; MOUNTINGHOLE_2.5_PLATED

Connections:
3.3V: C1.1, C3.1, JP3.2, Q2.2 (G), Q2.5 (G), R1.1, R1.5 (2), R1.7 (2), R1.8 (2), R3.2 (1), R3.4 (1), SJ1.1, U1.1 (VDDIO), U1.14 (VDD), U2.5 (OUT)
ADC1: JP2.3, U1.16 (ADC1)
ADC2: JP2.4, U1.15 (ADC2)
ADC3: JP2.5, U1.13 (ADC3)
CS: D2.C, JP2.1
GND: C1.2, C2.2, C3.2, CONN3.1 (GND), CONN4.1 (GND), D1.C, JP3.3, R1.6 (2), U1.5 (GND), U1.10 (RES(GND)), U1.12 (GND), U2.2 (GND)
INT1: JP3.6, U1.11 (INT1)
INT2: JP2.6, U1.9 (INT2)
unnamed: D1.A, R1.4 (1)
unnamed: D2.A, R1.2 (1), U1.8 (CS)
SCL: CONN3.4 (SCL), CONN4.4 (SCL), JP3.4, Q2.6 (D), R3.8 (2)
SCL_3V: Q2.1 (S), R3.7 (2), U1.4 (SCL)
SDA: CONN3.3 (SDA), CONN4.3 (SDA), JP3.5, Q2.3 (D), R3.6 (2)
SDA_3V: Q2.4 (S), R3.5 (2), U1.6 (SDA)
SDO: JP2.2, R1.3 (1), SJ1.2, U1.7 (SDO)
VCC: C2.1, CONN3.2 (V+), CONN4.2 (V+), JP3.1, R3.1, R3.3 (1), U2.1 (IN), U2.3 (EN)

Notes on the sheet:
I2C Pullups & Shift
STEMMA/I2C Headers
ON LED
Power supply
I2C
SCL (Pin 4) = Serial Clock
SDA (Pin 6) = Serial Data
SD0 (Pin 7) = SA0/Address LSB
* CS needs to be set off board to select SPI or I2C
CS High = I2C, Low = SPI
Defaults to I2C as-is (R8)
SDO pulled low by default (R1) to set I2C address LSB to 0
Bus Selection
SPI
SDA (Pin 6) = Data In (MOSI)
SDO (Pin 7) = Data Out (MISO)
Set SJ1 to make I2C
address LSB 1



Board: 2 copper layers, 17.8 x 25.4 mm, 25 parts (4 on the bottom side), 16 nets.

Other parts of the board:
U$12: ADAFRUIT_2.5MM
U$25: PCBFEAT-REV-040
U$30, U$31: STEMMAQT

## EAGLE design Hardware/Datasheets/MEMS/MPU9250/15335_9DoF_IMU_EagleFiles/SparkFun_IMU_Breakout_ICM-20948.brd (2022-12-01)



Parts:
C1, C4: 1.0uF; 0603
C2, C3: 0.1uF; 0603
D1: RED; LED-0603
FD1, FD2, FD3, FD4: FIDUCIAL1X2; FIDUCIAL-1X2
FRAME2: FRAME-LEDGER; CREATIVE_COMMONS
H1, H2, H3, H4: STAND-OFF
J1, J2: QWIIC_CONNECTORJS-1MM; JST04_1MM_RA
J3, J4: CONN_06NO_SILK_NO_POP; 1X06_NO_SILK
JP2: ADR; SMT-JUMPER_2_NO_SILK
JP3: AUX; SMT-JUMPER_3_2-NC_TRACE_SILK
JP4: I2C PU; SMT-JUMPER_3_2-NC_TRACE_SILK
JP5: LED; SMT-JUMPER_2_NC_TRACE_SILK
LOGO1: SFE_LOGO_NAME_FLAME.1_INCH; SFE_LOGO_NAME_FLAME_.1
LOGO2: OSHW-LOGOMINI; OSHW-LOGO-MINI
Q2, Q4, Q6, Q8, Q10, Q12, Q14, Q16: 20V/0.2A/8MHz/1.2Ω/1Vth; SOT-416FL
R9: 220; 0603
R10, R11, R12, R13, R14, R15, R16, R17, R18, R19, R20, R21, R22, R23, R24, R25: 2.2k; 0402-TIGHT
TP1: 1.8V; PAD.03X.03
U2: 9DoF IMU; QFN24-3X3
U3: 1.8V/100mA; SC70

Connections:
1.8V: C1.1, C2.1, D1.A, Q2.1 (G), Q4.1 (G), Q6.1 (G), Q8.1 (G), Q10.1 (G), Q12.1 (G), Q14.1 (G), Q16.1 (G), R10.2, R12.2, R14.2, R16.2, R18.2, R20.2, R22.2, R24.2, TP1.P$1, U2.8 (VDDIO), U2.13 (VDD), U3.5 (OUT)
!CS: Q2.2 (S), R10.1, U2.22 (!CS)
!CS!_VIN: J3.6, Q2.3 (D), R11.1
AD0/SDO: Q4.2 (S), R12.1, U2.9 (AD0/SDO)
AD0/SDO_VIN: J3.5, JP2.2, Q4.3 (D), R13.1
AUX_CL: Q12.2 (S), R20.1, U2.7 (AUX_CL)
AUX_CL_VIN: J4.5, Q12.3 (D), R21.1
AUX_DA: Q10.2 (S), R18.1, U2.21 (AUX_DA)
AUX_DA_VIN: J4.4, Q10.3 (D), R19.1
FSYNC: Q14.2 (S), R22.1, U2.11 (FSYNC)
FSYNC_VIN: J4.3, Q14.3 (D), R23.1
GND: C1.2, C2.2, C3.2, C4.2, J1.1, J2.1, J3.1, J4.1, JP2.1, JP5.1, U2.18 (GND), U2.20 (GND), U3.2 (GND)
INT: Q16.2 (S), R24.1, U2.12 (INT)
INT_VIN: J4.2, Q16.3 (D), R25.1
unnamed: C3.1, U2.10 (REGOUT)
unnamed: JP4.3, R15.2
unnamed: JP4.1, R17.2
unnamed: JP3.1, R21.2
unnamed: JP3.3, R19.2
unnamed: D1.C, R9.2
unnamed: JP5.2, R9.1
SCL/SCLK: Q6.2 (S), R14.1, U2.23 (SCL/SCLK)
SCL/SCLK_VIN: J1.4, J2.4, J3.4, Q6.3 (D), R15.1
SDA/SDI: Q8.2 (S), R16.1, U2.24 (SDA/SDI)
SDA/SDI_VIN: J1.3, J2.3, J3.3, Q8.3 (D), R17.1
VIN: C4.1, J1.2, J2.2, J3.2, J4.6, JP3.2, JP4.2, R11.2, R13.2, R23.2, R25.2, U3.1 (IN), U3.3 (EN)

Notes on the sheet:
VIN 1.8V to 5.5V
IMU (ICM-20948)
I2C Level Shifting + Pullup Disconnects
Connections
Voltage Regulator
SPI / Interrupt Level Shifting
ADR -> I2C Address ------------------- open -> 0x69 closed -> 0x68 *Closing AD0 precludes SPI
Optionally disconnect the I2C pullup resistors on the primary and auxillary busses in case of too strong pullup from other sources
Cut to disable PWR LED
Address Option



Board: 2 copper layers, 25.4 x 25.4 mm, 104 parts (36 on the bottom side), 26 nets.

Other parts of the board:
U$1, U$2, U$22, U$24: GND4
U$3: PWR0
U$4, U$21: INT3
U$5, U$20: FSNC2
U$6, U$19: ACL1
U$7, U$18: ADA0
U$8: MISO13
U$9: MOSI14
U$10: SCLK15
U$11: #CS16
U$12: 1V8#5V57
U$13, U$30, U$44: VIN5
U$14: NC17
U$15: CL4
U$16: DA2
U$17: AD012
U$23: ADR2
U$25: I2C_PU21
U$26: SPI19
U$27: AUX_PU24
U$28: SFE_LOGO_FLAME_.1
U$29: LED23
U$31: ICM#2094820
U$34, U$40, U$50, U$57: X0
U$35, U$41, U$51, U$58: Y1
U$36, U$42, U$52, U$59: Z2
U$37, U$60: G5
U$38, U$61: A4
U$39, U$49: M3
U$43: QWIIC_9DOF_IMU_0
U$45: I#C1

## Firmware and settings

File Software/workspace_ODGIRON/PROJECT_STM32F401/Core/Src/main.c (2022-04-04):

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
/* Includes ------------------------------------------------------------------*/
#include "main.h"
#include "cmsis_os.h"
#include "usb_device.h"
#include "usb_device.h"

/* USER CODE BEGIN Includes */
#include "usbd_cdc_if.h"
#include "BSP.h"
#include "LIS3DH.hpp"
#include "Settings.h"
#include "power.hpp"
#include "Setup.h"
#include "Translation.h"
#include "Threads.hpp"
/* USER CODE END Includes */

ADC_HandleTypeDef hadc1;
DMA_HandleTypeDef hdma_adc1;

I2C_HandleTypeDef hi2c1;
I2C_HandleTypeDef hi2c3;
DMA_HandleTypeDef hdma_i2c1_rx;
DMA_HandleTypeDef hdma_i2c1_tx;

IWDG_HandleTypeDef hiwdg;

TIM_HandleTypeDef htim1;
TIM_HandleTypeDef htim2;
TIM_HandleTypeDef htim3;

osThreadId PIDTaskHandle;
uint32_t PIDTaskBuffer[ 256 ];
osStaticThreadDef_t PIDTaskControlBlock;
osThreadId MOVTaskHandle;
uint32_t MOVTaskBuffer[ 128 ];
osStaticThreadDef_t MOVTaskControlBlock;
osThreadId POWTaskHandle;
uint32_t POWTaskBuffer[ 256 ];
osStaticThreadDef_t POWTaskControlBlock;
osThreadId GUITaskHandle;
uint32_t GUITaskBuffer[ 512 ];
osStaticThreadDef_t GUITaskControlBlock;
/* USER CODE BEGIN PV */
bool    settingsWereReset            = false;
uint16_t GUITask_stacksize = 0;
uint16_t PIDTask_stacksize = 0;
uint16_t MOVTask_stacksize = 0;
uint16_t POWTask_stacksize = 0;
/* USER CODE END PV */

void SystemClock_Config(void);
static void MX_GPIO_Init(void);
static void MX_DMA_Init(void);
static void MX_ADC1_Init(void);
static void MX_I2C1_Init(void);
static void MX_I2C3_Init(void);
static void MX_TIM1_Init(void);
static void MX_IWDG_Init(void);
static void MX_TIM2_Init(void);
static void MX_TIM3_Init(void);
void StartPIDTask(void const * argument);
void StartMOVTask(void const * argument);
void StartPOWTask(void const * argument);
void StartGUITask(void const * argument);

/**
  * @brief  The application entry point.
  * @retval int
  */
int main(void)
{
  /* MCU Configuration--------------------------------------------------------*/

  /* Reset of all peripherals, Initializes the Flash interface and the Systick. */
  HAL_Init();

  /* Configure the system clock */
  SystemClock_Config();

  /* USER CODE BEGIN SysInit */
  //__HAL_RCC_I2C3_CLK_ENABLE();
  //__HAL_RCC_I2C1_CLK_ENABLE();

  //USB_Status_Init();	//不需要，DFU已经执行过一�???????

  /* USER CODE END SysInit */

  /* Initialize all configured peripherals */
  MX_GPIO_Init();
  MX_DMA_Init();
  MX_ADC1_Init();
  MX_I2C1_Init();
  MX_I2C3_Init();
  MX_TIM1_Init();
  MX_IWDG_Init();
  MX_TIM2_Init();
  MX_TIM3_Init();
  /* USER CODE BEGIN 2 */

  MX_USB_DEVICE_Init();
  resetWatchdog();

  preRToSInit();		// 初始化i2c实例

  HAL_ADC_Start(&hadc1);
  //注意，半字节模式DMA传输的数据是32
  HAL_ADC_Start_DMA(&hadc1, ADCReadings, (ADC_SAMPLES * ADC_CHANNELS));	//ADC handle of ADC master (handle of ADC slave must not be used)
  HAL_ADCEx_InjectedStart(&hadc1);       // enable injected readings
  HAL_ADCEx_InjectedStart_IT(&hadc1);
  resetWatchdog();
  /* USER CODE END 2 */

  /* USER CODE BEGIN RTOS_MUTEX */
  /* add mutexes, ... */
  /* USER CODE END RTOS_MUTEX */

  /* USER CODE BEGIN RTOS_SEMAPHORES */
  /* add semaphores, ... */
  /* USER CODE END RTOS_SEMAPHORES */

  /* USER CODE BEGIN RTOS_TIMERS */
  /* start timers, add new ones, ... */
  /* USER CODE END RTOS_TIMERS */

  /* USER CODE BEGIN RTOS_QUEUES */
  /* add queues, ... */
  /* USER CODE END RTOS_QUEUES */

  /* Create the thread(s) */
  /* definition and creation of PIDTask */
  osThreadStaticDef(PIDTask, StartPIDTask, osPriorityRealtime, 0, 256, PIDTaskBuffer, &PIDTaskControlBlock);
  PIDTaskHandle = osThreadCreate(osThread(PIDTask), NULL);

  /* definition and creation of MOVTask */
  osThreadStaticDef(MOVTask, StartMOVTask, osPriorityAboveNormal, 0, 128, MOVTaskBuffer, &MOVTaskControlBlock);
  MOVTaskHandle = osThreadCreate(osThread(MOVTask), NULL);

  /* definition and creation of POWTask */
  osThreadStaticDef(POWTask, StartPOWTask, osPriorityNormal, 0, 256, POWTaskBuffer, &POWTaskControlBlock);
  POWTaskHandle = osThreadCreate(osThread(POWTask), NULL);

  /* definition and creation of GUITask */
  osThreadStaticDef(GUITask, StartGUITask, osPriorityBelowNormal, 0, 512, GUITaskBuffer, &GUITaskControlBlock);
  GUITaskHandle = osThreadCreate(osThread(GUITask), NULL);

  /* USER CODE BEGIN RTOS_THREADS */
	GUITask_stacksize = os_thread_def_GUITask.stacksize;
	PIDTask_stacksize = os_thread_def_PIDTask.stacksize;
	MOVTask_stacksize = os_thread_def_MOVTask.stacksize;
	POWTask_stacksize = os_thread_def_POWTask.stacksize;
	resetWatchdog();
  /* add threads, ... */
  /* USER CODE END RTOS_THREADS */

  /* Start scheduler */
  osKernelStart();

  /* We should never get here as control is now taken by the scheduler */
  /* Infinite loop */
  /* USER CODE BEGIN WHILE */
  while (1)
  {
    /* USER CODE END WHILE */

    /* USER CODE BEGIN 3 */
  }
  /* USER CODE END 3 */
}

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
/* USER CODE BEGIN Header_StartPIDTask */
/**
  * @brief  Function implementing the PIDTask thread.
  * @param  argument: Not used
  * @retval None
  */
/* USER CODE END Header_StartPIDTask */
void StartPIDTask(void const * argument)
{
  /* init code for USB_DEVICE */
  MX_USB_DEVICE_Init();
  /* USER CODE BEGIN 5 */
  doPIDTask();
  /* Infinite loop */
  for(;;)
  {
    osDelay(1);
  }
  /* USER CODE END 5 */
}

/* USER CODE BEGIN Header_StartMOVTask */
/**
* @brief Function implementing the MOVTask thread.
* @param argument: Not used
* @retval None
*/
/* USER CODE END Header_StartMOVTask */
void StartMOVTask(void const * argument)
{
  /* USER CODE BEGIN StartMOVTask */
  doMOVTask();
  /* Infinite loop */
  for(;;)
  {
    osDelay(1);
  }
  /* USER CODE END StartMOVTask */
}

/* USER CODE BEGIN Header_StartPOWTask */
/**
* @brief Function implementing the POWTask thread.
* @param argument: Not used
* @retval None
*/
/* USER CODE END Header_StartPOWTask */
void StartPOWTask(void const * argument)
{
  /* USER CODE BEGIN StartPOWTask */
	doPOWTask();
  /* Infinite loop */
  for(;;)
  {
    osDelay(1);
  }
  /* USER CODE END StartPOWTask */
}

/* USER CODE BEGIN Header_StartGUITask */
/**
* @brief Function implementing the GUITask thread.
* @param argument: Not used
* @retval None
*/
/* USER CODE END Header_StartGUITask */
void StartGUITask(void const * argument)
{
  /* USER CODE BEGIN StartGUITask */
	doGUITask();
  /* Infinite loop */
  for(;;)
  {
    osDelay(1);
  }
  /* USER CODE END StartGUITask */
}

/**
  * @brief  Period elapsed callback in non blocking mode
  * @note   This function is called  when TIM4 interrupt took place, inside
  * HAL_TIM_IRQHandler(). It makes a direct call to HAL_IncTick() to increment
  * a global variable "uwTick" used as application time base.
  * @param  htim : TIM handle
  * @retval None
  */
void HAL_TIM_PeriodElapsedCallback(TIM_HandleTypeDef *htim)
{
  /* USER CODE BEGIN Callback 0 */
	if (htim->Instance == TIM1) {
		//static uint32_t cnt_CC1 = 0;
#if 0
		usb_printf(
				"Ela TIM3:%d ARR= %d PSC= %d CCR1=%d CCR4=%d\r\n",
				cnt_CC1++, htim->Instance->ARR, htim->Instance->PSC,
				htim->Instance->CCR1, htim->Instance->CCR4);
#endif
		// we want to turn on the output again
		PWMSafetyTimer--;
		// We decrement this safety value so that lockups in the
		// scheduler will not cause the PWM to become locked in an
		// active driving state.
		// While we could assume this could never happen, its a small price for
		// increased safety

		htim1.Instance->CCR1 = pendingPWM;
		if(!htim1.Instance->CCR1)
			htim1.Instance->CCR1 = 1;	//鏋佸皬鍗犵┖姣斾互缁存寔绉诲姩鐢垫簮渚涚數涓嶄紤鐪狅紝鍜孒AL_TIM_PluseFinishedCallback鍑芥�???????????????
		if (htim1.Instance->CCR1 && PWMSafetyTimer) {
			HAL_TIM_PWM_Start(&htim2, TIM_CHANNEL_4);
		} else {
			HAL_TIM_PWM_Stop(&htim2, TIM_CHANNEL_4);
		}
	}
  /* USER CODE END Callback 0 */
  if (htim->Instance == TIM4) {
    HAL_IncTick();
  }
}

/**
  * @brief  This function is executed in case of error occurrence.
  * @retval None
  */
void Error_Handler(void)
{
  /* USER CODE BEGIN Error_Handler_Debug */
  /* User can add his own implementation to report the HAL error return state */

  /* USER CODE END Error_Handler_Debug */
}

#ifdef  USE_FULL_ASSERT
/**
  * @brief  Reports the name of the source file and the source line number
  *         where the assert_param error has occurred.
  * @param  file: pointer to the source file name
  * @param  line: assert_param error line source number
  * @retval None
  */
void assert_failed(uint8_t *file, uint32_t line)
{
  /* USER CODE BEGIN 6 */
  /* User can add his own implementation to report the file name and line number,
     tex: printf("Wrong parameters value: file %s on line %d\r\n", file, line) */
  /* USER CODE END 6 */
}
#endif /* USE_FULL_ASSERT */

/************************ (C) COPYRIGHT STMicroelectronics *****END OF FILE****/

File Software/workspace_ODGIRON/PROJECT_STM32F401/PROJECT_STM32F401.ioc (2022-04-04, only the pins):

Mcu.UserName=STM32F401CCUx
PA11.Signal=USB_OTG_FS_DM
PA12.Signal=USB_OTG_FS_DP
PA13.Signal=SYS_JTMS-SWDIO
PA14.Signal=SYS_JTCK-SWCLK
PA2.GPIO_Label=TREF_TEMP
PA2.Signal=ADCx_IN2
PA3.Signal=S_TIM2_CH4
PA7.GPIO_Label=BUZZER_OUT
PA7.Signal=S_TIM3_CH2
PA8.Signal=I2C3_SCL
PB0.GPIO_Label=TIP_TEMP
PB0.Signal=ADCx_IN8
PB1.GPIO_Label=IT_FUSB302B
PB1.Signal=GPXTI1
PB15.GPIO_Label=KEY_OK
PB15.Signal=GPIO_Input
PB3.Signal=SYS_JTDO-SWO
PB4.Signal=I2C3_SDA
PB6.Signal=I2C1_SCL
PB7.Signal=I2C1_SDA
PB8.GPIO_Label=KEY_B
PB8.Signal=GPIO_Input
PB9.GPIO_Label=KEY_A
PB9.Signal=GPIO_Input

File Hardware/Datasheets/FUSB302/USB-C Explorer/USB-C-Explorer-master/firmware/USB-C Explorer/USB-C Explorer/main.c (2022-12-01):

/* This source file is part of the ATMEL QTouch Library 5.0.8 */

/*****************************************************************************
 *
 * \file
 *
 * \brief  This file contains the SAMD QTouch library sample user application.
 *
 *
 * - Userguide:          QTouch Library Peripheral Touch Controller User Guide.
 * - Support email:      www.atmel.com/design-support/
 *
 *
 * Copyright (c) 2013-2015 Atmel Corporation. All rights reserved.
 *
 * \asf_license_start
 *
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
 * 3. The name of Atmel may not be used to endorse or promote products derived
 *    from this software without specific prior written permission.
 *
 * 4. This software may only be redistributed and used in connection with an
 *    Atmel microcontroller product.
 *
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
 * \asf_license_stop
 *
 ******************************************************************************/

/**
 * Include header files for all drivers that have been imported from
 * Atmel Software Framework (ASF).
 */
#include <asf.h>
#include "ugui.h"
#include "tcpm_driver.h"
#include "usb_pd_driver.h"

/**
 * Device Revision definition
 */
#define DEVICE_REVISION_MASK (0xFu << 8)
#define DEVICE_REVISION_MASK_POS (8u)
#define DEV_REV_A (0x0)
#define DEV_REV_B (0x1)
#define DEV_REV_C (0x2)

struct rtc_module rtc_instance;
struct tc_module tc_instance;
uint32_t g_us_timestamp_upper_32bit;
struct i2c_master_module i2c_master_instance;
uint32_t device_rev = 0;

// USB-C Specific - TCPM start 1
const struct tcpc_config_t tcpc_config[CONFIG_USB_PD_PORT_COUNT] = {
	{&i2c_master_instance, fusb302_I2C_SLAVE_ADDR, &fusb302_tcpm_drv},
};
// USB-C Specific - TCPM end 1

volatile uint8_t display_screen, display_needs_update, display_change_requested;
uint8_t display_buffer[MAX_SCREENS][DISP_MEM_SIZE];
UG_GUI gui;
timestamp_t last_button_timestamp;

/*
 * switch_main_clock 
 */
void switch_main_clock(void);

/*! \brief Initialize timer
 *
 */
void rtc_init( void );

/*! \brief RTC timer overflow callback
 *
 */
void rtc_overflow_callback(void);

/*! \brief Configure the RTC timer callback
 *
 */
void configure_rtc_callbacks(void);

/*! \brief Configure the RTC timer count after which interrupts comes
 *
 */
void configure_rtc_count(void);

/*! \brief Set timer period.Called from Qdebug when application
 *     has to change the touch time measurement
 */
void set_timer_period(void);

/*! \brief RTC timer overflow callback
 *
 */
void rtc_overflow_callback(void)
{
	/* Do something on RTC overflow here */
	touch_time.time_to_measure_touch = 1;
	touch_time.current_time_ms = touch_time.current_time_ms +
			touch_time.measurement_period_ms;
}

/*! \brief Configure the RTC timer callback
 *
 */
void configure_rtc_callbacks(void)
{
	/* register callback */
	rtc_count_register_callback(&rtc_instance,
			rtc_overflow_callback, RTC_COUNT_CALLBACK_OVERFLOW);
	/* Enable callback */
	rtc_count_enable_callback(&rtc_instance, RTC_COUNT_CALLBACK_OVERFLOW);
}

/*! \brief Configure the RTC timer count after which interrupts comes
 *
 */
void configure_rtc_count(void)
{
	struct rtc_count_config config_rtc_count;
	rtc_count_get_config_defaults(&config_rtc_count);
    #if ((SAMC20) || (SAMC21))
	config_rtc_count.prescaler           = RTC_MODE0_CTRLA_PRESCALER_DIV32;
    #else
	config_rtc_count.prescaler           = RTC_MODE0_CTRL_PRESCALER_DIV2;
    #endif
	config_rtc_count.mode                = RTC_COUNT_MODE_16BIT;
	#ifdef FEATURE_RTC_CONTINUOUSLY_UPDATED
	config_rtc_count.continuously_update = true;
	#endif
	/* initialize rtc */
	rtc_count_init(&rtc_instance, RTC, &config_rtc_count);

	/* enable rtc */
	rtc_count_enable(&rtc_instance);
}

/*! \brief Initialize timer
 *
 */
void rtc_init(void)
{
	/* Configure and enable RTC */
	configure_rtc_count();

	/* Configure and enable callback */
	configure_rtc_callbacks();

	/* Set Timer Period */

	rtc_count_set_period(&rtc_instance, DEF_TOUCH_MEASUREMENT_PERIOD_MS);
}

/*! \brief Set timer period.Called from Qdebug when application
 *     has to change the touch time measurement
 */
void set_timer_period(void )
{
	rtc_count_set_period(&rtc_instance, touch_time.measurement_period_ms);
}

void display_init(void);
void display_set_pixel(UG_S16 x, UG_S16 y, UG_COLOR color);
void i2c_init(void);
void timer_init(void);
void tc_callback_overflow(void);
void measure_nonPD_current(void);
void extint_detection_callback(void);

/*! \brief Main function
 *
 */
int main(void)
{
	system_init();
	irq_initialize_vectors();
	cpu_irq_enable();
	ioport_init();
	delay_init();
	rtc_init();
	touch_sensors_init();
	system_interrupt_enable_global();
	
	display_init();
	i2c_init();
	timer_init();
	delay_ms(50);
	// USB-C Specific - TCPM start 2
	tcpm_init(0);	//必须
	delay_ms(50);
	pd_init(0);		//必须
	delay_ms(50);
	ioport_set_pin_dir(USBC_INT_PIN, IOPORT_DIR_INPUT);//Microchip特有
	// USB-C Specific - TCPM end 2
	
	//system_set_sleepmode(SYSTEM_SLEEPMODE_STANDBY);
	
	measure_nonPD_current();//测量没有PD协议的最大电流
	delay_ms(50);

	// Start USB stack to authorize VBus monitoring
	//启动USB堆栈以授权VBus监控
	udc_start();

	while (1) {
		touch_sensors_measure();
		
		if (!ioport_get_pin_level(USBC_INT_PIN)) {
			tcpc_alert(0); //必须
		}
		
		pd_run_state_machine(0); //必须
		
		if (display_change_requested)
		{
			if (display_screen >= (MAX_SCREENS - 1))
			{
				display_screen = 0;
			}
			else
			{
				display_screen++;
			}
			display_change_requested = 0;
			display_needs_update = 1;
		}
		
		if (display_needs_update)
		{
			ssd1306_write_data_n(display_buffer[display_screen], DISP_MEM_SIZE);//更新屏幕数据
			display_needs_update = 0;
		}
		
		delay_ms(2);
	}
}
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

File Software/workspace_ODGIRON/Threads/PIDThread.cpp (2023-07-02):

/*
 * PIDThread.cpp
 *
 *  Created on: 29 May 2020
 *      Author: Ralim
 */
#include "Threads.hpp"
#include <TipThermoModel.hpp>
#include "power.hpp"

static TickType_t powerPulseWaitUnit      = 25 * TICKS_100MS;      // 2.5 s
static TickType_t powerPulseDurationUnit  = (5 * TICKS_100MS) / 2; // 250 ms
TaskHandle_t      pidTaskNotification     = NULL;
uint32_t          currentTempTargetDegC   = 0; // Current temperature target in C
int32_t           powerSupplyWattageLimit = 0;
bool              heaterThermalRunaway    = false;

static int32_t getPIDResultX10Watts(int32_t tError);
static void    detectThermalRunaway(const int16_t currentTipTempInC, const int tError);
static void    setOutputx10WattsViaFilters(int32_t x10Watts);
int32_t getX10WattageLimits();

/* StartPIDTask function */
void doPIDTask() {
  /*
   * We take the current tip temperature & evaluate the next step for the tip
   * control PWM.
   */
  setTipX10Watts(0); // disable the output at startup

  currentTempTargetDegC = 0; // Force start with no output (off). If in sleep / soldering this will
                             // be over-ridden rapidly
  pidTaskNotification    = xTaskGetCurrentTaskHandle();
  uint32_t PIDTempTarget = 0;
  // Pre-seed the adc filters
  for (int i = 0; i < 128; i++) {
    osDelay(5);
    TipThermoModel::getTipInC(true);
    getInputVoltageX10();
  }
  int32_t x10WattsOut = 0;

	for (;;) {
		x10WattsOut = 0;
		// This is a call to block this thread until the ADC does its samples
		// 由ADC注入通道转换完成后的HAL_ADCEx_InjectedConvCpltCallback()函数向PIDTask发送的任务通知
		if (ulTaskNotifyTake(pdTRUE, 1000)) {
			// Do the reading here to keep the temp calculations churning along
			uint32_t currentTipTempInC = TipThermoModel::getTipInC(true);//瞬时采集温度
			PIDTempTarget = currentTempTargetDegC + systemSettings.balanceTempOffsetPositive - systemSettings.balanceTempOffsetnegative;	//目标温度
			//usb_printf("currentTipTempInC = %d  PIDTempTarget = %d \r\n", currentTipTempInC, PIDTempTarget);
			if (PIDTempTarget) {
				// Cap the max set point to 450C
				if (PIDTempTarget > (450)) {
					// Maximum allowed output
					PIDTempTarget = (450);
				}

				// Safety check that not aiming higher than current tip can measure
				if (PIDTempTarget > TipThermoModel::getTipMaxInC()) {
					PIDTempTarget = TipThermoModel::getTipMaxInC();
				}
				//tError = 目标温度 - 当前温度
				//那么tError可正可负，但，若是未插入烙铁，则当前温度为ADC最大值，tError也为负值
				//如何避免detectThermalRunaway()将此情况当作失控而触发保护?
				int32_t tError = PIDTempTarget - currentTipTempInC;
				detectThermalRunaway(currentTipTempInC, tError);

				tError = (float)tError /(100.0 / systemSettings.pidKp);
				x10WattsOut = getPIDResultX10Watts(tError);			///关键的一句
				//usb_printf("x10WattsOut = %d \r\n", x10WattsOut);
			} else {
				detectThermalRunaway(currentTipTempInC, 0);
			}
			// Secondary safety check to forcefully disable header when within ADC noise of top of ADC
			// 输入电压小于8V,或手柄温度大于70,或菜单页面停止加热时，也关闭PID输出, 7FFF = 32767
			if ( //!(tipState == TIP_HEATING || tipState == TIP_SLEEPING_TIME_OUT) ||
					getTipRawTemp(0) > (0x7FFF - 150) ||
					((getInputVoltageX10()/10) < 8) ||
					(getHandleTemperature(true)/10) > 70) {
				x10WattsOut = 0;
			}
			setOutputx10WattsViaFilters(x10WattsOut);	//通过过滤器
		} else {
			// ADC interrupt timeout
			setTipPWM(0, false);
		}
#ifdef DEBUG_UART_OUTPUT
    log_system_state(x10WattsOut);
#endif
	}
}

template <class T = int32_t> struct Integrator {
  T sum;

  T update(const T val, const int32_t inertia, const int32_t gain, const int32_t rate, const int32_t limit) {
    // Decay the old value. This is a simplified formula that still works with decent results
    // Ideally we would have used an exponential decay but the computational effort required
    // by exp function is just not justified here in respect to the outcome
	// 衰减旧值。这是一个简化的公式，仍然可以取得不错的结果
	// 理想情况下，我们会使用【指数衰减】功率曲线确实是指数衰减，但需要计算量
	// 通过 exp 函数在这里就结果而言是不合理的
    sum = (sum * (100 - (inertia / rate))) / 100;
    // Add the new value x integration interval ( 1 / rate)
    sum += (gain * val) / rate;

    // limit the output
    if (sum > limit)
      sum = limit;
    else if (sum < -limit)
      sum = -limit;

    return sum;
  }

  void set(T const val) { sum = val; }

  T get(bool positiveOnly = true) const { return (positiveOnly) ? ((sum > 0) ? sum : 0) : sum; }
};
int32_t getPIDResultX10Watts(int32_t setpointDelta) {
  static TickType_t          lastCall   = 0;
  static Integrator<int32_t> powerStore = {0};

  const int rate = 1000 / (xTaskGetTickCount() - lastCall);
  //int rate = 1000 / (xTaskGetTickCount() - lastCall);
  //usb_printf("rate = %d \r\n", rate);	// = 0

  lastCall       = xTaskGetTickCount();
  // Sandman note:
  // PID Challenge - we have a small thermal mass that we to want heat up as fast as possible but we don't
  // want to overshot excessively (if at all) the setpoint temperature. In the same time we have 'imprecise'
  // instant temperature measurements. The nature of temperature reading imprecision is not necessarily
  // related to the sensor (thermocouple) or DAQ system, that otherwise are fairly decent. The real issue	is
  // the thermal inertia. We basically read the temperature in the window between two heating sessions when
  // the output is off. However, the heater temperature does not dissipate instantly into the tip mass so
  // at any moment right after heating, the thermocouple would sense a temperature significantly higher than
  // moments later. We could use longer delays but that would slow the PID loop and that would lead to other
  // negative side effects. As a result, we can only rely on the I term but with a twist. Instead of a simple
  // integrator we are going to use a self decaying integrator that acts more like a dual I term / P term
  // rather than a plain I term. Depending on the circumstances, like when the delta temperature is large,
  // it acts more like a P term whereas on closing to setpoint it acts increasingly closer to a plain I term.
  // So in a sense, we have a bit of both.
  //																		 So there we go...

  // P = (Thermal Mass) x (Delta Temperature ) / 1sec, where thermal mass is in X10 J / °C and
  // delta temperature is in °C. The result is the power in X10 W needed to raise (or decrease!) the
  // tip temperature with (Delta Temperature ) °C in 1 second.
  // Note on powerStore. On update, if the value is provided in X10 (W) units then inertia shall be provided
  // in X10 (J / °C) units as well. Also, powerStore is updated with a gain of 2. Where this comes from: The actual
  // power CMOS is controlled by TIM3->CTR1 (that is software modulated - on/off - by TIM2-CTR4 interrupts). However,
  // TIM3->CTR1 is configured with a duty cycle of 50% so, in real, we get only 50% of the presumed power output
  // so we basically double the need (gain = 2) to get what we want.
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

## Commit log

2021-08-09 4 commit
    [0.87寸oled亚克力面板2021-0603_格式CAD2004.DWG, 0510-上壳_1353.STL, 0510-下壳_1446.STL]
2021-08-10 5 commit, 添加菜单滚动栏动画
2021-08-10 6 commit，修复重启进入DFU功能的USB无法识别
2021-08-11 7 commit，增加菜单栏迭代跟随运动，主页调温的衔接动效
2022-04-04 移除F103CBU6的固件
    [ODGRION原件清单及物料成本计算.xlsx, configuration.h]
2022-04-04 更新固件
    [configuration.h]
2022-04-24 添加校准目标温度可调功能
2022-04-27 添加温度失控保护
    [configuration.h]
2022-12-01 添加ODGIRON_20210624之前的相关文件
    [0.86o_led_96x32.SLDPRT, 0.87_oled.SLDPRT, 0.87寸oled亚克力面板2021-0603_格式CAD2004.DWG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]

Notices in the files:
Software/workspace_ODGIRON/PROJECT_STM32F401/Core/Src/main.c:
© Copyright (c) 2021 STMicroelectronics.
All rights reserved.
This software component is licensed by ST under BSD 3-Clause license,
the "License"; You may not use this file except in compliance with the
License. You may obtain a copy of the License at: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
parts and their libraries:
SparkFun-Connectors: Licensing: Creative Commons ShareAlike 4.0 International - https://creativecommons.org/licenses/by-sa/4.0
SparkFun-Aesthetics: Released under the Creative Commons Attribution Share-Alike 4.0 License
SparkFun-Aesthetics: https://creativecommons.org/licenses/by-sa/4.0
